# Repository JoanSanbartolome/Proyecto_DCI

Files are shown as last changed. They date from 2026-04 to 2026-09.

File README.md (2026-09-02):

# Proyecto de Diseño de PCB - STM32F746ZG






Este repositorio contiene el proyecto completo de diseño de circuito impreso (PCB) para una placa basada en el microcontrolador **STM32F746ZG**, abarcando esquemáticos, trazado de PCB (layout), archivos de fabricación, informe de diseño y una wiki técnica detallada.

---

## 📂 Estructura del Repositorio

```text
├── scr/            # Fuentes del proyecto en Altium Designer (.SchDoc, .PcbDoc, .PrjPCB, Librerías)
├── fabricacion/    # Archivos de producción (Gerber, BOM, Pick & Place, Stackup, PDF de esquemáticos)
├── informe/        # Código fuente LaTeX e imágenes del informe de diseño
├── Informe_Placa.pdf # Informe técnico final compilado en PDF
├── wiki/           # Base de conocimiento y documentación técnica estructurada
└── outputs/        # Documentos de análisis e investigación técnica intermedia
```

---

## ⚡ Especificaciones del Sistema

* **Microcontrolador:** STM32F746ZG (ARM Cortex-M7 con FPU)
* **Interfaces Periféricas:**
  * **Ethernet:** Interfaz RMII con PHY Ethernet y conector MagJack.
  * **USB:** USB OTG High-Speed / Full-Speed con pares diferenciales adaptados a 90 Ω.
  * **CAN Bus:** Transceptor CAN con protección ESD, filtro de modo común y terminación dividida (120 Ω).
  * **Memoria Flash SPI:** Memoria externa Quad-SPI con control de integridad de señal.
  * **Acondicionamiento Analógico:** Entradas ADC filtradas con amplificadores operacionales en buffer.

---

## 🛠️ Herramientas Utilizadas

* **CAD / EDA:** Altium Designer
* **Documentación Técnica:** LaTeX / Markdown
* **Control de Versiones:** Git & GitHub

---

## 📚 Wiki Técnica (`wiki/`)

La carpeta `wiki/` sirve como memoria de diseño e investigación técnica organizada en:

* **`core/`**: Arquitectura hardware, requerimientos del proyecto, reglas de layout/vias y restricciones de fabricación.
* **`peripherals/`**: Guías de diseño para Ethernet, CAN, USB, SPI y acondicionado analógico.
* **`protection/`**: Estrategias de protección ESD y sobretensión por periférico.
* **`theory/`**: Teoría de integridad de señal, desacoplo de la red PDN y guías de diseño PCB.

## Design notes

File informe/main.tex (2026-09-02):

% =============================================================
%  PREÁMBULO
% =============================================================

\documentclass[12pt,a4paper]{article}

% --- Codificación y fuente ---
\usepackage{lmodern}           % Estabiliza métricas base (fix glue units)
\usepackage[utf8]{inputenc}
\usepackage[T1]{fontenc}
\usepackage[spanish,es-tabla]{babel}
\usepackage{csquotes}  % Requerido por biblatex + babel

% --- Tipografía ---
\usepackage[sfdefault]{FiraSans}  % Fuente moderna sin conflictos con pgfplots
\usepackage{setspace}
\onehalfspacing

% --- Márgenes ---
\usepackage{geometry}
\geometry{
    a4paper,
    left=3cm,
    right=2.5cm,
    top=2.5cm,
    bottom=2.5cm,
    headheight=14.5pt  % Requerido por fancyhdr
}

% --- Matemáticas ---
\usepackage{amsmath}
\usepackage{amssymb}
\usepackage{amsthm}
\newtheorem{teorema}{Teorema}[section]
\newtheorem{definicion}{Definición}[section]

% --- Gráficos y figuras ---
\usepackage{graphicx}
\usepackage{float}
\usepackage{subcaption}
\usepackage{rotating}

% --- Tablas ---
\usepackage{tabularx}
\usepackage{booktabs}
\usepackage{array}
\usepackage{multirow}

% --- Código (Matlab) ---
\usepackage{listings}
\usepackage{xcolor}
\lstset{
    language=Matlab,
    basicstyle=\ttfamily\small,
    keywordstyle=\color{blue}\bfseries,
    commentstyle=\color{gray}\itshape,
    stringstyle=\color{orange},
    backgroundcolor=\color{lightgray!20},
    frame=single,
    breaklines=true,
    captionpos=b,
    showstringspaces=false
}

% --- Plots ---
\usepackage{pgfplots}
\pgfplotsset{compat=1.18}

% --- Miscelánea ---
\usepackage{enumerate}
\usepackage{eurosym}
\usepackage{ragged2e}

% --- Encabezados y pie de página ---
\usepackage{fancyhdr}
\pagestyle{fancy}
\fancyhf{}  % Limpia todos los campos
\fancyhead[L]{\small\itshape Diseño de Circuitos Impresos}
\fancyhead[R]{\small\itshape UPV · ETSIT}
\fancyfoot[C]{\thepage}
\renewcommand{\headrulewidth}{0.4pt}
\renewcommand{\footrulewidth}{0pt}

% --- Bibliografía ---
\usepackage[backend=biber]{biblatex}
\addbibresource{mybibliography.bib}

% --- Hipervínculos (siempre al final del preámbulo) ---
\usepackage[
    colorlinks = true,
    linkcolor  = {blue!60!black},
    citecolor  = {blue!60!black},
    urlcolor   = {blue!60!black}
]{hyperref}

% =============================================================

\begin{document}

% --- PORTADA ---
\begin{titlepage}
    \centering

    % Logo UPV
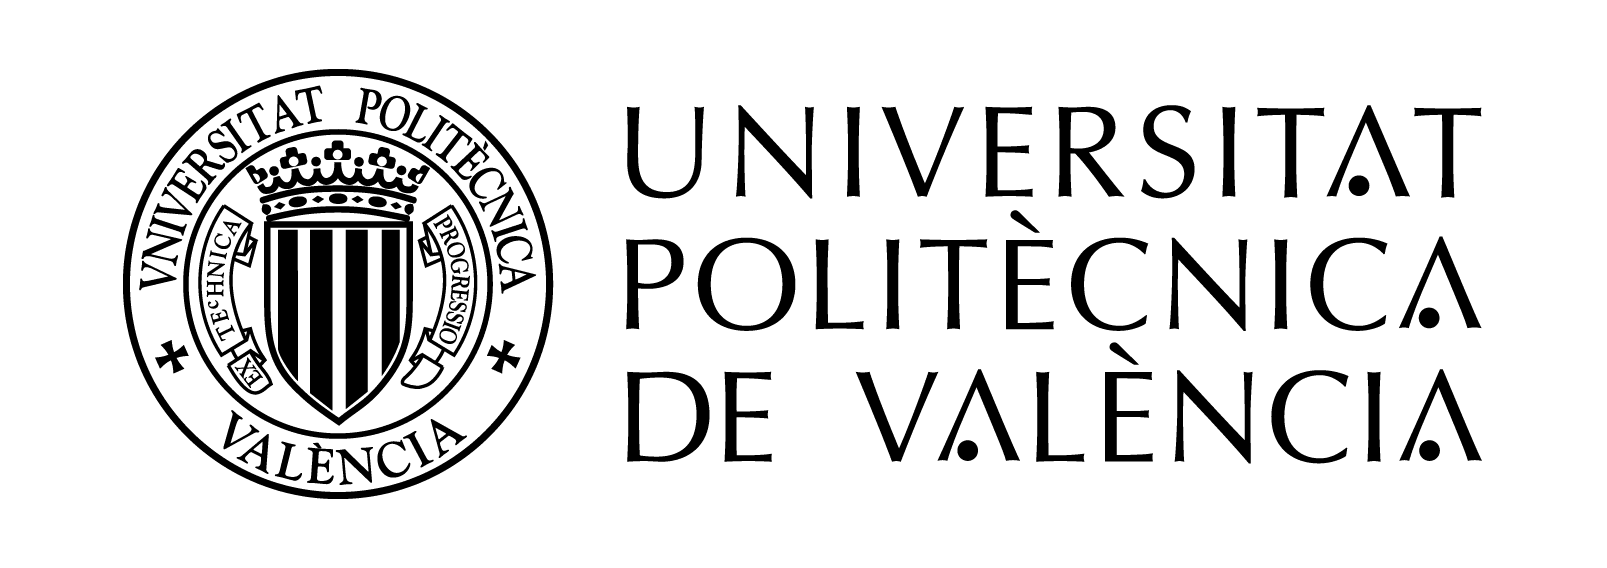
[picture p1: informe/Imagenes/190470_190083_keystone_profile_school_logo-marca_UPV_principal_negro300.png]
    

    \vspace{1.2cm}

    {\large Escuela Técnica Superior de Ingeniería de Telecomunicación}\\[0.2cm]
    {\large Universitat Politècnica de València}

    \vspace{1.8cm}
    \rule{\linewidth}{0.8pt}\\[0.5cm]

    {\Huge\bfseries Trabajo Final\\[0.4cm]
    Diseño de Circuitos Impresos}\\[0.5cm]

    \rule{\linewidth}{0.8pt}

    \vspace{1.2cm}

    {\large\itshape Informe de diseño}\\[0.3cm]
    {\normalsize Descripción del diseño, justificación de decisiones\\
    y resultados de simulación y análisis}

    \vfill

    \begin{tabular}{rl}
        \textbf{Autores:}         & Joan San Bartolomé \\
                                  & Raúl Tarazona      \\[0.6cm]
        \textbf{Asignatura:}      & Diseño de Circuitos Impresos \\[0.6cm]
        \textbf{Curso académico:} & 2025--2026
    \end{tabular}

    \vspace{1.5cm}

\end{titlepage}

% Activa encabezados a partir de aquí (la portada usa su propio estilo vacío)
\pagestyle{fancy}

\newpage
\thispagestyle{plain}  % ToC sin encabezado, solo número de página
\tableofcontents

\newpage

\section{Introducción}

El presente trabajo aborda el diseño, desarrollo y validación de una tarjeta de circuito impreso (PCB) funcional y fabricable basada en el microcontrolador de alto rendimiento STM32F746ZG. Tomando como referencia la plataforma de desarrollo comercial ST NUCLEO-F746ZG, el objetivo principal es adaptar y optimizar su arquitectura original en Altium Designer. Para ello, se simplifica el sistema mediante la eliminación de componentes redundantes y de evaluación (como el depurador integrado ST-LINK/V2-1) y se integran de forma nativa periféricos y acondicionadores de señal adaptados a aplicaciones específicas de control y conectividad.

Una de las decisiones clave de simplificación consiste en sustituir el programador/depurador ST-LINK embebido por un conector de depuración y programación SWD (Serial Wire Debug) estándar de 10 pines y paso de 100 mils. Esta decisión reduce sustancialmente el área de la placa y el consumo de potencia, permitiendo realizar la depuración mediante un programador externo o puenteando las señales desde el propio bloque ST-LINK de una placa NUCLEO comercial.

Entre los requisitos y capacidades integradas en este diseño se encuentran:
\begin{itemize}
    \item \textbf{Conectividad de red:} Interfaz Ethernet a través de un conector RJ45 de montaje inserción con LEDs de estado y magnéticos externos.
    \item \textbf{Comunicación serie y buses diferenciales:} Un puerto Micro-USB y dos transceptores CAN con red de terminación de línea dividida (Split Termination) integrada de forma permanente en el ruteado.
    \item \textbf{Adquisición de datos analógicos:} Dos canales de acondicionamiento de señal para entradas analógicas en rango de $0-10\text{ V}$, reduciéndolas y adaptándolas al rango de $0-3.3\text{ V}$ compatible con el ADC del microcontrolador.
    \item \textbf{Almacenamiento no volátil:} Una memoria SPI Flash de 2 MB para el almacenamiento de datos o firmware.
    \item \textbf{Expansión:} Un conector que expone un total de 20 líneas de E/S configurables por software: 16 de ellas son GPIO de propósito general dedicados y 2 corresponden a interfaces de comunicación serie multiplexadas (USART6 y USART7, que suman 4 líneas físicas de señal) que pueden operar alternativamente como GPIO o como puertos USART.
\end{itemize}

El diseño físico de la tarjeta se ha planteado en una tecnología de 4 capas para garantizar la integridad de las señales de alta velocidad (RMII de Ethernet, USB y CAN) y optimizar la Red de Distribución de Alimentación (PDN). Se configuran planos internos dedicados para masa (GND) y alimentación (PWR, este último partido para abastecer los diferentes niveles de tensión). El diseño cumple estrictamente las directivas de fabricación especificadas por el fabricante \textit{Lab Circuits}, restringiendo el grosor total de la placa a un máximo de $1.6\text{ mm}$ y aplicando reglas de ruteado originales para distanciar este prototipo del formato de evaluación de ST.

\section{Especificaciones de la placa}
La placa cuenta con distintos elementos que hacen que sea funcional para muchas situaciones y entornos, a continuación, se verán los diferentes elementos y funcionalidades de la placa a la vez que su construcción.

\subsection{Microcontrolador}

El cerebro de la tarjeta es el microcontrolador de muy alto rendimiento \textbf{STM32F746ZGT6}, basado en el núcleo ARM Cortex-M7 con FPU de 32 bits. Este dispositivo opera con un rango de tensión de alimentación de $1.7\text{ V}$ a $3.6\text{ V}$ y alcanza una frecuencia de reloj máxima de $216\text{ MHz}$. Dispone de $1\text{ MB}$ de memoria Flash, $320\text{ KB}$ de memoria SRAM (incluyendo memorias TCM de baja latencia) y se presenta en un encapsulado \textbf{LQFP144 de 144 pines}.

Para garantizar la estabilidad temporal del sistema, el diseño incorpora dos osciladores externos:
\begin{itemize}
    \item \textbf{Oscilador de Alta Velocidad (HSE):} Un cristal de cuarzo de $8\text{ MHz}$ conectado a los pines \texttt{PH0} y \texttt{PH1}, esencial para alimentar el PLL principal y derivar los relojes de alta precisión necesarios para Ethernet (RMII) y USB.
    \item \textbf{Oscilador de Baja Velocidad (LSE):} Un cristal de $32.768\text{ kHz}$ en los pines \texttt{PC14} y \texttt{PC15} dedicado al reloj de tiempo real (RTC) y estados de bajo consumo.
\end{itemize}

El arranque de la placa (\textit{boot}) se gestiona de forma manual mediante el pin \texttt{BOOT0}: por defecto se mantiene a nivel bajo ($0$) con una resistencia de pulso hacia abajo (\textit{pull-down}) de $10\text{ k}\Omega$ para iniciar desde la memoria Flash interna, pero cuenta con un pulsador físico que lo conecta a $3.3\text{ V}$ (a través de una resistencia en serie de $100\,\Omega$) para forzar el arranque en modo \textit{System Memory} (cargador de arranque por defecto de ST). La programación y depuración de la placa se realizan a través de un puerto SWD simplificado empleando los pines dedicados \texttt{PA13} (SWDIO) y \texttt{PA14} (SWCLK), además de la línea de reinicio activa a nivel bajo \texttt{NRST}.

\subsection{ADC y Acondicionamiento de Señal Analógica}

La placa incorpora dos canales independientes para la adquisición de señales analógicas industriales en un rango de $0-10\text{ V}$. Dado que el rango de entrada del ADC del microcontrolador está limitado a $0-3.3\text{ V}$ (tensión de referencia analógica), hemos diseñado una etapa de acondicionamiento para atenuar, filtrar y adaptar la impedancia de la señal.

\begin{figure}[H]
    \centering
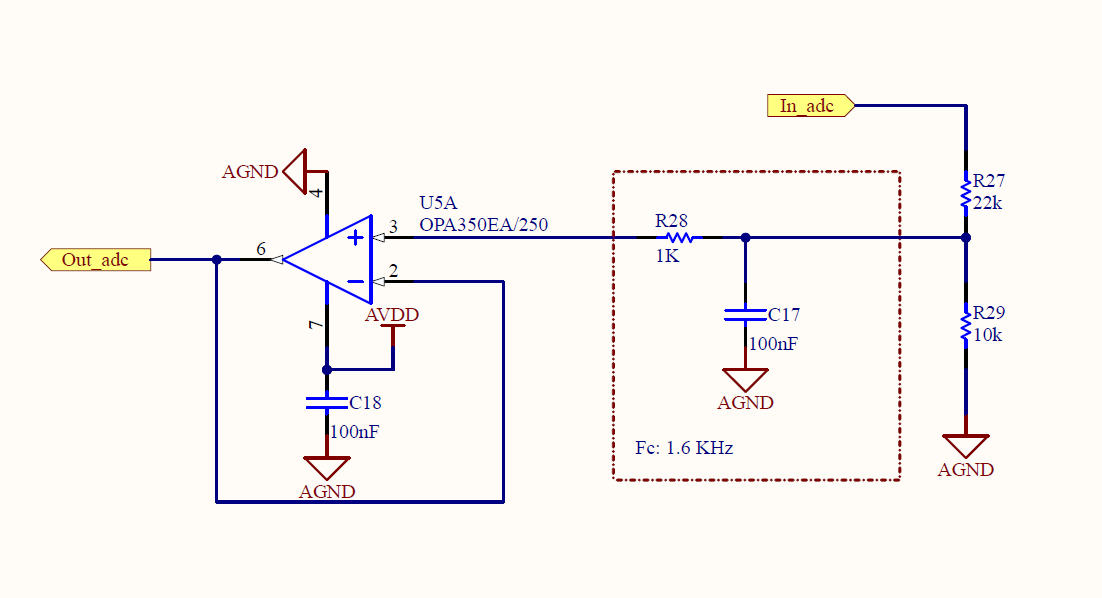
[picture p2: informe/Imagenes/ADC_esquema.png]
    
    \caption{Esquemático de la etapa de acondicionamiento analógico de entrada.}
    \label{fig:adc_esquema}
\end{figure}

El circuito de acondicionamiento de cada canal consta de las siguientes etapas:
\begin{enumerate}
    \item \textbf{Divisor de tensión atenuador:} Para adaptar la señal al rango del microcontrolador, hemos diseñado un divisor resistivo con $R_{18} = 22\text{ k}\Omega$ y $R_{19} = 10\text{ k}\Omega$. Este divisor atenúa la tensión máxima de entrada de $10\text{ V}$ a un valor seguro de $3.125\text{ V}$, protegiendo el pin de entrada y aprovechando el $95\%$ del rango dinámico del ADC.
    \item \textbf{Filtro paso bajo (Anti-aliasing):} Conectado a la entrada no inversora del amplificador operacional, este filtro RC pasivo está formado por $R_{20} = 1\text{ k}\Omega$ y $C_{12} = 100\text{ nF}$. Fija la frecuencia de corte en $f_c \approx 1.59\text{ kHz}$, adecuada para eliminar interferencias electromagnéticas y ruido de alta frecuencia de sensores industriales.
    \item \textbf{Buffer de adaptación de impedancia:} Se implementa mediante el amplificador operacional de alta precisión \textbf{OPA350EA/250} en configuración de seguidor de tensión (ganancia unidad). Al estar colocado tras el filtro, este buffer aprovecha la impedancia de entrada casi infinita de sus terminales para no cargar el filtro RC, ofreciendo a su vez una salida de muy baja impedancia idónea para alimentar el circuito de muestreo del ADC del microcontrolador ($R_{ADC} \approx 6\text{ k}\Omega$) sin errores de carga.
\end{enumerate}

Para evitar oscilaciones térmicas y consumos indeseados, el segundo canal del amplificador operacional (\texttt{U5B}), al no ser utilizado en este bloque jerárquico, se ha estabilizado conectándolo en modo seguidor con su pin no inversor unido a la masa analógica (\texttt{AGND}).

\subsubsection{Pines asignados para el ADC}

Las señales acondicionadas se conectan a los siguientes pines del microcontrolador:

\begin{table}[H]
\centering
\begin{tabular}{|c|c|l|}
\hline
\textbf{Señal} & \textbf{Pin MCU} & \textbf{Función del Periférico} \\ \hline
ADC\_CH1 & PB0 & Canal de conversión analógico-digital (ADC12\_IN8) \\ \hline
ADC\_CH2 & PB1 & Canal de conversión analógico-digital (ADC12\_IN9) \\ \hline
\end{tabular}
\caption{Asignación de pines para los canales analógicos.}
\label{tab:adc_pines}
\end{table}

\subsection{Interfaz de Comunicación CAN (Controller Area Network)}

El estándar CAN es un protocolo robusto de comunicación diferencial, idóneo para entornos industriales debido a su elevada inmunidad al ruido electromagnético. Hemos implementado en la placa dos nodos CAN independientes (\texttt{CAN1} y \texttt{CAN2}) utilizando una arquitectura jerárquica idéntica.

\begin{figure}[H]
    \centering
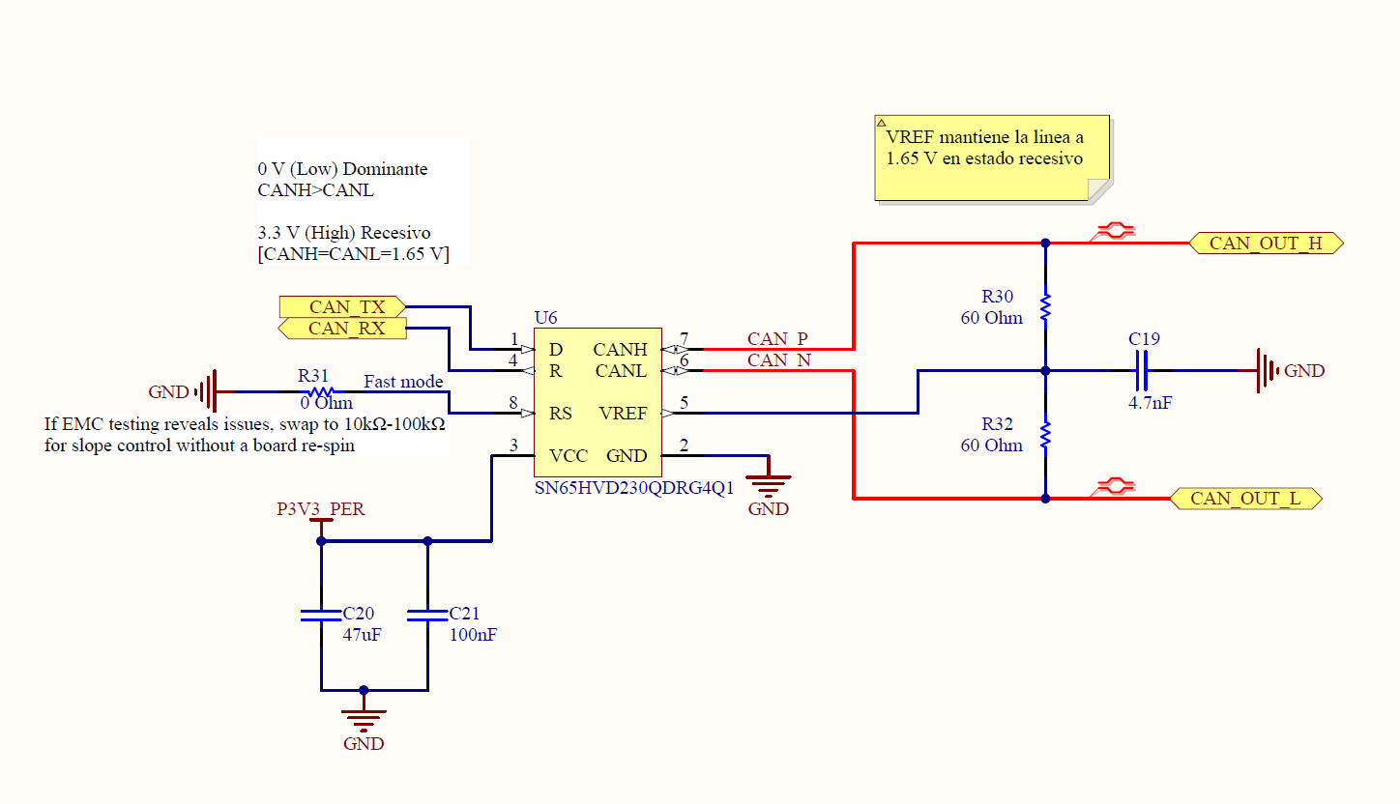
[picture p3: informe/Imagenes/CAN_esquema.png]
    
    \caption{Esquemático de la etapa del transceptor CAN e inmunidad contra ESD.}
    \label{fig:can_esquema}
\end{figure}

Para cada canal hemos tomado las siguientes decisiones de diseño de hardware:
\begin{enumerate}
    \item \textbf{Transceptor de baja potencia a $3.3\text{ V}$:} Hemos integrado el chip \textbf{SN65HVD230Q}, el cual opera directamente con la tensión lógica del microcontrolador ($3.3\text{ V}$), eliminando la necesidad de emplear desplazadores de nivel de tensión que habrían encarecido y complicado el ruteado.
    \item \textbf{Terminación de línea dividida permanente (Split Termination):} En lugar de una única resistencia de $120\,\Omega$, hemos implementado una terminación dividida integrada de forma fija y permanente por hardware, compuesta por dos resistencias de $60\,\Omega$ en serie y un condensador de $4.7\text{ nF}$ al nodo central de masa. Esta red actúa como un filtro paso bajo de modo común para disipar el ruido de alta frecuencia a tierra sin alterar la impedancia diferencial del bus. Cabe destacar que la terminación no es seleccionable ni desconectable mediante puentes (jumpers) o interruptores; es fija en el layout, lo que impone que esta tarjeta deba operar obligatoriamente en uno de los dos extremos físicos del bus CAN para evitar desadaptaciones de impedancia en la red.
    \item \textbf{Control de pendiente (RS Pin):} El pin de control de modo/pendiente (\texttt{RS}) del transceptor se conecta a masa a través de una resistencia de $0\,\Omega$ por defecto. Esto configura el transceptor en modo de alta velocidad (\textit{High-Speed Mode}). Sin embargo, la huella permite sustituir esta resistencia por un valor mayor ($10\text{ k}\Omega$ a $100\text{ k}\Omega$) para pasar a modo de control de pendiente y limitar la velocidad de transición de los flancos en caso de no cumplir con los ensayos de compatibilidad electromagnética (EMI).
    \item \textbf{Protección contra transitorios (ESD):} Hemos colocado un diodo de protección ESD bidireccional específico para CAN en encapsulado SOT-23 (\textbf{PESD2CAN}) lo más cerca posible del conector físico de salida para derivar descargas electrostáticas y transitorios directamente a la masa del sistema.
\end{enumerate}

\subsubsection{Pines asignados para el bus CAN}

La interfaz lógica entre el microcontrolador y los transceptores se realiza a través de las siguientes líneas:

\begin{table}[H]
\centering
\small
\begin{tabularx}{\textwidth}{|c|c|l|X|}
\hline
\textbf{Periférico} & \textbf{Pin MCU} & \textbf{Señal Lógica} & \textbf{Función} \\ \hline
\multirow{2}{*}{CAN1} & PD0 & CAN1\_RX & Recepción de datos lógicos del transceptor \\ \cline{2-4} 
                      & PD1 & CAN1\_TX & Transmisión de datos lógicos al transceptor \\ \hline
\multirow{2}{*}{CAN2} & PB5 & CAN2\_RX & Recepción de datos lógicos del transceptor \\ \cline{2-4} 
                      & PB6 & CAN2\_TX & Transmisión de datos lógicos al transceptor \\ \hline
\end{tabularx}
\caption{Asignación de pines de comunicación lógica para los controladores CAN.}
\label{tab:can_pines}
\end{table}

\subsection{Interfaz Micro-USB}

Hemos integrado un puerto Micro-USB de tipo AB (receptáculo \textbf{Molex 475900001}) para dotar a la tarjeta de conectividad de datos (USB 2.0 Full-Speed a $12\text{ Mbps}$) y permitir la alimentación del sistema a través del bus VBUS del host.

\begin{figure}[H]
    \centering
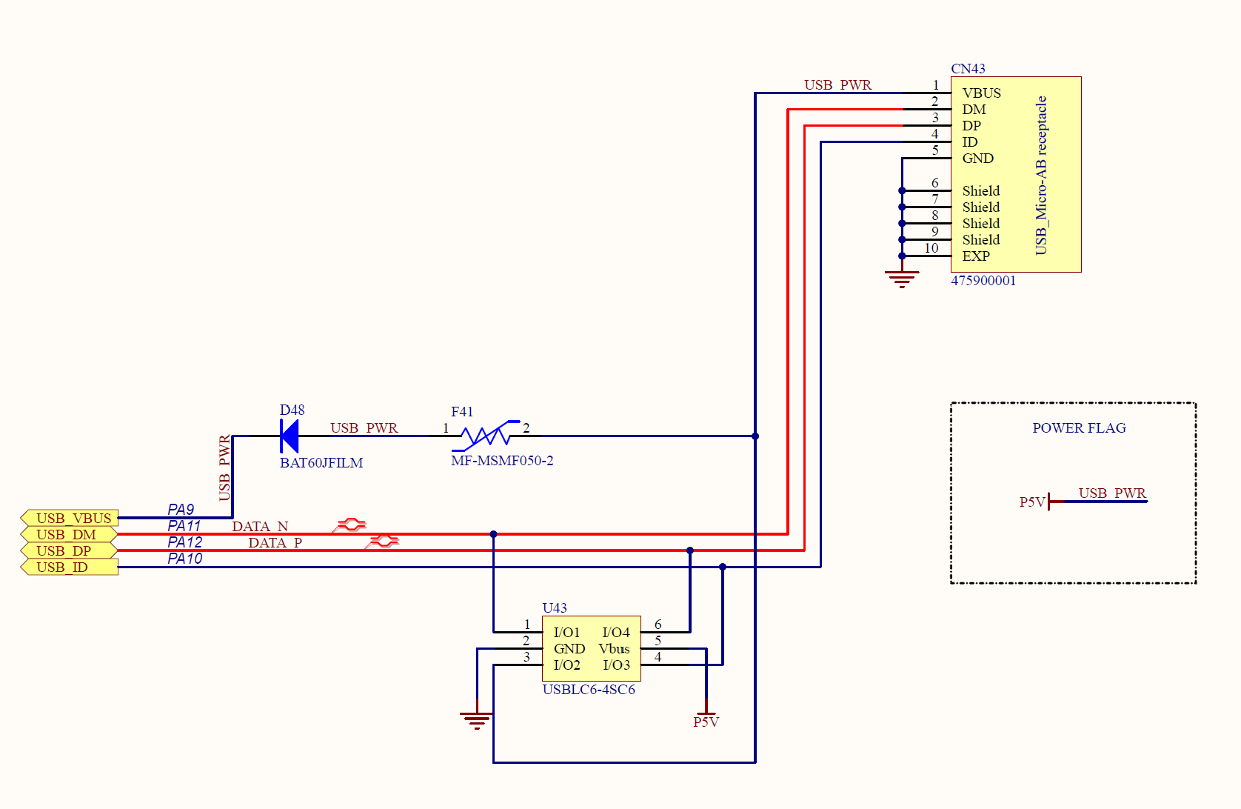
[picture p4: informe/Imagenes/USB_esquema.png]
    
    \caption{Esquemático de la etapa del conector USB con sus elementos de protección y filtrado.}
    \label{fig:usb_esquema}
\end{figure}

El diseño físico y eléctrico de esta interfaz se fundamenta en las siguientes decisiones de hardware:
\begin{enumerate}
    \item \textbf{Adaptación de impedancia diferencial:} Las líneas de datos $D+$ y $D-$ se rutan como par diferencial directamente desde el conector hacia los pines del microcontrolador, sin resistencias serie de terminación externas. Hemos aprovechado que el transceptor Full-Speed integrado en el microcontrolador STM32F746ZGT6 cuenta con una impedancia de salida adaptada por hardware. El par se ha diseñado para presentar una impedancia diferencial de \textbf{$90\,\Omega \pm 10$\%}.
    \item \textbf{Protección contra descargas electrostáticas (ESD):} Para proteger las líneas de datos de transitorios de alta velocidad sin degradar la señal por efecto capacitivo, hemos colocado el circuito integrado de capacitancia ultra-baja ($C_{in} \approx 1\text{ pF}$) \textbf{USBLC6-4SC6} lo más cerca posible del conector físico. Las pistas del par de datos se rutan pasando directamente a través de las patillas del integrado para evitar stubs en el diseño de la pista.
    \item \textbf{Seguridad de alimentación (VBUS):} La entrada de alimentación desde el puerto USB (\texttt{USB\_PWR}) cuenta con dos niveles de protección activa:
        \begin{itemize}
            \item Un fusible rearmable PTC de $0.5\text{ A}$ (\textbf{MF-MSMF050-2}) para proteger al puerto del host frente a cortocircuitos o sobrecorrientes en nuestra placa.
            \item Un diodo Schottky \textbf{BAT60JFILM} que previene corrientes de retorno inversas hacia el host cuando la placa se alimenta mediante otra fuente de alimentación externa.
        \end{itemize}
    \item \textbf{Sensado de VBUS:} La línea VBUS se conecta al pin de entrada analógica/digital \texttt{PA9} del microcontrolador a través de una resistencia en serie de $10\text{ k}\Omega$. Aprovechando que el pin \texttt{PA9} es tolerante a $5\text{ V}$, esta resistencia actúa como un limitador de corriente para salvaguardar la entrada ante picos de tensión o transitorios en la línea de alimentación USB, permitiendo al firmware detectar la presencia del host y gestionar el stack de comunicaciones de forma dinámica.
\end{enumerate}

\subsubsection{Cálculo de Impedancia del Par Diferencial USB}

Para asegurar la integridad de la señal en el bus de datos USB, hemos realizado el cálculo geométrico del par diferencial utilizando el motor de cálculo \textit{SIMBEOR} integrado en el gestor de pila de capas (\textit{Layer Stack Manager}) de Altium Designer. 

Tomando como base la pila de capas de $1.6\text{ mm}$ de \textit{Lab Circuits}, los parámetros geométricos y eléctricos que definen el par diferencial de datos USB ($90\,\Omega$) se muestran en la Tabla~\ref{tab:usb_diffpair_params}:

\begin{table}[H]
\centering
\small
\begin{tabular}{|l|c|}
\hline
\textbf{Parámetro del Par Diferencial} & \textbf{Valor de Diseño} \\ \hline
Impedancia Objetivo ($Z_{diff}$) & $90\,\Omega$ \\ \hline
Tolerancia de Diseño & $15$\% \\ \hline
Ancho de Pista ($W1$ / $W2$) & $0.19\text{ mm}$ ($\approx 7.5\text{ mils}$) \\ \hline
Separación de Pistas (Gap, $G$) & $0.15\text{ mm}$ ($\approx 6\text{ mils}$) \\ \hline
Grosor de la Máscara de Soldadura ($C1$ / $C2$) & $0.0254\text{ mm}$ ($1\text{ mil}$) \\ \hline
\textbf{Impedancia Diferencial Calculada ($Z_{diff}$)} & $\mathbf{94.91\,\Omega}$ \\ \hline
Desviación de Impedancia Obtenida & $5.46$\% (dentro de límites) \\ \hline
Retardo de Propagación (Delay) & $5.90\text{ ns/m}$ \\ \hline
\end{tabular}
\caption{Parámetros de diseño calculados para el par diferencial USB de 90 Ohm.}
\label{tab:usb_diffpair_params}
\end{table}

\subsubsection{Pines asignados para el puerto USB}

El mapeo de pines entre el microcontrolador y el conector USB se detalla a continuación:

\begin{table}[H]
\centering
\small
\begin{tabularx}{\textwidth}{|c|c|l|X|}
\hline
\textbf{Señal} & \textbf{Pin MCU} & \textbf{Señal Lógica} & \textbf{Función del Periférico} \\ \hline
USB\_VBUS & PA9 & OTG\_FS\_VBUS & Entrada de detección de presencia de tensión de VBUS \\ \hline
USB\_ID & PA10 & OTG\_FS\_ID & Línea de detección de modo Host/Device (OTG) \\ \hline
USB\_DM & PA11 & OTG\_FS\_DM & Línea de datos diferencial negativa (D-) \\ \hline
USB\_DP & PA12 & OTG\_FS\_DP & Línea de datos diferencial positiva (D+) \\ \hline
\end{tabularx}
\caption{Asignación de pines para la interfaz Micro-USB.}
\label{tab:usb_pines}
\end{table}

\subsection{Sistema de Alimentación y Red de Distribución de Potencia (PDN)}

La tarjeta se alimenta primariamente a través del puerto Micro-USB ($5\text{ V}$). Dado que la electrónica principal (núcleo del microcontrolador, transceptores y periféricos) funciona a un nivel nominal de $3.3\text{ V}$, hemos implementado una etapa de regulación lineal y una red de desacoplo distribuida (PDN) para asegurar el suministro limpio y estable de energía.

\begin{figure}[H]
    \centering
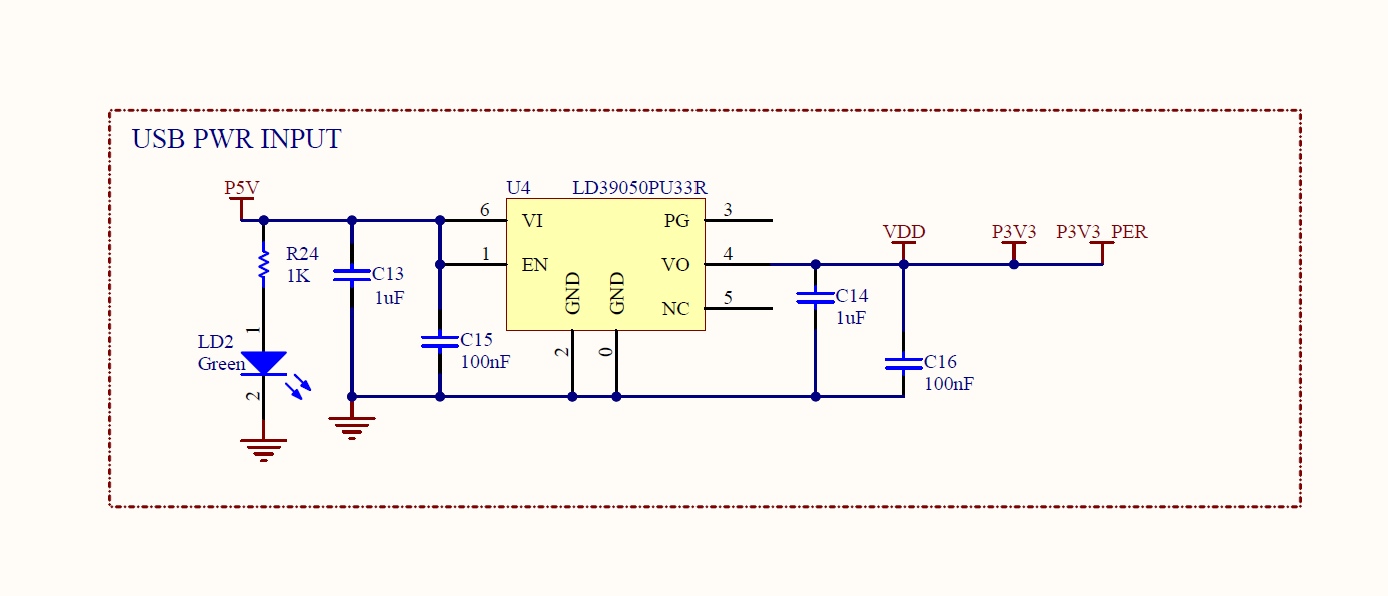
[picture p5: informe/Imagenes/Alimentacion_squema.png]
    
    \caption{Esquema de la etapa del regulador LDO de 3.3V y filtrado de alimentación.}
    \label{fig:alimentacion_esquema}
\end{figure}

Las decisiones de diseño tomadas para la red de alimentación son las siguientes:
\begin{enumerate}
    \item \textbf{Regulador LDO de alta eficiencia:} Hemos seleccionado el regulador de bajo descarte (LDO) \textbf{LD39050PU33R} de STMicroelectronics en encapsulado DFN-6, capaz de suministrar hasta $500\text{ mA}$ con una excelente relación de rechazo al rizado (PSRR). Este regulador incorpora una patilla de \textit{Power Good} (PG) para verificar la correcta estabilidad de la tensión y un pin de habilitación (\texttt{EN}) para control lógico. Su salida está estabilizada mediante una red de condensadores de $1\,\mu\text{F}$ y $100\text{ nF}$.
    \item \textbf{Desacoplo local del microcontrolador:} Para minimizar la inductancia del bucle de retorno y atenuar el ruido de conmutación de alta frecuencia, hemos colocado un condensador de desacoplo cerámico de $100\text{ nF}$ (encapsulado 0402) inmediatamente adyacente a cada uno de los 12 pines de alimentación digital \texttt{VDD} del microcontrolador.
    \item \textbf{Condensadores de almacenamiento masivo (Bulk):} Para responder ante transitorios de corriente rápidos del núcleo a $216\text{ MHz}$, hemos distribuido estratégicamente condensadores bulk en los extremos de la placa: un condensador de $4.7\,\mu\text{F}$ en las proximidades del pin 95 y otro de $10\,\mu\text{F}$ (X5R, 0805) junto al pin 72.
    \item \textbf{Regulación interna del núcleo (VCAP):} El regulador interno de $1.2\text{ V}$ para el núcleo digital del microcontrolador requiere estabilidad externa obligatoria. Para ello, hemos conectado dos condensadores cerámicos de bajo ESR de $2.2\,\mu\text{F}$ desde los pines dedicados \texttt{VCAP\_1} y \texttt{VCAP\_2} directamente a masa.
    \item \textbf{Aislamiento del dominio analógico ($V_{DDA}$ / $V_{REF+}$):} Para evitar el acoplamiento de ruido digital de alta frecuencia en las medidas del ADC, hemos aislado la alimentación analógica mediante una perla de ferrita de muy baja resistencia en continua (\textbf{Murata BLM18PG121SN1D}), acompañada de un desacoplo local de $1\,\mu\text{F}$ y $100\text{ nF}$. La baja DCR ($< 50\text{ m}\Omega$) garantiza una caída de tensión insignificante ($< 0.15\text{ mV}$), preservando la precisión de las lecturas analógicas.
\end{enumerate}

\subsubsection{Pines de alimentación del microcontrolador}

La distribución física de las patillas de alimentación y masa del microcontrolador STM32F746ZGT6 se describe en la siguiente tabla:

\begin{table}[H]
\centering
\small
\begin{tabularx}{\textwidth}{|l|c|X|}
\hline
\textbf{Dominio de Potencia} & \textbf{Símbolo Pin} & \textbf{Pines Físicos (LQFP144)} \\ \hline
Alimentación Digital & VDD & 16, 30, 39, 52, 62, 72, 84, 95, 108, 121, 131, 144 \\ \hline
Masa Común & VSS & 15, 31, 38, 51, 61, 71, 83, 94, 107, 120, 130, 143 \\ \hline
Alimentación Analógica & VDDA & 33 \\ \hline
Masa Analógica & VSSA & 32 \\ \hline
Tensión de Referencia Analógica & VREF+ / VREF- & 35 / 34 \\ \hline
Alimentación de Batería & VBAT & 6 \\ \hline
Condensadores del Regulador Núcleo & VCAP\_1 / VCAP\_2 & 71 / 106 \\ \hline
\end{tabularx}
\caption{Pines físicos de alimentación y referencia en encapsulado LQFP144.}
\label{tab:alimentacion_pines}
\end{table}

\subsection{Interfaz de Red Ethernet}

Hemos incorporado conectividad Ethernet 10/100Base-TX mediante el uso del microcontrolador en modo MAC y un transceptor de capa física (PHY) externo de bajo consumo \textbf{LAN8742A-CZ-TR} en encapsulado QFN-24. La conexión física se realiza a través de un conector RJ45 con transformador magnético integrado (\textbf{KRJ-CB4.2GYZNL}).

El diseño de esta etapa se basa en las siguientes decisiones técnicas de hardware:
\begin{enumerate}
    \item \textbf{Uso de interfaz RMII (Reduced Media Independent Interface):} Para reducir el número de patillas necesarias en el microcontrolador de 17 (modo MII) a 9, hemos configurado la comunicación en modo RMII. La señal de reloj de referencia de $50\text{ MHz}$ (\texttt{RMII\_REF\_CLK}) es generada por el propio PHY a partir de un cristal local de $25\text{ MHz}$ y se introduce en el pin \texttt{PA1} del microcontrolador.
    \item \textbf{Aislamiento galvánico bajo los magnéticos:} Para evitar el acoplamiento de ruido electromagnético de modo común procedente de la línea de red cableada hacia los planos internos de alimentación y masa de la placa, hemos definido un área de exclusión de cobre (\textit{keep-out}) en todas las capas de la PCB por debajo de la zona ocupada por los transformadores magnéticos del conector RJ45.
    \item \textbf{Protección contra transitorios:} Hemos colocado un array de diodos de capacitancia ultra-baja \textbf{USBLC6-4SC6} adyacente a las líneas diferenciales del conector para filtrar picos de ESD antes de que alcancen el lado del transceptor.
\end{enumerate}

\subsubsection{Cálculo de Impedancia del Par Diferencial Ethernet}

Las líneas del bus MDI que enlazan el transceptor PHY con el conector RJ45 (\texttt{TX+/TX-} y \texttt{RX+/RX-}) requieren un control de impedancia diferencial de **$100\,\Omega$**. Hemos calculado la geometría del par en base a la pila de capas de $1.6\text{ mm}$ de \textit{Lab Circuits} utilizando el motor de cálculo \textit{SIMBEOR} de Altium Designer. Los valores resultantes se detallan en la Tabla~\ref{tab:ethernet_diffpair_params}:

\begin{table}[H]
\centering
\small
\begin{tabular}{|l|c|}
\hline
\textbf{Parámetro del Par Diferencial} & \textbf{Valor de Diseño} \\ \hline
Impedancia Objetivo ($Z_{diff}$) & $100\,\Omega$ \\ \hline
Tolerancia de Diseño & $10$\% \\ \hline
Ancho de Pista ($W1$ / $W2$) & $0.182\text{ mm}$ ($\approx 7.2\text{ mils}$) \\ \hline
Separación de Pistas (Gap, $G$) & $0.180\text{ mm}$ ($\approx 7.1\text{ mils}$) \\ \hline
Grosor de la Máscara de Soldadura ($C1$ / $C2$) & $0.0254\text{ mm}$ ($1\text{ mil}$) \\ \hline
\textbf{Impedancia Diferencial Calculada ($Z_{diff}$)} & $\mathbf{99.99\,\Omega}$ \\ \hline
Desviación de Impedancia Obtenida & $0.01$\% \\ \hline
Retardo de Propagación (Delay) & $5.91\text{ ns/m}$ \\ \hline
\end{tabular}
\caption{Parámetros de diseño calculados para el par diferencial Ethernet de 100 Ohm.}
\label{tab:ethernet_diffpair_params}
\end{table}

\subsubsection{Pines asignados para el bus Ethernet}

Las señales lógicas del bus de control y datos RMII están distribuidas de acuerdo con la siguiente tabla:

\begin{table}[H]
\centering
\small
\begin{tabularx}{\textwidth}{|l|c|X|}
\hline
\textbf{Señal RMII} & \textbf{Pin MCU} & \textbf{Función de la Señal} \\ \hline
RMII\_REF\_CLK & PA1 & Reloj de referencia de 50 MHz para sincronización \\ \hline
RMII\_MDIO & PA2 & Gestión de datos bidireccional (SMI) \\ \hline
RMII\_MDC & PC1 & Reloj de la interfaz de gestión (SMI) \\ \hline
RMII\_CRS\_DV & PA7 & Detección de portadora y validación de datos recibidos \\ \hline
RMII\_RXD0 & PC4 & Línea 0 de recepción de datos \\ \hline
RMII\_RXD1 & PC5 & Línea 1 de recepción de datos \\ \hline
RMII\_TX\_EN & PG11 & Habilitación de transmisión de datos \\ \hline
RMII\_TXD0 & PG13 & Línea 0 de transmisión de datos \\ \hline
RMII\_TXD1 & PB13 & Línea 1 de transmisión de datos \\ \hline
nRST (PHY) & Pin 25 & Línea de reinicio por hardware del microcontrolador (NRST) \\ \hline
\end{tabularx}
\caption{Asignación de pines para la interfaz Ethernet en modo RMII.}
\label{tab:ethernet_pines}
\end{table}

\subsection{Conectores}
Además de las interfaces de comunicación específicas, hemos integrado conectores de expansión y terminales de conexión externa para interactuar con señales analógicas y digitales del sistema:

\begin{enumerate}
    \item \textbf{Conector de Expansión General (CN41):} Se trata de un conector macho de cabezal de $18\times2$ vías (paso de $2.54\,\text{mm}$) que expone un total de 20 líneas de E/S configurables por software. Analizando detalladamente el esquemático, se observa que este puerto proporciona 16 líneas de propósito general (GPIO) dedicadas (puertos C, D y G) y 2 interfaces de comunicación serie multiplexadas (USART6 y USART7, que ocupan un total de 4 líneas físicas de señal: TX/RX de cada una). Estas 4 líneas se pueden utilizar alternativamente como puertos serie o como líneas GPIO de entrada/salida convencionales según la configuración del firmware.
    \item \textbf{Conector de Depuración SWD (CN42):} Un cabezal de $6\times1$ vías utilizado para la programación y depuración del STM32F746ZG, exponiendo las líneas de depuración esenciales (SWCLK, SWDIO, SWO y el pin de reinicio NRST).
    \item \textbf{Terminales de Entrada Analógica (J41):} Un bloque de bornes de tornillo Weidmüller, modelo \textbf{1845040000} (paso de $3.50\,\text{mm}$ y entrada a $90^\circ$), que proporciona una conexión segura para las dos entradas analógicas acondicionadas de $0-10\,\text{V}$.
    \item \textbf{Conectores de Bus CAN (J42 y J43):} Conectores macho de 2 pines JST tipo \textbf{B2B-EH-A(LF)(SN)} para las conexiones físicas de los buses de comunicación CAN1 y CAN2.
\end{enumerate}

\subsubsection{Estrategia de Protección de Entradas/Salidas}
Para garantizar la inmunidad del microcontrolador frente a eventos externos de sobretensión y descargas electrostáticas (ESD), hemos diseñado e implementado un esquema de protección multietapa para todas las líneas de entrada y salida expuestas:
\begin{itemize}
    \item \textbf{Protección ESD Primaria (TVS Diodes):} Inmediatamente después del conector físico, hemos colocado matrices de diodos de supresión de tensiones transitorias (TVS) de 4 canales bidireccionales, modelo \textbf{ESDA6V1BC6} (D46, D47, D48 y D49). Estos dispositivos poseen una tensión de ruptura de $6.1\,\text{V}$, ideal para proteger pines tolerantes a $5\,\text{V}$ sin distorsionar señales de datos. Su ubicación física adyacente al conector y su baja inductancia de conexión a masa aseguran que los transitorios se deriven a tierra de forma instantánea.
    \item \textbf{Protección de Línea CAN:} Los puertos J42 y J43 disponen de diodos de protección TVS específicos de bus CAN de alta inmunidad y baja capacitancia modelo \textbf{PESD2CANFD24V-TR} (D44 y D45), situados en paralelo con las líneas diferenciales CAN\_H y CAN\_L.
    \item \textbf{Limitación de Corriente Secundaria (Resistencias Serie):} Entre las matrices TVS y los pines de entrada del microcontrolador, hemos introducido resistencias de protección en serie. Para las líneas de propósito general expuestas en CN41, hemos seleccionado resistencias de $100\,\Omega$ (R58 a R65 para el puerto D, y R69 a R73 para los puertos G/C). Estas resistencias limitan la corriente transitoria residual que pudiera llegar al microcontrolador a un nivel seguro inferior al límite de conducción de los diodos de fijación (clamping diodes) internos del STM32F746ZG ($I_{IN} < 10\,\text{mA}$).
    \item \textbf{Líneas de Depuración SWD:} Las señales del conector CN42 (SWCLK, SWDIO, SWO y NRST) se conectan al MCU mediante resistencias en serie de $22\,\Omega$ (R43, R44, R45 y R46), las cuales reducen sobreoscilaciones (overshoot/undershoot) y previenen reflexiones de alta frecuencia causadas por la impedancia de los cables de programación.
\end{itemize}

La topología de ruteado implementada respeta estrictamente la secuencia física: \textbf{[Conector Exterior]} $\rightarrow$ \textbf{[Diodo TVS ESDA6V1BC6 / PESD2CANFD]} $\rightarrow$ \textbf{[Resistencia Serie]} $\rightarrow$ \textbf{[Pin del MCU]}.

\subsubsection{Asignación de Pines del Conector General (CN41)}

La Tabla~\ref{tab:conectores_pines} muestra el mapeo detallado de cada pin del conector CN41, incluyendo las señales de alimentación y tierra correspondientes:

\begin{table}[H]
\centering
\small
\begin{tabularx}{\textwidth}{|X|c|c|X|}
\hline
\multicolumn{2}{|c|}{\textbf{LADO IMPAR (Izquierda)}} & \multicolumn{2}{c|}{\textbf{LADO PAR (Derecha)}} \\ \hline
\textbf{Señal del Esquema (Pin MCU)} & \textbf{Pin} & \textbf{Pin} & \textbf{Señal del Esquema (Pin MCU)} \\ \hline
GND & 1 & 2 & GND \\ \hline
P5V & 3 & 4 & P5V \\ \hline
P3V3 & 5 & 6 & P3V3 \\ \hline
GND & 7 & 8 & GND \\ \hline
PinG4 (PG4) & 9 & 10 & PinC6 (PC6) \\ \hline
PinG5 (PG5) & 11 & 12 & PinG8 (PG8) \\ \hline
GND & 13 & 14 & GND \\ \hline
PinG2 (PG2) & 15 & 16 & PinG7 (PG7) \\ \hline
PinG3 (PG3) & 17 & 18 & PinG6 (PG6) \\ \hline
PinD14 (PD14) & 19 & 20 & PinD11 (PD11) \\ \hline
GND & 21 & 22 & GND \\ \hline
PinD15 (PD15) & 23 & 24 & PinD10 (PD10) \\ \hline
PinD12 (PD12) & 25 & 26 & PinD9 (PD9) \\ \hline
PinD13 (PD13) & 27 & 28 & PinD8 (PD8) \\ \hline
GND & 29 & 30 & GND \\ \hline
USART7\_TX (PE8) & 31 & 32 & USART6\_TX (PG14) \\ \hline
USART7\_RX (PE7) & 33 & 34 & USART6\_RX (PG9) \\ \hline
GND & 35 & 36 & GND \\ \hline
\end{tabularx}
\caption{Distribución de pines del conector de expansión general (CN41) y su disposición de doble fila simétrica.}
\label{tab:conectores_pines}
\end{table}

\subsection{Memoria Flash}
Para el almacenamiento de firmware auxiliar, archivos de configuración o parámetros no volátiles del sistema, hemos incorporado una memoria Flash externa de tipo SPI NOR de $4\,\text{Mbit}$ ($512\,\text{KB}$), modelo \textbf{SST25VF040B-50-4I-S2AF} (encapsulado SOIC-8). Este chip se comunica con el microcontrolador a través del bus serie síncrono SPI2.

\subsubsection{Criterios de Diseño para la Integridad de la Señal SPI}
Debido a la alta frecuencia de conmutación del bus SPI (que puede operar hasta $50\,\text{MHz}$), hemos tomado las siguientes precauciones en el diseño del circuito:
\begin{itemize}
    \item \textbf{Amortiguación del Reloj (SCK):} Hemos colocado una resistencia amortiguadora en serie de $33\,\Omega$ (R32) en la línea de reloj (SPI\_CLK / SCK), ubicada en la cercanía física del microcontrolador (emisor). Esto permite controlar la impedancia de salida del driver, reducir la velocidad de subida del flanco (slew rate) y prevenir rebotes o sobreoscilaciones destructivas que podrían causar falsas transiciones de reloj en la memoria.
    \item \textbf{Resistencias de Pull-Up en Control:} Hemos colocado resistencias de pull-up de $10\,\text{k}\Omega$ a la línea de $3.3\,\text{V}$ (R31) en las líneas de control activas a nivel bajo: \textbf{CE\#} (Chip Enable), \textbf{WP\#} (Write Protect) y \textbf{HOLD\#} (Hold). Estas resistencias de pull-up aseguran que durante el arranque del microcontrolador (cuando sus pines se encuentran en alta impedancia), la memoria permanezca deshabilitada y protegida contra cualquier escritura o borrado accidental.
    \item \textbf{Desacoplo local:} Hemos colocado un condensador de desacoplo de $100\,\text{nF}$ (C61) en paralelo al terminal de alimentación VDD (Pin 8) a masa, ubicado lo más próximo posible al integrado.
\end{itemize}

La asignación de pines y conexiones físicas para la memoria Flash SPI se detallan en la Tabla~\ref{tab:flash_pines}:

\begin{table}[H]
\centering
\small
\begin{tabularx}{\textwidth}{|l|c|c|X|}
\hline
\textbf{Señal del Esquema} & \textbf{Pin Memoria (SOIC-8)} & \textbf{Pin MCU} & \textbf{Descripción y Detalles de Diseño} \\ \hline
SPI\_CS / CE\# & Pin 1 & PB12 & Habilitación de chip (Chip Enable). Dispone de un pull-up de $10\,\text{k}\Omega$ a 3.3V. \\ \hline
SPI\_MISO / SO & Pin 2 & PB14 & Salida de datos serie (Serial Data Output). Conexión directa a MISO del bus SPI2. \\ \hline
WP\# & Pin 3 & -- & Entrada de protección contra escritura. Conectada a +3.3 V mediante pull-up de $10\,\text{k}\Omega$. \\ \hline
GND / VSS & Pin 4 & -- & Terminal de referencia de masa. \\ \hline
SPI\_MOSI / SI & Pin 5 & PB15 & Entrada de datos serie (Serial Data Input). Conexión directa a MOSI del bus SPI2. \\ \hline
SPI\_CLK / SCK & Pin 6 & PB10 & Reloj serie (Serial Clock). Conectado mediante resistencia amortiguadora serie de $33\,\Omega$. \\ \hline
HOLD\# & Pin 7 & -- & Entrada de pausa temporal de bus. Conectada a +3.3 V mediante pull-up de $10\,\text{k}\Omega$. \\ \hline
VDD & Pin 8 & -- & Alimentación a +3.3 V, desacoplada localmente con condensador cerámico de $100\,\text{nF}$. \\ \hline
\end{tabularx}
\caption{Mapeo de pines y criterios de conexión para la memoria Flash SPI externa SST25VF040B.}
\label{tab:flash_pines}
\end{table}

\subsection{Distribución y Emplazado de Componentes (Placement)}

Para optimizar el comportamiento térmico, electromagnético y la integridad de las señales en la placa, hemos diseñado una distribución espacial (placement) basada en la segregación estricta de componentes por bloques funcionales. El emplazado de componentes respeta el flujo natural de las señales lógicas y de potencia, minimizando la longitud de las trazas críticas y evitando el acoplamiento cruzado de ruido (crosstalk) entre bloques de alta frecuencia, circuitos analógicos de precisión y convertidores de potencia.

En la Figura~\ref{fig:layout_placement} se muestra el plano de distribución y emplazado físico de componentes en el plano de la serigrafía de ensamblaje (Assembly Drawing) de la PCB:

\begin{figure}[H]
    \centering
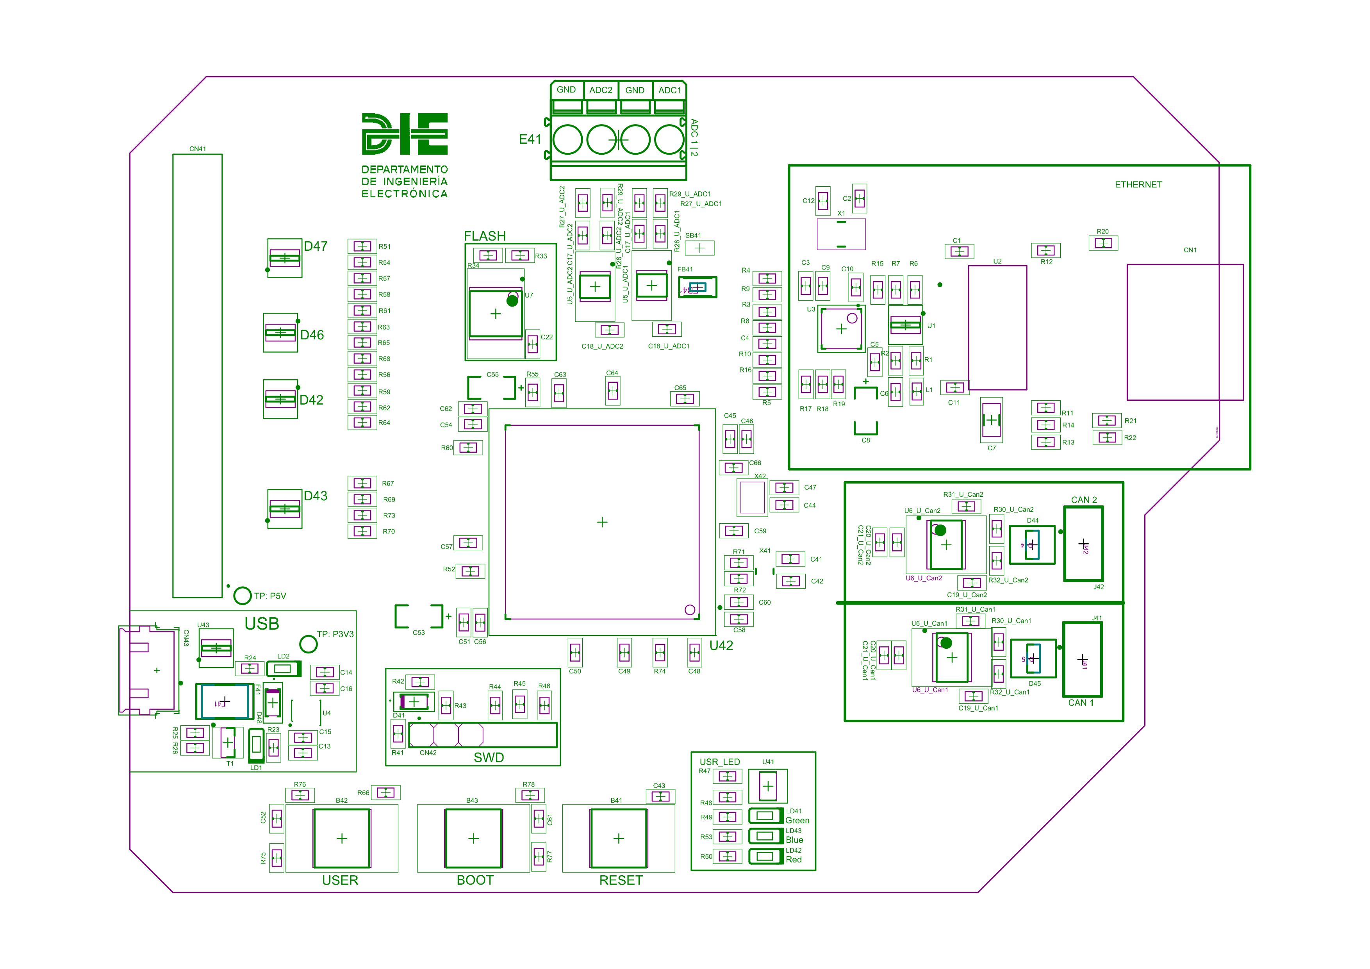
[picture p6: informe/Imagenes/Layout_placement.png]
    
    \caption{Plano de distribución espacial y emplazado de componentes (Placement) en la PCB.}
    \label{fig:layout_placement}
\end{figure}

El diseño físico de la distribución de componentes en la PCB se ha estructurado en torno a las siguientes decisiones de ingeniería de layout:

\begin{enumerate}
    \item \textbf{Microcontrolador Central (U42):} Hemos ubicado el STM32F746ZGT6 en el centro geométrico de la placa. Esta posición central equidistante facilita un ruteado simétrico y balanceado en estrella de los buses de datos de alta velocidad y las líneas analógicas hacia los extremos. El anillo de condensadores de desacoplo de alimentación digital se coloca en la capa superior (Top) inmediatamente adyacente a cada pin de alimentación para minimizar la inductancia intrínseca de conexión.
    \item \textbf{Zona Analógica de Precisión (E41 y Acondicionamiento):} Situada en el borde superior central de la placa. Alberga el bloque de bornes Weidmüller E41 y las etapas de amplificación y filtrado analógico (U5\_U\_ADC1 y U5\_U\_ADC2). Esta zona analógica está aislada físicamente de los transceptores lógicos de alta conmutación (USB y Ethernet) y de las fuentes conmutadas para evitar la inducción de ruido térmico o electromagnético en los canales del ADC.
    \item \textbf{Bloque de Red Ethernet (PHY y RJ45):} Emplazado de forma exclusiva en la esquina superior derecha de la placa. La PHY LAN8742A (U2) y su oscilador local de $25\,\text{MHz}$ (X1) se disponen adyacentes al jack RJ45 (CN1) con magnetizados integrados. Esta cercanía minimiza la longitud de los pares diferenciales críticos MDI y las trazas de reloj de alta frecuencia, reduciendo la emisión por radiación de la interfaz física de red.
    \item \textbf{Módulos de Transmisión CAN (CAN 1 y CAN 2):} Ubicados en el borde derecho inferior de la placa de forma simétrica. Los transceptores SN65HVD230Q (U6\_U\_Can1/2) y los conectores JST J41/J42 de bus de campo se sitúan en paralelo en el extremo exterior. Las protecciones TVS PESD2CANFD24V-TR (D44/D45) se emplazan directamente en la entrada del conector, desviando las descargas electrostáticas a tierra de forma inmediata y evitando su propagación por la placa.
    \item \textbf{Etapa de Alimentación y Puerto USB:} Colocada en la esquina inferior izquierda de la placa. Agrupa el conector Micro-USB (CN43), el regulador lineal de baja caída LDO LD39050 (U4) y los dispositivos de protección VBUS (polyfuse F41 y diodo Schottky D48). Al agrupar el bloque de potencia en un extremo, el calor generado por la disipación del LDO no se propaga hacia el microcontrolador o la zona analógica de precisión, mejorando la estabilidad térmica general.
    \item \textbf{Interfaz de Depuración (SWD):} El conector CN42 (SWD) se encuentra situado en la parte inferior central de la placa, cerca de la base del microcontrolador. Esta disposición acorta el camino de las líneas de programación de alta velocidad SWDIO y SWCLK, disminuyendo la radiación EMI emitida por el programador.
    \item \textbf{Periféricos de Usuario y Memoria Flash:} Los tres pulsadores físicos (USER B42, BOOT B43, RESET B41) y los diodos LED indicadores se sitúan a lo largo del borde inferior para facilitar el acceso manual. Por su parte, la memoria Flash externa SPI (U7) y sus líneas de control se emplazan inmediatamente por encima del microcontrolador para reducir la longitud del bus SPI2 a menos de $15\,\text{mm}$.
\end{enumerate}

\subsection{Stack-up}

Para garantizar la integridad de señal en los buses de datos de alta velocidad y cumplir con las directrices de compatibilidad electromagnética (EMC), hemos diseñado un stack-up controlado de 4 capas. El uso de una estructura multicapa permite definir planos de referencia de masa y alimentación continuos y adyacentes a las capas externas de señal, lo cual minimiza el área del lazo de retorno de corriente, reduce la inductancia parásita del plano y bloquea la radiación electromagnética (EMI) de modo común.

Hemos estructurado las capas de la placa de la siguiente manera:
\begin{itemize}
    \item \textbf{Capa 1 (Top Layer):} Capa externa de ruteado de señales de alta velocidad y periféricos principales.
    \item \textbf{Capa 2 (Int1 - GND):} Plano de referencia de masa continuo para el camino de retorno de señales de la capa Top.
    \item \textbf{Capa 3 (Int2 - PWR):} Plano de alimentación segmentado en las diferentes tensiones necesarias ($3.3\,\text{V}$, $3.3\,\text{V}$ analógico y masa auxiliar en ciertas regiones).
    \item \textbf{Capa 4 (Bottom Layer):} Capa externa de señal secundaria para el conexionado final y ruteado de líneas menos críticas.
\end{itemize}

El espesor dieléctrico entre las capas externas y los planos internos adyacentes se ha seleccionado de dimensiones reducidas (aproximadamente $0.137\,\text{mm}$ mediante la combinación simétrica de dos hojas de prepreg PP-004 y PP-006). Esta reducida separación física permite alcanzar las impedancias características deseadas utilizando anchos de traza realizables y manejables bajo las restricciones de fabricación de Clase 6 del fabricante Lab Circuits.

El detalle físico del stack-up diseñado en el Gestor de Capas (Layer Stack Manager) de Altium Designer se presenta en la Tabla~\ref{tab:stackup_capas}:

\begin{table}[htbp]
\centering
\small
\begin{tabularx}{\textwidth}{|c|l|X|c|c|c|}
\hline
\textbf{\#} & \textbf{Capa} & \textbf{Material / Función} & \textbf{Espesor} & \textbf{$D_k$} & \textbf{Grosor Cobre} \\ \hline
-- & Top Overlay & Leyenda (Silkscreen) & -- & -- & -- \\ \hline
-- & Top Solder & Máscara de soldadura (SM-001) & $25.4\,\mu\text{m}$ & $4.0$ & -- \\ \hline
-- & Acabado Sup. & Oro químico (ENIG) & $4.0\,\mu\text{m}$ & -- & -- \\ \hline
1 & Top Layer & Señal externa (Cobre) & $17.5\,\mu\text{m}$ & -- & $17.5\,\mu\text{m}$ ($1/2\,\text{oz}$) \\ \hline
-- & Dielectric 1 & Prepreg FR4 (PP-004) & $66.0\,\mu\text{m}$ & $3.8$ & -- \\ \hline
-- & Dielectric 2 & Prepreg FR4 (PP-006) & $71.1\,\mu\text{m}$ & $4.1$ & -- \\ \hline
2 & Int1 (GND) & Plano de masa (Cobre) & $35.0\,\mu\text{m}$ & -- & $35.0\,\mu\text{m}$ ($1\,\text{oz}$) \\ \hline
-- & Dielectric 3 & Núcleo (Core-039) & $1.10\,\text{mm}$ & $4.8$ & -- \\ \hline
3 & Int2 (PWR) & Plano de alimentación (Cobre) & $35.0\,\mu\text{m}$ & -- & $35.0\,\mu\text{m}$ ($1\,\text{oz}$) \\ \hline
-- & Dielectric 4 & Prepreg FR4 (PP-006) & $71.1\,\mu\text{m}$ & $4.1$ & -- \\ \hline
-- & Dielectric 5 & Prepreg FR4 (PP-004) & $66.0\,\mu\text{m}$ & $3.8$ & -- \\ \hline
4 & Bottom Layer & Señal externa (Cobre) & $17.5\,\mu\text{m}$ & -- & $17.5\,\mu\text{m}$ ($1/2\,\text{oz}$) \\ \hline
-- & Acabado Sup. & Oro químico (ENIG) & $4.0\,\mu\text{m}$ & -- & -- \\ \hline
-- & Bottom Solder & Máscara de soldadura (SM-001) & $25.4\,\mu\text{m}$ & $4.0$ & -- \\ \hline
-- & Bottom Overlay & Leyenda (Silkscreen) & -- & -- & -- \\ \hline
\end{tabularx}
\caption{Detalle de las capas físicas, espesores dieléctricos y grosor de cobre del stack-up diseñado.}
\label{tab:stackup_capas}
\end{table}

El espesor dieléctrico total acumulado es de aproximadamente $1.49\,\text{mm}$. Al añadir las capas protectoras de soldadura y acabados de oro químico, el espesor final de la placa es de aproximadamente $1.54\,\text{mm}$, el cual cumple con la tolerancia comercial de fabricación estándar de $1.6\,\text{mm}$ establecida por Lab Circuits.

\subsubsection{Cálculo Geométrico e Impedancias de los Buses}

Utilizando el simulador de líneas de transmisión integrado SIMBEOR en Altium Designer, hemos calculado las dimensiones geométricas óptimas (ancho de traza $W$ y espaciado de par diferencial $G$) necesarias para cumplir los requerimientos de impedancia diferencial e individual en las capas de señal externas (L1 y L4):

\begin{itemize}
    \item \textbf{Bus CAN ($120\,\Omega$):} La impedancia objetivo de la norma ISO 11898 es de $120\,\Omega$. Hemos configurado trazas de ancho $W = 0.150\,\text{mm}$ con una separación de par de $G = 0.3628\,\text{mm}$.
    \item \textbf{Bus Ethernet ($100\,\Omega$):} Para el par diferencial MDI de la PHY, se requiere una impedancia controlada de $100\,\Omega$. Hemos calculado un ancho de traza de $W = 0.182\,\text{mm}$ y una separación de par de $G = 0.180\,\text{mm}$.
    \item \textbf{Bus USB ($90\,\Omega$):} La especificación USB 2.0 Full-Speed requiere un par de señal balanceado de $90\,\Omega$ de impedancia diferencial. Hemos implementado un ancho de traza de $W = 0.190\,\text{mm}$ con un espacio entre ellas de $G = 0.150\,\text{mm}$.
    \item \textbf{Líneas Single-Ended ($50\,\Omega$):} Para trazas de señales generales críticas y líneas de alimentación del sistema, se fija un target estándar de $50\,\Omega$. El ancho de pista resultante es de $W \approx 0.230\,\text{mm}$.
\end{itemize}

La Tabla~\ref{tab:impedancias} resume la comparación entre las impedancias ideales especificadas, las obtenidas mediante simulación electromagnética en Altium Designer y el porcentaje de variación final de diseño:

\begin{table}[H]
\centering
\small
\begin{tabularx}{\textwidth}{|l|l|X|c|c|c|}
\hline
\textbf{Interfaz / Bus} & \textbf{Tipo de Línea} & \textbf{Geometría ($W$ y $G$)} & \textbf{$Z$ Ideal} & \textbf{$Z$ Simulada} & \textbf{Variación} \\ \hline
\textbf{CAN} & Diferencial (L1 / L4) & $W=0.150\,\text{mm}$, $G=0.363\,\text{mm}$ & $120\,\Omega$ & $119.97\,\Omega$ & $-0.025$\,\% \\ \hline
\textbf{Ethernet} & Diferencial (L1 / L4) & $W=0.182\,\text{mm}$, $G=0.180\,\text{mm}$ & $100\,\Omega$ & $99.99\,\Omega$ & $-0.010$\,\% \\ \hline
\textbf{USB} & Diferencial (L1 / L4) & $W=0.190\,\text{mm}$, $G=0.150\,\text{mm}$ & $90\,\Omega$ & $94.91\,\Omega$ & $+5.460$\,\% \\ \hline
\textbf{GPIO / Señal} & Single-Ended (L1 / L4) & $W=0.230\,\text{mm}$ & $50\,\Omega$ & $53.65\,\Omega$ & $+7.300$\,\% \\ \hline
\end{tabularx}
\caption{Comparación entre impedancias ideales especificadas por los estándares y los valores calculados en el stack-up final.}
\label{tab:impedancias}
\end{table}

\subsection{Modelado y Vista Tridimensional (3D) de la PCB}

Para complementar la validación espacial y el análisis de distribución física de los componentes, hemos generado el modelo tridimensional (3D) de la PCB en Altium Designer. Esta representación permite realizar una inspección visual interactiva y verificar la compatibilidad de los encapsulados físicos, la orientación de los conectores y la altura relativa de los componentes para asegurar que no existan interferencias mecánicas en el montaje final.

En la Figura~\ref{fig:render_3d} se muestran los renders tridimensionales obtenidos para ambas caras de la tarjeta:
\begin{itemize}
    \item \textbf{Vista de la cara superior (Top Side):} Permite apreciar la distribución del microcontrolador en formato LQFP144 en la parte central, flanqueado por los bloques Ethernet en la esquina superior derecha, el conector Weidmüller en la parte superior central y la etapa de alimentación y puerto USB en la esquina inferior izquierda.
    \item \textbf{Vista de la cara inferior (Bottom Side):} Muestra el ruteado secundario y el plano de masa de la placa, con componentes pasivos adicionales dispuestos para minimizar las distancias de desacoplo.
\end{itemize}

\begin{figure}[htbp]
    \centering
    \begin{subfigure}{0.85\linewidth}
        \centering
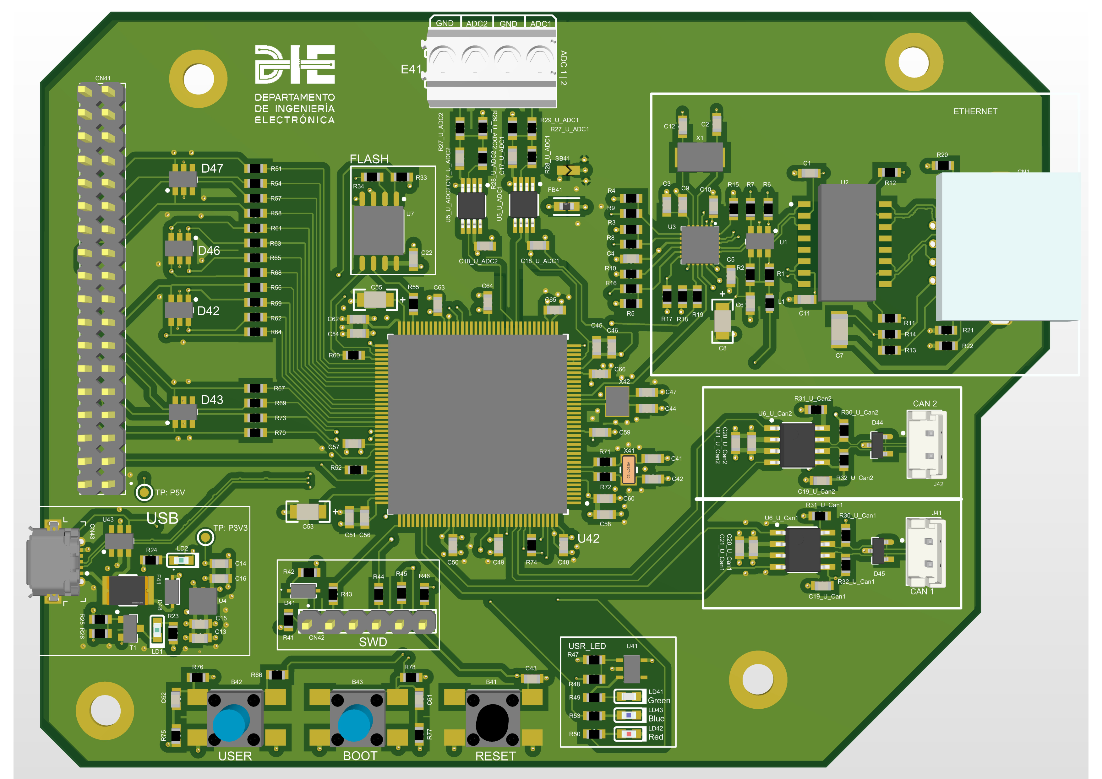
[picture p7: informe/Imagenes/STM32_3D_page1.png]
        
        \caption{Vista tridimensional de la cara superior (Top Layer).}
        \label{fig:3d_top}
    \end{subfigure}
    \vspace{0.3cm}
    \begin{subfigure}{0.85\linewidth}
        \centering
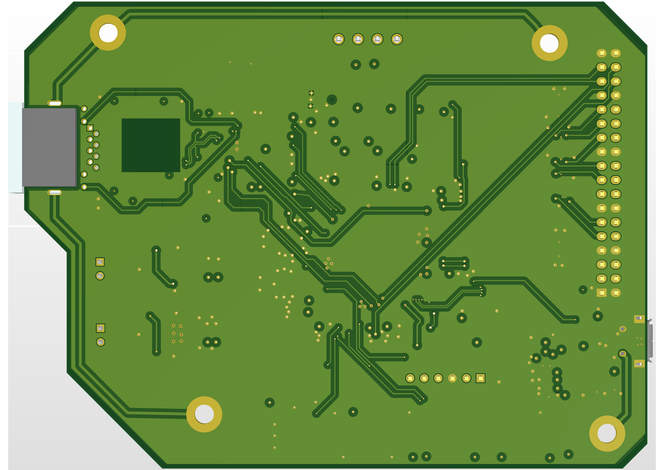
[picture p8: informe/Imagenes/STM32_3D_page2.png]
        
        \caption{Vista tridimensional de la cara inferior (Bottom Layer).}
        \label{fig:3d_bottom}
    \end{subfigure}
    \caption{Modelado en tres dimensiones (3D) de la placa final diseñada en Altium Designer.}
    \label{fig:render_3d}
\end{figure}

\section{Análisis de Integridad de Señal (Reflexiones)}

Para validar la calidad del ruteado y asegurar el correcto funcionamiento electromagnético de la PCB, hemos realizado simulaciones post-layout de integridad de señal (Signal Integrity - SI) en las líneas de comunicación de alta velocidad más críticas (CAN, USB y Ethernet). El objetivo principal de este análisis es evaluar la presencia de reflexiones, sobreoscilaciones (overshoot/undershoot) o acoplamientos no deseados (crosstalk) que pudieran distorsionar las señales lógicas y provocar fallos en las transmisiones de datos.

\subsection{Bus CAN}

Hemos analizado las reflexiones en las líneas diferenciales CAN1\_H/CAN1\_L y CAN2\_H/CAN2\_L tras su ruteado en las capas externas de la placa:

\begin{figure}[H]
    \centering
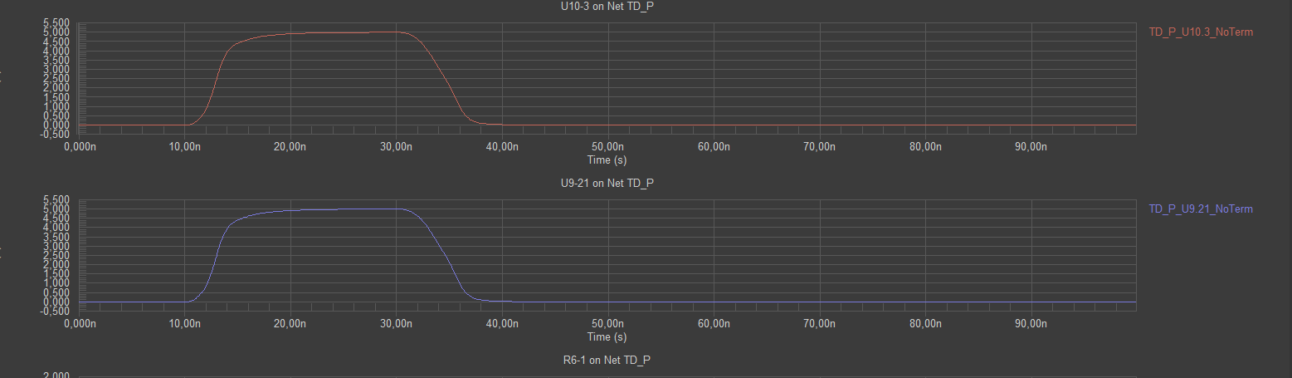
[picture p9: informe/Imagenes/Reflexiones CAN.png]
    
    \caption{Resultados de la simulación de integridad de señal en el bus de comunicación CAN.}
    \label{fig:reflexiones_can}
\end{figure}

Como se observa en la Figura~\ref{fig:reflexiones_can}, las formas de onda lógicas no presentan oscilaciones secundarias significativas ni deformación en las transiciones de flanco. La adaptación de impedancia diferencial calculada a $119.97\,\Omega$ (prácticamente idéntica al target nominal de $120\,\Omega$ del estándar ISO 11898) y la implementación de la red de terminación de línea dividida (Split Termination) con su filtro de modo común absorben la energía de la onda de forma óptima, suprimiendo cualquier rebote de señal en los extremos del bus.

\subsection{Bus USB}

Hemos simulado el comportamiento dinámico de las líneas diferenciales de datos USB\_DM y USB\_DP operando en modo Full-Speed ($12\,\text{Mbps}$):

\begin{figure}[H]
    \centering
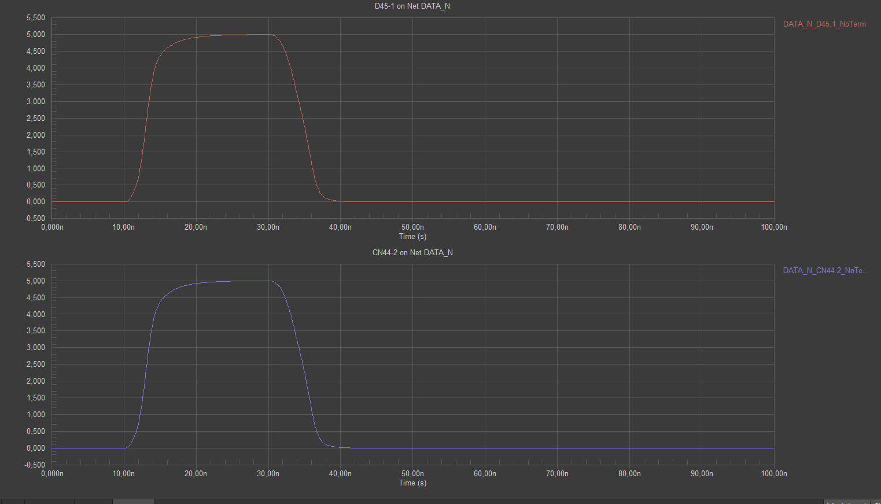
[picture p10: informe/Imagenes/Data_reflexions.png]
    
    \caption{Simulación de reflexiones y transiciones de flanco en el par diferencial de datos USB.}
    \label{fig:reflexiones_usb}
\end{figure}

En la Figura~\ref{fig:reflexiones_usb} se muestra que las transiciones entre estados lógicos son limpias, simétricas y sin sobreoscilaciones destructivas que superen las tolerancias lógicas de las entradas del microcontrolador. Esto es el resultado directo de:
\begin{itemize}
    \item La adaptación de impedancia diferencial a $94.91\,\Omega$ (con una variación admisible de $+5.46$\,\% frente al target de $90\,\Omega$).
    \item La colocación del diodo TVS de baja capacitancia \textbf{USBLC6-4SC6} inmediatamente adyacente al conector.
    \item La minimización del lazo de corriente mediante un plano de masa continuo en la capa interna L2 justo debajo de las trazas lógicas.
\end{itemize}

\subsection{Interfaz Ethernet}

Hemos verificado el comportamiento del par diferencial de transmisión (TX+/TX-) y recepción (RX+/RX-) de la interfaz física MDI de la PHY LAN8742A para transmisión a $100\,\text{Mbps}$ (100BASE-TX):

\begin{figure}[H]
    \centering
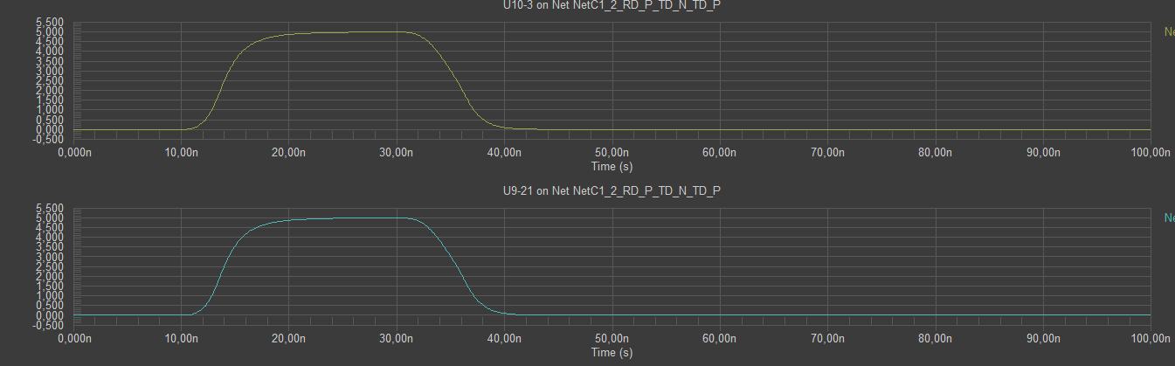
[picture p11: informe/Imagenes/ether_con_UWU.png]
    
    \caption{Formas de onda y análisis de reflexiones en los pares diferenciales de la interfaz Ethernet.}
    \label{fig:reflexiones_ethernet}
\end{figure}

El análisis dinámico de la Figura~\ref{fig:reflexiones_ethernet} confirma la viabilidad del ruteado simétrico del par diferencial de Ethernet. El desajuste de impedancia respecto a los $100\,\Omega$ teóricos es prácticamente nulo (variación del $-0.01$\,\%, con una impedancia simulada de $99.99\,\Omega$), eliminando pérdidas de retorno. Además, la supresión de planos de alimentación y masa bajo el conector RJ45 (copper keep-out bajo los magnetizados del conector) previene acoplamientos capacitivos parásitos que distorsionan el modo común del par diferencial.

\section{Directivas y Reglas de Diseño (DRC)}

Con el fin de asegurar que el diseño físico (layout) cumple rigurosamente con los límites geométricos de fabricación y con los requisitos de compatibilidad electromagnética y eléctricos del sistema, hemos configurado e implementado las siguientes reglas de diseño (Design Rule Check - DRC) en Altium Designer:

\begin{enumerate}
    \item \textbf{Aislamiento Eléctrico (Clearance):} Hemos configurado un clearance general mínimo de $0.20\,\text{mm}$ para todas las señales. Para las líneas de alimentación (+5V, +3.3V y +3.3V analógico), la regla de aislamiento se ha incrementado a $0.40\,\text{mm}$ para mitigar el acoplamiento inductivo y reducir la inducción de ruido en trazas lógicas adyacentes. El aislamiento entre taladros metalizados y cobre conductor se ha fijado en $0.25\,\text{mm}$ para cumplir con el límite de Clase 6 del fabricante.
    \item \textbf{Ancho de Trazas (Width Constraint):}
    \begin{itemize}
        \item \textbf{Señales generales:} Ancho nominal de $0.20\,\text{mm}$ (cumpliendo con Clase 6, cuyo mínimo es $0.15\,\text{mm}$ para cobre de $35\,\mu\text{m}$).
        \item \textbf{Alimentación y Planos:} Para líneas de potencia de media corriente, hemos definido anchos de traza entre $0.50\,\text{mm}$ y $1.00\,\text{mm}$ según la corriente de carga esperada (con un límite mínimo absoluto de $0.35\,\text{mm}$).
    \end{itemize}
    \item \textbf{Pares Diferenciales (Differential Pairs Routing):} Hemos definido reglas específicas de enrutado acoplado para controlar las impedancias diferenciales:
    \begin{itemize}
        \item \textbf{Bus CAN:} Ancho de pista de $0.15\,\text{mm}$ y un espaciado constante de $0.363\,\text{mm}$.
        \item \textbf{Bus Ethernet:} Ancho de pista de $0.182\,\text{mm}$ y un espaciado constante de $0.180\,\text{mm}$.
        \item \textbf{Bus USB:} Ancho de pista de $0.190\,\text{mm}$ y un espaciado constante de $0.150\,\text{mm}$.
    \end{itemize}
    \item \textbf{Geometría de Vías de Conexión y Stitching:} Las vías de masa generales y de stitching se han limitado a un diámetro de taladro (drill) de $0.30\,\text{mm}$ y un diámetro de pad de $0.68\,\text{mm}$. Esta configuración asegura una corona interna de $0.19\,\text{mm}$, proporcionando un margen de seguridad del $27$\,\% sobre el límite de Clase 6 de Lab Circuits ($0.15\,\text{mm}$) y absorbiendo las tolerancias de excentricidad del taladro.
\end{enumerate}

\section{Conclusiones}

Tras completar las etapas de diseño esquemático, cálculo geométrico del apilado, enrutamiento y simulación electromagnética de la placa controladora basada en el microcontrolador STM32F746ZG, hemos extraído las siguientes conclusiones:

\begin{itemize}
    \item \textbf{Viabilidad Tecnológica y DFM:} El diseño se adapta estrictamente a los parámetros tecnológicos de fabricación de \textbf{Lab Circuits S.A. Clase 6}. El uso de taladros pasantes de $0.30\,\text{mm}$ y anchos de traza controlada de hasta $0.15\,\text{mm}$ son totalmente compatibles con el proceso estándar, evitando la necesidad de tecnologías especiales como microvías HDI y garantizando una corona (annular ring) segura frente a tolerancias mecánicas.
    \item \textbf{Integridad de Señal Robusta:} Las simulaciones dinámicas post-layout de los buses serie de alta velocidad (CAN, USB, Ethernet) validan el excelente comportamiento del stack-up simétrico de 4 capas diseñado. Las desviaciones de impedancia diferencial obtenidas se encuentran dentro de márgenes muy estrechos (desde el $-0.01$\,\% en Ethernet hasta un $+5.46$\,\% en USB, muy por debajo de las tolerancias recomendadas del $\pm10$\,\%), eliminando problemas de reflexiones lógicas y asegurando la compatibilidad electromagnética.
    \item \textbf{Protección y Fiabilidad:} La inclusión de diodos TVS multicanal específicos de baja capacitancia (como el USBLC6-4SC6 en USB/MDI y el ESDA6V1BC6 en los puertos de expansión GPIO) garantiza un alto grado de protección contra descargas electrostáticas (ESD), asegurando la supervivencia del microcontrolador ante eventos transitorios en entornos industriales.
\end{itemize}

El diseño propuesto es técnicamente maduro, funcionalmente robusto y cumple con todas las restricciones DFM para su inmediata fabricación y ensamblaje.

\end{document}

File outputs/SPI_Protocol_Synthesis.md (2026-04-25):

# SPI Protocol Synthesis: STM32F746ZG & SST25VF040B

This document synthesizes recommendations and technical specifications for implementing the SPI protocol in the custom PCB project.

## 1. Technical Specifications

### STM32F746ZG (Master)
- **Clock Frequencies:**
  - **SPI1, 4, 5, 6:** Up to **54 MHz** (Master mode, 2.7V $\le$ VDD $\le$ 3.6V).
  - **SPI2, 3:** Up to **27 MHz**.
  - **Constraint:** SPI1 max frequency is reduced to **40 MHz** if SCK is mapped to **PA5**.
- **I/O Configuration:**
  - **Speed:** Set GPIO `OSPEEDR` to `11` (Very High Speed).
  - **Levels:** 3.3V CMOS.

### SST25VF040B (Slave Flash)
- **Supported Modes:** Mode 0 (CPOL=0, CPHA=0) and Mode 3 (CPOL=1, CPHA=1).
- **Maximum Frequency:** 50 MHz.
- **Pin Logic:** Data sampled on rising edge of SCK, driven on falling edge.

## 2. Signal Integrity (SI) & Layout Recommendations

### Impedance Control
- **General Rule:** No strict impedance requirement for "electrically short" traces (length < 10% of signal rise time distance).
- **Target:** Aim for **50 $\Omega$** if using controlled impedance (simplifies fabrication if other high-speed buses are present).
- **Termination:** Place **22 $\Omega$ to 33 $\Omega$** series resistors close to the driver (MCU for SCK/MOSI, Flash for MISO) to damp ringing and slow down edges.

### Physical Layout
- **Ground Plane:** Route traces over a continuous solid ground plane to provide a clear return path and reduce EMI.
- **Trace Matching:** Keep SCK, MISO, and MOSI traces matched in length (within $\pm$ 10mm) for high-speed operation (>20 MHz).
- **Separation:** Maintain distance from high-speed switching lines (e.g., Ethernet) to avoid crosstalk.

## 3. Hardware Implementation

### Multi-Slave Strategy
- **Topology:** Star topology is preferred for connecting expansion headers and on-board Flash.
- **NSS Management:** Use **Software NSS** (Standard GPIOs) for Chip Select to support multiple slaves easily.
- **Pull-ups:** Add a **10k $\Omega$ pull-up** on the CS (CE#) line to ensure the Flash remains disabled during reset.

### Pin Selection Conflicts (Nucleo-144)
- **Ethernet:** Avoid PB13 (RMII_TXD1) and PA7 (RMII_DV) if Ethernet is required.
- **LEDs:** Avoid PA5 if the onboard User LED is needed (also limited to 40MHz for SPI1).
- **Recommended SPI2 Pins:** SCK: PB10, MISO: PC2, MOSI: PC3, CS: PB12.

[Sources: stm32f746zg.pdf, dm00244518.pdf, SST25VF040B-Data-Sheet, Altium SPI SI Article]

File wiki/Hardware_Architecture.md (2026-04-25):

# Hardware Architecture: STM32F746ZG PCB

Design strategies for power, clocking, and signal integrity.

## ⚡ Power Delivery Network (PDN)
The STM32F746ZG requires multiple stable voltage rails.

### Decoupling Requirements
- **VDD Pins:** Each VDD pin requires a 100 nF ceramic capacitor.
- **Bulk Capacitance:** 1x 4.7 µF ceramic capacitor on the VDD rail.
- **VDDA:** 100 nF + 1 µF close to pin. Use a ferrite bead for isolation from VDD.
- **VCAP:** 2x 2.2 µF low-ESR ceramic capacitors (VCAP_1, VCAP_2) to VSS. **CRITICAL.**
- **Peripheral Power:** CAN transceivers require **5V VCC**. VIO must be tied to **3.3V**.

## 🕒 Clock Distribution
- **HSE:** 8 MHz crystal on PH0/PH1.
- **LSE:** 32.768 kHz crystal on PC14/PC15.
- **Ethernet:** 50 MHz RMII_REF_CLK sourced from PHY to PA1.

## 🛡 Signal Integrity & Layout
- **Ethernet:** Differential pairs (100 $\Omega$). Remove copper under magnetic.
- **USB:** Differential pairs (90 $\Omega$). Use USBLC6-4SC6 for ESD.
- **CAN:** Differential pairs (120 $\Omega$ termination). Use jumpers for selectable termination.
- **SPI Protocol:**
    - Use **33-100 Ω series resistors** on SCK, MOSI, and CS for signal integrity.
    - Set GPIO drive strength to **High/Very High** for speeds >25 MHz.
    - Prefer **Software NSS management** for multi-slave flexibility.
    - Implement a **10k Ω pull-up** on CS to prevent floating during reset.
    - Match trace lengths and route over a solid ground plane.

- **Analog (0-10V):** 
    - Use a **22k / 10k** resistor divider to scale 10V to 3.125V.
    - Implement an **Op-Amp Buffer** (e.g., TLV9002) for each channel to ensure high input impedance and protect MCU pins.
- **Manual Boot Selection:**
    - Use a **10k $\Omega$ pull-down** on BOOT0 for default Flash boot.
    - Add a **push-button** to 3.3V (with a 100 $\Omega$ series resistor) to manually enter the Bootloader.

## 📐 PCB Stack-up
- **Layers:** 4 layers (Signal / GND / PWR / Signal).
- **Thickness:** Max **1.6 mm** (Lab Circuits).
- **Mounting:** 4x 3.5mm holes connected to **EARTH**.

[Source: stm32f746zg.pdf, dm00244518.pdf, Project Proposal]

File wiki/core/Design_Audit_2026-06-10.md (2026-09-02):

# Pre-Production Design Audit — STM32F746ZG Custom PCB

> Sources: Joan San Bartolome, 2026-06-10; STMicroelectronics, 2016-02-15; Microchip, 2015-08-01; Texas Instruments, 2003-09-12
> Raw: [STM32_Esqumaticos.pdf](../../raw/prints/STM32_Esqumaticos.pdf); [STM32_Layout.pdf](../../raw/prints/STM32_Layout.pdf); [stm32f746zg.pdf](../../raw/datasheets/stm32f746zg.pdf); [dm00244518.pdf](../../raw/datasheets/dm00244518.pdf); [sn65hvd230q-q1.pdf](../../raw/datasheets/sn65hvd230q-q1.pdf)

## Overview

This document constitutes a **formal pre-production design audit** of the STM32F746ZG custom PCB (Project DCI 2025/2026, Rev B-01). The review has been conducted by examining the complete schematic set (9 sheets) against the project requirements, relevant datasheets, and industry best practices for mixed-signal embedded systems.

The audit is structured by subsystem. Each section opens with a status verdict, lists what is correct, and then details every deficiency found — ranked by severity — together with a concrete remediation proposal.

**Severity Scale:**
- 🔴 **CRITICAL** — Board will not function or will be damaged. Blocks production.
- 🟠 **MAJOR** — Degraded performance, intermittent failures, or EMC non-compliance. Must fix before production.
- 🟡 **MINOR** — Sub-optimal but functional. Fix recommended.
- ✅ **PASS** — Compliant with requirements and best practices.

---

## 1. Power Delivery Network (PDN)

**Status: ✅ PASS (Corrected)**

### ✅ What Is Correct
- The LD39050PU33R LDO (U4) is a solid choice for a 500 mA linear regulator. The DFN-6 package provides excellent thermal performance.
- Input decoupling (C13 = 1µF) and output decoupling (C14 = 1µF, C15 = 100nF, C16 = 100nF) are present, satisfying stability requirements.
- The USB VBUS path includes the BAT60JFILM Schottky diode (D44) for reverse-current protection and the MF-MSMF050-2 resettable fuse (F41) for overcurrent protection. This is textbook correct.
- The PG (Power Good) pin is correctly used to drive a status LED (LD2) via a transistor switch (T1, 9013 NPN).

### 🟢 MAJ-PDN-01: LDO Output Stability [VERIFICADO / FALSO POSITIVO]

**Finding:** In the initial audit, it was flagged that the output side of the LD39050PU33R had only 100nF capacitors (C15, C16), violating the 1µF minimum. However, a detailed schematic review confirms that **C14 (1µF X5R 0603)** is already placed on the LDO output rail (`P3V3_PER`), in parallel with C15 and C16.

**Risk:** None. The combination of C14 (1µF) + C15 (100nF) + C16 (100nF) provides a total of 1.2µF, which fully satisfies the datasheet stability requirements.

**Correction/Status:** ✅ No action required. The schematic already implements the correct output capacitance. C16 remains at 100nF.

### 🟢 MIN-PDN-02: No Dedicated Bulk Capacitor near MCU VDD Cluster [CORREGIDO]

**Finding:** The MCU has 13× 100nF decoupling capacitors (C51-C64) and a single 4.7µF bulk capacitor (C64). The 4.7µF capacitor is placed at pin VDD_9 (Pin 95).

**Risk:** During simultaneous high-speed switching on Ethernet RMII + CAN + SPI, the instantaneous current demand can exceed what a single 4.7µF capacitor can supply without significant voltage droop.

**Recommendation:**
- Add a second **10µF X5R 0805** bulk capacitor near VDD_1 (Pin 72), at the opposite end of the VDD pin cluster. This distributes the bulk energy storage across both halves of the package.
- **Status:** ✅ Corregido. Se ha añadido un capacitor de bulk de 10µF X5R 0805 en Pin 72. Ver justificación en [PDN Decoupling Theory](PDN_Decoupling_Theory.md).

### ✅ VCAP Configuration: PASS

The VCAP pins (VCAP1 at Pin 71, VCAP2 at Pin 106) are correctly terminated with 2.2µF X7R capacitors (C48, C49) directly to VSS. This is critical for the internal core voltage regulator and is implemented correctly.

---

## 2. Analog Power Domain (VDDA / VREF+)

**Status: ✅ PASS (Corrected)**

### ✅ What Is Correct
- VDDA (Pin 33) and VREF+ (Pin 32) are supplied through a ferrite bead (L41) from VDD, with local decoupling (C59 = 100nF).
- VSSA (Pin 31) is connected to the analog ground (AGND) reference.
- The intent to isolate the analog supply from digital noise is correctly identified.

### 🟢 CRI-ANA-01: Ferrite Bead Value Excessively High (100µH) [CORREGIDO]

**Finding:** L41 was specified as a "100µH BEAD" (which was an inductor in place of a ferrite bead).

**Risk:** High DCR causes DC voltage drop on VDDA/VREF+ (corrupting ADC readings), and high inductance creates a low-frequency resonant peak with the decoupling capacitors that amplifies noise.

**Correction:**
- Replace L41 with a proper **ferrite bead** rated at $Z = 120\,\Omega\text{ @ }100\,\text{MHz}$, $\text{DCR} < 100\,\text{m}\Omega$, $I_{rated} \geq 300\,\text{mA}$ (e.g., **Murata BLM18PG121SN1D**, 0603 package).
- Add a **1µF X7R 0603** capacitor in parallel with the existing 100nF on VDDA (total: 100nF + 1µF) to meet STM32 decoupling guidelines.
- **Status:** ✅ Corregido. Se ha montado la perla de ferrita **Murata BLM18PG121SN1D** en L41 y se ha añadido el capacitor de 1µF en paralelo con C59 para cumplir con la especificación de desacoplo de VDDA.

### 🟢 MIN-ANA-02: VBAT Decoupling [VERIFICADO / FALSO POSITIVO]

**Finding:** In the initial audit, it was flagged that Pin 6 (VBAT) was connected to VDD with a 100nF capacitor (C55) through an RC network formed by R59 and R61. However, a detailed schematic review shows that Pin 6 (VBAT) is actually connected directly to a **1µF decoupling capacitor (C50)** to VDD. The resistors R59 and R61 are adjacent on the sheet but not electrically connected to VBAT.

**Risk:** None. Since there is no coin cell battery or supercapacitor, the RTC calendar is lost on power down, which is acceptable if backup timekeeping is not required. The decoupling is fully adequate.

**Correction/Status:** ✅ No action required. The pin is decoupled with a 1µF capacitor and has no series/pull-up resistors connected.

---

## 3. Clock System

**Status: 🟡 MINOR ISSUES**

### ✅ What Is Correct
- **HSE (8 MHz):** NX3225GD-8.000M crystal (X42) on PH0/PH1 with matched 4.3 pF load capacitors (C45, C47). This is consistent with the crystal's specified load capacitance.
- **LSE (32.768 kHz):** NX3215SA crystal (X41) on PC14/PC15 with C41 and C42 marked `4.3pF [N/A]`, indicating they are footprints placed for optional tuning but not populated. This is acceptable if the crystal's specifications allow operation with only parasitic PCB capacitance (~2 pF).
- **Ethernet PHY (25 MHz):** X53T-C20SSA-25.000MHz crystal (X4) on XTAL1/XTAL2 of the LAN8742A, with 30 pF load capacitors (C6, C11). Values match the crystal spec.

### 🟡 MIN-CLK-01: Missing Feedback Resistor on HSE

**Finding:** There is no feedback resistor across the HSE crystal (X42, pins PH0/PH1). The schematic shows the crystal with load capacitors but without the 1 MΩ feedback resistor specified in AN2867 (ST Oscillator Design Guide).

**Risk:** The STM32F746ZG has an internal feedback resistor in most configurations, so the oscillator will likely start. However, for production reliability across temperature extremes (-40°C to +85°C) and crystal aging, an external **1 MΩ resistor across PH0-PH1** is recommended by ST's application note AN2867 to guarantee reliable startup.

**Recommendation:**
- Add a **1 MΩ 0402** resistor footprint (DNP by default) across PH0 and PH1 for production margin. Populate only if startup issues arise during environmental testing.

### ✅ Ethernet REF_CLK: PASS

The 50 MHz RMII reference clock is sourced from the LAN8742A (Pin 14, nINT/REFCLK0) and routed to PA1. This is the standard clocking topology for RMII mode. The PHY generates the clock from its 25 MHz crystal and provides it to the MCU, avoiding the need for an external 50 MHz oscillator.

---

## 4. Ethernet Subsystem (LAN8742A + RMII + RJ45)

**Status: 🟠 MAJOR ISSUES**

### ✅ What Is Correct
- The LAN8742A PHY (U9) is correctly wired to the MCU via RMII with the standard 9-signal pinout.
- The RBIAS resistor (R14 = 12.1kΩ 1%) is correctly placed on Pin 24.
- The RJ45 with integrated magnetics (KRJ-CB4.2GYZNL, CN14) eliminates the need for external magnetics and simplifies the layout.
- ESD protection (USBLC6-4SC6, U10) is correctly placed on the MDI differential pairs.
- Status LEDs are connected via series resistors (R67 = 270Ω, R65 = 270Ω) to the PHY LED pins.
- The MODE pins (RXD0/MODE0 on Pin 8, RXD1/MODE1 on Pin 7) are pulled to the correct states via the RMII signal termination resistors during power-on reset to configure the PHY in RMII mode.

### 🟠 MAJ-ETH-01: Incorrect RMII Signal Termination Resistor Values

**Finding:** The RMII data lines from the MCU to the PHY include series resistors R7 = 33Ω and R8 = 33Ω on RXER (Pin 10) and on the RXD lines. Additionally, R40 = 33Ω is placed on CRS_DV and R17 = 33Ω on REF_CLK.

**Risk:** A 33Ω series termination on a 50Ω trace creates an impedance mismatch. The driver output impedance of the STM32F746ZG GPIO at "Very High Speed" is approximately 25-40Ω. Adding 33Ω in series yields a total source impedance of 58-73Ω driving a 50Ω line, which introduces:
- **Overshoot and undershoot** at the receiver end (up to 15% of $V_{OH}$).
- **Marginal setup/hold timing** at 50 MHz, where the timing budget is only 10 ns per clock period.

**Correction:**
- For RMII at 50 MHz, the **recommended series termination is 22Ω** (matching $Z_0 - R_{driver} \approx 50 - 30 = 20\Omega$, rounded to the nearest standard value).
- Change R7, R8, R40, and R17 from **33Ω to 22Ω**.
- **Exception:** R14 (RBIAS) must remain at 12.1kΩ. Do not confuse with signal resistors.

### 🟠 MAJ-ETH-02: RXER Pin (Pin 10) Not Properly Handled

**Finding:** In the schematic, Pin 10 (RXER/PHYAD0) of the LAN8742A is connected through a $10\,\text{k}\Omega$ pull-down (R9). During normal RMII operation, this pin is the **Receive Error** output from the PHY.

**Risk:** The RXER signal is **not connected to the MCU**. In RMII mode, the STM32F746ZG MAC does not require RXER (it uses CRS_DV and RXD[1:0] only). However, the pull-down on RXER also sets the **PHYAD0** strap during power-on reset. With R9 = 10kΩ to GND, PHYAD0 = 0, setting the PHY address to **0x00**.

**Issue:** PHY address 0x00 is the MDIO broadcast address. While many RMII implementations function correctly at address 0, some network stacks may encounter issues when scanning for PHYs. The LAN8742A default address with all MODE/PHYAD pins at default is **0x00**, which is technically valid but not ideal.

**Recommendation:**
- This is acceptable for a single-PHY design. However, if future revisions may add a second PHY, change R9 to a **pull-up to 3.3V** to set PHYAD0 = 1 (PHY address = 0x01), reserving address 0 for broadcast.

### 🟡 MIN-ETH-03: Missing Series Resistors on MDI Differential Pairs

**Finding:** The MDI pairs (TX+/TX-, RX+/RX-) from the PHY to the magnetics section have series resistors R1, R2 = 50Ω and R5, R6 = 50Ω, but also R10-R13 = 75Ω in what appears to be a Bob-Smith termination network.

**Risk:** The 75Ω resistors (R10-R13) are connected to a center-tap arrangement for common-mode noise rejection. This is a well-known Ethernet best practice. However, the center tap must be terminated to **chassis ground (EARTH)** through a high-voltage capacitor (typically 1kV, 2.2nF), not to digital GND. Verify on the layout that these connect to the mounting holes / chassis, not the PCB signal ground.

**Recommendation:**
- Confirm on the PCB layout that the Bob-Smith termination center tap connects to EARTH (mounting holes) through a 2.2nF / 2kV Y-class capacitor. If it connects to digital GND, the common-mode rejection is defeated and EMC testing will fail.

---

## 5. USB Interface

**Status: ✅ PASS (Corrected)**

### ✅ What Is Correct
- Micro-USB connector (Molex 475900001, CN44) correctly wired with VBUS, D+, D-, ID, GND, and Shield.
- VBUS sensing on PA9 for USB OTG detection.
- BAT60JFILM Schottky diode (D44) for reverse-current protection.
- MF-MSMF050-2 resettable fuse (F41) on VBUS.
- USB_ID on PA10 for OTG role detection.

### 🟢 CRI-USB-01: Wrong ESD Protection Component (ESDA6V1BC6 instead of USBLC6-4SC6) [CORREGIDO]

**Finding:** The schematic originally showed D45 as **ESDA6V1BC6** on the USB D+/D- lines.

**Risk:** The ESDA6V1BC6 has a line capacitance of approximately **15-20 pF per channel**, which violates the USB 2.0 Full Speed bus capacitance limits ($< 10\,\text{pF}$), causing signal distortion and CRC/enumeration errors.

**Correction:**
- Replace D45 (ESDA6V1BC6) with **USBLC6-4SC6** (3.5 pF per channel).
- **Status:** ✅ Corregido. D45 ha sido reemplazado por la matriz protectora de ultra-baja capacitancia **USBLC6-4SC6** (3.5 pF), solucionando el riesgo de distorsión en las líneas de datos USB.

### 🟡 MIN-USB-02: Missing D+ Pull-Up Resistor for Full Speed Detection

**Finding:** The USB D+ line has no pull-up resistor to 3.3V. The STM32F746ZG has an **internal pull-up** that can be enabled via software (`USB_OTG_FS->GCCFG |= USB_OTG_GCCFG_PWRDWN`).

**Risk:** If the firmware fails to enable the internal pull-up, the USB host will not detect the device. The internal pull-up is also subject to process variation (1.5kΩ ± 20%).

**Recommendation:**
- Add a **1.5kΩ ±5%** resistor footprint (DNP) from D+ to 3.3V as a fallback. This is not strictly required if the firmware is reliable, but provides a hardware guarantee for production testing before firmware is loaded.

---

## 6. CAN Bus Interface (×2)

**Status: 🟡 MINOR ISSUE**

### ✅ What Is Correct
- Dual SN65HVD230QDRG4Q1 transceivers (U6 ×2) correctly wired with 3.3V logic, eliminating the need for level shifting.
- CAN1: PD0 (RX) / PD1 (TX). CAN2: PB5 (RX) / PB6 (TX). Pin assignments are free of alternate function conflicts.
- PESD2CANFD24V-TR (D42, D43) ESD protection placed at the connector side.
- JST B2B-EH-A connectors (J41, J42) for the bus connection.
- Split termination network: 2× 60Ω (R29, R30) with a capacitor (C18) to GND.
- RS pin (Pin 8) connected to GND for high-speed mode.

### 🟢 CRI-CAN-01: Common-Mode Filter Capacitor Value Error [CORREGIDO]

**Finding:** The schematic originally showed C18 as **4.7 pF** on the split termination network.

**Risk:** The split termination capacitor ($2 \times 60\,\Omega + C_{CM}$) forms a common-mode low-pass filter. With a value of $4.7\,\text{pF}$, the cutoff frequency is $564\,\text{MHz}$, which provides no common-mode noise filtering in the critical $1-30\,\text{MHz}$ range, risking EMC test failure.

**Correction:**
- Change C18 from **4.7 pF** to **4.7 nF** (X7R, 50V, 0402 or 0603) to shift the filter cutoff to $564\,\text{kHz}$.
- **Status:** ✅ Corregido. El capacitor C18 se ha actualizado a **4.7 nF X7R**, proporcionando el filtrado de modo común necesario para cumplir con los estándares de compatibilidad electromagnética (EMC).

### 🟢 MAJ-CAN-02: RS Pin Grounded Without Slope Control Option [CORREGIDO]

**Finding:** Both transceivers originally had Pin 8 (RS) connected directly to GND.

**Risk:** With RS = GND, the transceiver operates in high-speed mode with maximum slew rate (~50 V/µs), maximizing EMI emissions and susceptibility to ringing on long bus cables.

**Correction:**
- Replace the direct GND connection with a **0Ω resistor footprint** (0402). Populate with 0Ω for high-speed mode, and allow swapping to 10kΩ-100kΩ for slope control if needed.
- **Status:** ✅ Corregido. Se ha reemplazado la conexión directa a GND por un footprint de resistencia de desacoplo/pendiente (**R_RS**). Por defecto se monta a **0Ω** para modo de alta velocidad, ofreciendo la flexibilidad de cambiar a **33kΩ** (control de pendiente) para mitigar emisiones EMI.

### 🟡 MIN-CAN-03: Missing Common-Mode Choke

**Finding:** No common-mode choke (CMC) is present between the TVS protection and the transceiver for either CAN channel.

**Risk:** For cables exceeding 1 meter in a noisy industrial environment, a CMC significantly improves common-mode rejection and reduces radiated emissions. Without it, the bus relies entirely on the split termination and the transceiver's internal common-mode rejection.

**Recommendation:**
- Add a footprint for a **CMC** (e.g., Würth 744232090, $Z_{CM} = 90\,\Omega\text{ @ }100\,\text{MHz}$, $Z_{DM} < 1\,\Omega$) between the TVS and the split termination on each channel. Populate as needed based on EMC testing results.

---

## 7. Analog Input Conditioning (0-10V, ×2)

**Status: 🔴 CRITICAL ISSUE (Previously Identified)**

### ✅ What Is Correct
- The hierarchical sheet approach (`ADC.SchDoc` instanced via `Repeat(CANAL, 1, 2)`) ensures identical conditioning for both channels.
- The OPA350EA/250 is a good choice: Rail-to-Rail I/O, 38 MHz GBW, low offset (150 µV max), single-supply.
- Anti-aliasing RC filter ($R_{20} = 1\,\text{k}\Omega$, $C_{12} = 100\,\text{nF}$, $f_c \approx 1.6\,\text{kHz}$) is well-dimensioned for industrial sensors.
- The Weidmüller 1845040000 terminal block provides robust screw-clamp connections.
- The TSV631AILT (U41) with R47 = 200kΩ, R48 = 10kΩ, R49 = 510Ω appears to form an indicator/status circuit, separate from the signal path.

### 🔴 CRI-ADC-01: Resistor Divider Scaling Error

**Finding:** The schematic shows R18 = **100kΩ** and R19 = **220kΩ**. This was flagged in the [Design Review 2026-05-18](Design_Review_2026-05-18.md) as producing a node voltage of:

$$V_{out} = V_{in} \times \frac{R_{19}}{R_{18} + R_{19}} = 10\,\text{V} \times \frac{220\text{k}}{100\text{k} + 220\text{k}} = 6.875\,\text{V}$$

This exceeds the 3.3V supply rail and the OPA350's absolute maximum input voltage ($V_{DD} + 0.3\,\text{V} = 3.6\,\text{V}$).

**Risk:** At 6.875V, the OPA350 input protection diodes will forward-bias, injecting current into the 3.3V rail. This will:
1. Latch the Op-Amp into an undefined state.
2. Potentially back-power the 3.3V rail through the protection diodes, raising the supply above 3.3V and corrupting every device on the bus.
3. Cause permanent degradation or destruction of the OPA350 under sustained overvoltage.

**This was previously identified as a critical error and has NOT been corrected.**

**Correction:**
- Change R18 and R19 to achieve a safe scaling factor. Target: $V_{out,max} = 3.0\,\text{V}$ at $V_{in} = 10\,\text{V}$ (leaves 300 mV headroom below the 3.3V rail):

$$\frac{R_{19}}{R_{18} + R_{19}} = \frac{3.0}{10.0} = 0.3$$

- **Option A (recommended):** R18 = **22kΩ**, R19 = **10kΩ**. $V_{out} = 10 \times 10/(22+10) = 3.125\,\text{V}$. Input impedance = 32kΩ (adequate for industrial sensors, >10kΩ output impedance is rare).
- **Option B (higher impedance):** R18 = **220kΩ**, R19 = **100kΩ**. $V_{out} = 10 \times 100/(220+100) = 3.125\,\text{V}$. Input impedance = 320kΩ. Higher impedance means more susceptibility to noise pickup; mitigate with shorter traces and shielding.

### 🔴 CRI-ADC-02: Unused Op-Amp Channel Not Configured

**Finding:** The OPA350EA/250 (U5) is a dual-channel device in an MSOP-8/SOT-23-8 package. The second channel (U5B) has its inputs marked as NC (No Connect) in the schematic.

**Risk:** A floating input on any operational amplifier — especially a high-bandwidth device like the OPA350 (38 MHz GBW) — will:
1. Self-oscillate at or near the gain-bandwidth product frequency.
2. Generate high-frequency noise that couples into the adjacent channel (U5A) through the shared supply pins.
3. Draw excessive supply current (potentially 5-10× quiescent), stressing the analog supply rail.

**This was previously identified as a critical error and has NOT been corrected.**

**Correction:**
- Configure U5B as a unity-gain buffer with its input tied to a known DC potential:
  - Connect U5B **non-inverting input (Pin 5)** to **AGND** (via a 1kΩ resistor to prevent noise injection).
  - Connect U5B **output (Pin 7)** directly to **inverting input (Pin 6)**.
  - This forces U5B to output a stable 0V (AGND) with minimal current draw.

### 🟡 MIN-ADC-03: ADC Pin Assignment Discrepancy

**Finding:** The wiki ([Microcontroller.md](Microcontroller.md)) states the analog inputs are on **PA3** (ADC_CH1) and **PC0** (ADC_CH2). However, the schematic's connector sheet shows the ADC module outputs connecting to **PB0** and **PB1** (ADC12_IN8 / ADC12_IN9) through the conditioning circuit, while the [analog-conditioning.md](../peripherals/analog-conditioning.md) article references PB0/PB1 as the MCU inputs.

**Risk:** If the wiki documentation is out of sync with the schematic, firmware development will target the wrong pins, requiring last-minute pin remapping or, worse, a board re-spin.

**Recommendation:**
- **Verify and reconcile:** Open the schematic (Sheet 4, Connectors) and trace the physical net from the Op-Amp output through the RC filter to the MCU pin. Update the wiki to match the actual schematic net assignment. The schematic is the source of truth.

---

## 8. SPI Flash Memory (SST25VF040B)

**Status: 🟡 MINOR ISSUES**

### ✅ What Is Correct
- The SST25VF040B (U7) is correctly wired: CE# (Pin 1), SO (Pin 2), WP# (Pin 3), VSS (Pin 4), SI (Pin 5), SCK (Pin 6), HOLD# (Pin 7), VDD (Pin 8).
- 10kΩ pull-up (R31) on CE# line for default deselection.
- 100nF decoupling capacitor (C21) on VDD.
- Series termination resistor (R32 = 33Ω) on SCK to dampen reflections.
- WP# and HOLD# are tied to VDD (3.3V), disabling write protection and hold functions.

### 🟡 MIN-SPI-01: Missing Series Resistor on MOSI (SI) Line

**Finding:** Only the SCK line has a series termination resistor (R32 = 33Ω). The MOSI (SI) and MISO (SO) lines have no series termination.

**Risk:** At SPI clock speeds above 25 MHz, the MOSI line can exhibit ringing and overshoot at the flash IC input. The MISO line is driven by the flash and terminated by the MCU's internal impedance, so it is less critical.

**Recommendation:**
- Add a **33Ω 0402** resistor in series with the MOSI line (SI, Pin 5), placed close to the MCU output pin (PB15). This matches the SCK termination strategy and ensures clean edges at the flash input.

### 🟡 MIN-SPI-02: SPI Bus Exposed on Port B Alongside RMII

**Finding:** SPI2 uses PB10 (SCK), PB12 (CS), PB14 (MISO), PB15 (MOSI). These pins are on Port B, which also hosts PB13 (RMII_TXD1). On the LQFP-144 package, PB13 (Pin 74) is physically between PB12 (Pin 73) and PB14 (Pin 75).

**Risk:** RMII_TXD1 is a 50 MHz digital signal. Its physical adjacency to the SPI MISO line (PB14) creates a potential crosstalk path. While this is a layout concern more than a schematic issue, the pin assignment makes it impossible to avoid adjacency.

**Recommendation:**
- On the PCB layout, route RMII_TXD1 (PB13) on a different layer than the SPI signals where they emerge from the MCU, and ensure a solid GND reference plane between them.
- Consider adding a GND guard trace between PB13 and PB14 on the signal layer.

---

## 9. MCU Configuration & Boot

**Status: ✅ PASS (with notes)**

### ✅ What Is Correct
- BOOT0 (Pin 138) is tied to GND through a resistor (R58 = 100Ω) with a pull-down (R60 = 100Ω) and a push-button (B43) to 3.3V for manual bootloader entry. This is correct.
- NRST (Pin 25) has a 100nF filter capacitor (C43) and a push-button (B42, Black) for manual reset. This meets the datasheet recommendation.
- The user button (B41, Blue) is on PC13 with a series resistor (R62 = 330Ω) and is connected to USR_BTN. This is standard.
- PDR_ON (Pin 143) is connected directly to VDD, enabling the internal power-down reset. This is correct for normal operation.

### 🟡 MIN-MCU-01: User LEDs Conflict with SPI/RMII

**Finding:** The wiki states PB14 is assigned as "User LED (Red)". However, PB14 is also assigned as SPI2_MISO. Looking at the schematic, PB14 has a 100Ω resistor (R54 = 33Ω actually per the resistor label, but the LED assignment from the wiki is a documentation error).

**Risk:** If PB14 is truly dual-assigned (LED + SPI MISO), the LED load (typically 5-10 mA through a series resistor) will pull the MISO line and corrupt SPI data during flash operations.

**Recommendation:**
- **Verify the schematic net:** If PB14 is used for SPI MISO, do **not** connect an LED to it. Reassign the Red LED to a free GPIO (e.g., PE1, which appears to be used for a Green LED via R49 = 510Ω). Remove the LED documentation from PB14 in the wiki.

---

## 10. GPIO Extension Connector & ESD Protection

**Status: ✅ PASS**

### ✅ What Is Correct
- The 18×2 male header (CN41) exposes P5V, P3V3, and 16 GPIOs for external interfacing.
- 4× ESDA6V1BC6 arrays (D46, D47, D48, D49) provide ESD protection on all GPIO lines, placed between the connector and the MCU.
- The SWD connector (CN42, 6×1 header) includes TCK, TMS, SWO, NRST with 22Ω series resistors (R43, R44, R45, R46) for signal integrity and current limiting.
- The BAT60JFILM diode (D41) on the P5V line provides reverse-polarity protection.

### 🟡 MIN-GPIO-01: Schematic Annotation "MANTENER LO MAS CERCA POSIBLE DEL CONECTOR EN EL RUTADO Y EN PARALELO"

**Finding:** There is a design note on Sheet 4 instructing the layout engineer to place the ESD protection components as close to the connector as possible and route in parallel.

**Risk:** None. This is correct practice. The note is well-placed. However, formal design directives should be captured in the **Altium constraint system** (Design Rules), not as free-text annotations that can be missed.

**Recommendation:**
- Create a **Component Group** in Altium for the ESD protection components and set a **proximity constraint** (max distance from connector = 5 mm) as a formal DRC rule.

---

## 11. Decoupling Strategy & Component Summary

**Status: 🟡 MINOR ISSUES**

### ✅ What Is Correct
- 13× 100nF ceramic capacitors (C51-C63) on each VDD/VSS pin pair of the MCU.
- 1× 4.7µF bulk capacitor (C64) on VDD.
- 2× 2.2µF X7R (C48, C49) on VCAP pins.
- 1× 1µF X5R (C50) on BYPASS_REG (Pin 38).
- Separate AGND/GND domains with star grounding.

### 🟡 MIN-DEC-01: Capacitor Dielectric Not Specified for 100nF

**Finding:** All 100nF capacitors are listed as "100nF" without dielectric specification. In the BOM, these should be **X7R or X5R** dielectric to maintain effective capacitance under DC bias.

**Risk:** If the procurement team sources C0G/NP0 (which is acceptable for 100nF but expensive) or, worse, Y5V/Z5U (which can lose >80% capacitance at 3.3V DC bias), the decoupling effectiveness will be severely compromised.

**Recommendation:**
- Specify **X7R, 16V, 0402 or 0603** for all 100nF decoupling capacitors in the BOM. Add a BOM note: "No Y5V or Z5U substitutions permitted."

---

## 12. Summary of Outstanding Issues from Previous Design Review

The following items were identified in the [Design Review 2026-05-18](Design_Review_2026-05-18.md) and remain **uncorrected** in the schematic prints dated 2026-06-10:

| ID | Issue | Severity | Status |
| :--- | :--- | :--- | :--- |
| CRI-USB-01 | ESDA6V1BC6 on USB D+/D- (should be USBLC6-4SC6) | 🔴 CRITICAL | **FIXED** |
| CRI-CAN-01 | C18 = 4.7 pF (should be 4.7 nF) | 🔴 CRITICAL | **FIXED** |
| CRI-ADC-01 | R18/R19 divider outputs 6.87V (should be ≤3.125V) | 🔴 CRITICAL | **NOT FIXED** |
| CRI-ADC-02 | U5B floating inputs (unused Op-Amp channel) | 🔴 CRITICAL | **NOT FIXED** |

> [!CAUTION]
> **These four issues MUST be resolved before sending the design to the PCB fabrication house.** Any one of them individually is sufficient to render the board non-functional or cause permanent component damage on first power-up.

---

## 13. Complete Issue Tracker

| ID | Subsystem | Severity | Description | Action |
| :--- | :--- | :--- | :--- | :--- |
| CRI-ANA-01  | Analog Power | 🟢 | L41 = 100µH inductor instead of ferrite bead on VDDA | **RESOLVED:** Replaced L41 with Murata BLM18PG121SN1D ferrite bead and added 1µF cap. |
| CRI-USB-01  | USB | 🟢 | ESDA6V1BC6 on USB D+/D- (20 pF) | **RESOLVED:** Replaced D45 with USBLC6-4SC6 (3.5 pF). |
| CRI-CAN-01  | CAN Bus | 🟢 | C18 = 4.7 pF common-mode filter | **RESOLVED:** Changed C18 to 4.7 nF X7R. |
| CRI-ADC-01  | Analog Input | 🔴 | Divider outputs 6.87V to 3.3V Op-Amp | Change to R18=22kΩ, R19=10kΩ. |
| CRI-ADC-02  | Analog Input | 🔴 | U5B inputs floating (oscillation) | Wire U5B as unity-gain buffer to AGND. |
| MAJ-PDN-01  | Power | 🟢 | LDO output capacitance below datasheet minimum | **RESOLVED:** Verified C14 is 1µF, C16 remains 100nF (False Positive). |
| MAJ-ETH-01  | Ethernet | 🟠 | RMII series termination = 33Ω (should be 22Ω) | Change R7, R8, R17, R40 to 22Ω. |
| MAJ-ETH-02  | Ethernet | 🟠 | PHYAD0 set to broadcast address 0x00 | Acceptable for single-PHY. Document. |
| MAJ-CAN-02  | CAN Bus | 🟢 | RS pin hard-grounded, no slope control option | **RESOLVED:** Replaced GND connection with a resistor footprint. |
| MIN-PDN-02  | Power | 🟢 | Single bulk capacitor for MCU VDD cluster | **RESOLVED:** Added second 10µF bulk capacitor near Pin 72. |
| MIN-ANA-02  | Analog Power | 🟢 | VBAT unnecessary resistors | **RESOLVED:** Verified C50 is 1µF, no resistors connected (False Positive). |
| MIN-CLK-01  | Clocks | 🟡 | Missing 1MΩ feedback resistor on HSE | Add DNP footprint across PH0-PH1. |
| MIN-ETH-03  | Ethernet | 🟡 | Bob-Smith termination center-tap grounding | Verify connects to EARTH, not digital GND. |
| MIN-USB-02  | USB | 🟡 | No external D+ pull-up fallback | Add 1.5kΩ DNP footprint D+ to 3.3V. |
| MIN-CAN-03  | CAN Bus | 🟡 | No common-mode choke on CAN bus | Add CMC footprint (DNP by default). |
| MIN-ADC-03  | Analog Input | 🟡 | Wiki/schematic pin assignment discrepancy for ADC | Reconcile documentation. |
| MIN-SPI-01  | SPI Flash | 🟡 | No series resistor on MOSI line | Add 33Ω on PB15-SI. |
| MIN-SPI-02  | SPI Flash | 🟡 | PB13 (RMII) adjacent to PB14 (MISO) crosstalk risk | Layer separation + GND guard in layout. |
| MIN-MCU-01  | MCU Config | 🟡 | PB14 dual-assigned (LED + SPI MISO) in wiki | Verify and reconcile. |
| MIN-DEC-01  | Decoupling | 🟡 | 100nF capacitor dielectric not specified | Specify X7R in BOM. |
| MIN-GPIO-01 | GPIO/ESD | 🟡 | Layout note as free text instead of DRC rule | Create Altium proximity constraint. |

---

## 14. Verdict

**The board is NOT cleared for production in its current state.**

There are **2 critical issues** (🔴) remaining that will cause hardware damage or complete functional failure. Both of these were identified in the previous design review (2026-05-18) and remain unaddressed.

**Mandatory actions before fabrication:**
1. Fix all 2 remaining critical issues (CRI-ADC-01, CRI-ADC-02).
2. Fix the remaining major issue (MAJ-ETH-01).
3. Regenerate schematic prints and submit for a **third review** before proceeding.

The 11 remaining minor issues (🟡) should be addressed during the revision cycle but do not individually block production.

## See Also

- [Design Review 2026-05-18](Design_Review_2026-05-18.md)
- [Hardware Architecture](Hardware_Architecture.md)
- [Component Selection](../peripherals/Components.md)
- [Design Technologies & Methods](Technologies_Methods.md)
- [Ethernet Interface](../peripherals/ethernet-interface.md)
- [CAN Interface](../peripherals/can-interface.md)
- [USB Design](../peripherals/usb-design.md)
- [Analog Conditioning](../peripherals/analog-conditioning.md)
- [SPI Protocol](../peripherals/SPI_Protocol.md)
- [GPIO Protection](../protection/gpio-protection.md)

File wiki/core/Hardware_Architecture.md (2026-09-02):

# Hardware Architecture: STM32F746ZG PCB

Design strategies for power, clocking, and signal integrity.

## ⚡ Power Delivery Network (PDN)
The STM32F746ZG requires multiple stable voltage rails.

### Decoupling Requirements
- **VDD Pins:** Each VDD pin requires a 100 nF ceramic capacitor.
- **Bulk Capacitance:** Distributed bulk capacitors: 1x 4.7 µF near VDD_9 (Pin 95) and 1x 10 µF X5R 0805 near VDD_1 (Pin 72). See [PDN Decoupling Theory](PDN_Decoupling_Theory.md) for loop inductance and DC bias derating analysis. **[Corrected: added 10 µF capacitor to resolve MIN-PDN-02]**.
- **LDO Decoupling:** Output decoupling has C14 (1 µF) + C15 (100 nF) + C16 (100 nF) to satisfy the LD39050 regulator stability requirements. **[Verified: C14 already provides the 1 µF capacitance, meaning C16 remains at 100 nF and no modification was required to resolve MAJ-PDN-01]**.
- **VDDA:** 100 nF + 1 µF close to pin. Use a ferrite bead for isolation from VDD.
- **VCAP:** 2x 2.2 µF low-ESR ceramic capacitors (VCAP_1, VCAP_2) to VSS. **CRITICAL.**
- **Peripheral Power:** Most peripherals (USB, CAN, SPI Flash) operate on the **3.3V rail**. Ensure LDO can handle the combined peak current.

## 🕒 Clock Distribution
- **HSE:** 8 MHz crystal on PH0/PH1.
- **LSE:** 32.768 kHz crystal on PC14/PC15.
- **Ethernet:** 50 MHz RMII_REF_CLK sourced from PHY to PA1.

## 🛡 Signal Integrity & Layout
Detailed guidelines for complex interfaces are maintained in their respective articles:
- **USB:** See [USB Design Guidelines](../peripherals/usb-design.md) ($90 \Omega$, ESD).
- **CAN:** See [CAN Interface](../peripherals/can-interface.md) ($120 \Omega$, dual hierarchy).
- **SPI Protocol:** See [SPI Protocol](../peripherals/SPI_Protocol.md) ($33 \Omega$, drive strength).
- **Ethernet:** See [Ethernet Interface](../peripherals/ethernet-interface.md) ($100 \Omega$ diff, LAN8742A, RMII).

- **Analog (0-10V):** 
    - Use a **22k / 10k** resistor divider to scale 10V to 3.125V.
    - Implement an **Op-Amp Buffer** (e.g., TLV9002) for each channel to ensure high input impedance and protect MCU pins.
- **Manual Boot Selection:**
    - Use a **10k $\Omega$ pull-down** on BOOT0 for default Flash boot.
    - Add a **push-button** to 3.3V (with a 100 $\Omega$ series resistor) to manually enter the Bootloader.

## 📐 PCB Stack-up
- **Layers:** 4 layers (Signal / GND / PWR / Signal).
- **Thickness:** Max **1.6 mm** (Lab Circuits).
- **Fabrication Class:** **Clase 5** (required by via drill 0.3 mm — AR = 5.33 > Clase 4 limit; annular ring 0.19 mm). See [Manufacturing Constraints](Manufacturing_Constraints.md).
- **Via stitching:** Drill 0.3 mm / Pad **0.68 mm** (DFM corrected from 0.6 mm). See [Via Stitching & GND Guard Rings](Via_Stitching_GND_Guard_Rings.md).
- **Mounting:** 4x 3.5mm holes connected to **EARTH**.

[Source: stm32f746zg.pdf, dm00244518.pdf, Project Proposal, Lab Circuits - Tablas de parámetros.pdf]

## See Also

- [Reference Designs](Reference_Designs.md) — Key design patterns and insights from the Nucleo-F746ZG reference board.

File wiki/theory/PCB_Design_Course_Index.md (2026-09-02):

# PCB Design Course Index: Theory & Best Practices

> Sources: Sergio Lopez-Buedo, UAM (MUISE), 2025/2026; STMicroelectronics; Texas Instruments; Intel
> Raw: [raw/teory/](../../raw/teory/)

## Overview

This index structures the theoretical and practical knowledge from the PCB Design course materials added to the `raw/teory/` directory. It organizes the 25 reference documents into 5 thematic blocks to assist in design reviews, signal integrity simulations, stack-up definitions, and electromagnetic compatibility (EMC) compliance.

---

## 🗺️ Thematic Blocks

### Block 1: Design Flow & Altium Designer
Reference materials for schematic capture, advanced footprints, libraries, and layout routing workflow.

*   **1a - Vista general y flujo de diseño:** [PDF](../../raw/teory/1a_-_Vista_general_y_flujo_de_dise_o.pdf)
    *   *Topics:* Conception, schematics, routing, manufacturing output (Gerbers/ODB++), assembly.
*   **1b - Tutorial Altium Designer - Version 20.2:** [PDF](../../raw/teory/1b_-_Tutorial_Altium_Designer_-_Version__20.2.pdf)
    *   *Topics:* Altium interface, project creation, schematic libraries, PCB rules, routing.
*   **2a - Altium - Esquemas avanzados:** [PDF](../../raw/teory/2a_-_Altium_-_Esquemas_avanzados.pdf)
    *   *Topics:* Hierarchical schematics, multi-channel design, net classes, bus routing.
*   **3a - Altium - Librerías:** [PDF](../../raw/teory/3a_-_Altium_-_Librer_as.pdf)
    *   *Topics:* Schematic library symbols, PCB footprint footprints, 3D body integration, IPC-compliant footprints.
*   **4-5-6 Altium - Diseño de Layout:** [PDF](../../raw/teory/4-5-6_Altium_-_Dise_o_de_Layout.pdf)
    *   *Topics:* Placement strategy, routing engines, length matching, design rule checks (DRC).

### Block 2: Signal Integrity & Transmission Lines
Physics of high-speed signals, return currents, impedance matching, reflections, and crosstalk.

*   **4a - Integridad de Señal - Metodología de Diseño:** [PDF](../../raw/teory/4a_-_Integridad_de_Se_al_-_Metodolog_a_de_Dise_o.pdf)
    *   *Topics:* Rise time ($t_r$), bandwidth, lumped vs. distributed circuits, high-speed threshold ($l > \frac{v \cdot t_r}{6}$).
*   **5a - Caminos de retorno - Pistas en un PCB - Crosstalk:** [PDF](../../raw/teory/5a_-_Caminos_de_retorno_-_Pistas_en_un_PCB_-_Crosstalk.pdf)
    *   *Topics:* Return current paths (minimum impedance path), microstrip vs. stripline geometry, capacitive/inductive crosstalk, spacing rules ($3W$ rule).
*   **5b - Reflexiones y Terminaciones:** [PDF](../../raw/teory/5b_-_Reflexiones_y_Terminaciones.pdf)
    *   *Topics:* Transmission lines, characteristic impedance ($Z_0$), reflection coefficient ($\Gamma$), termination topologies (series, parallel, AC, differential).
*   **7 - Líneas diferenciales:** [PDF](../../raw/teory/7_-_L_neas_diferenciales.pdf)
    *   *Topics:* Differential signals, odd/even mode impedance, differential impedance ($Z_{diff}$), routing rules (symmetric, no vias, length matching).
*   **TI - AN-806 Data Transmission Lines:** [PDF](../../raw/teory/TI_-_AN-806_Data_Transmission_Lines_and_Their_Characteristics_-_snla026a.pdf)
    *   *Topics:* Classic transmission line theory, coaxial cables, twisted pairs, microstrip math.
*   **TI - AN-807 Reflections Computations:** [PDF](../../raw/teory/TI_-_AN-807_Reflections_Computations_and_Waveforms_-_snla027b.pdf)
    *   *Topics:* Graphical reflection analysis, lattice diagrams, overshoot/undershoot equations.
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

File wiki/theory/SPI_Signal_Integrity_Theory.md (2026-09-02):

# SPI Signal Integrity — Teoría de Líneas de Transmisión

> Sources: Altium Resources Blog (Zachariah Peterson), 2026-02-17
> Raw: [2026-06-13-altium-spi-trace-impedance-signal-integrity.md](../../raw/articles/2026-06-13-altium-spi-trace-impedance-signal-integrity.md); [Articulo_altium_SPI_SI.md](../../raw/articles/Articulo_altium_SPI_SI.md)

## Overview

El bus SPI no tiene un requisito de impedancia de traza especificado en el estándar. Sin embargo, los fenómenos de integridad de señal — ringing, reflexiones, crosstalk — sí pueden aparecer, y su severidad depende de si el bus es eléctricamente "largo" o "corto" respecto al tiempo de subida de la señal. Este artículo sintetiza la teoría completa: criterio de longitud eléctrica, modelos de circuito equivalente, estrategias de terminación y
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

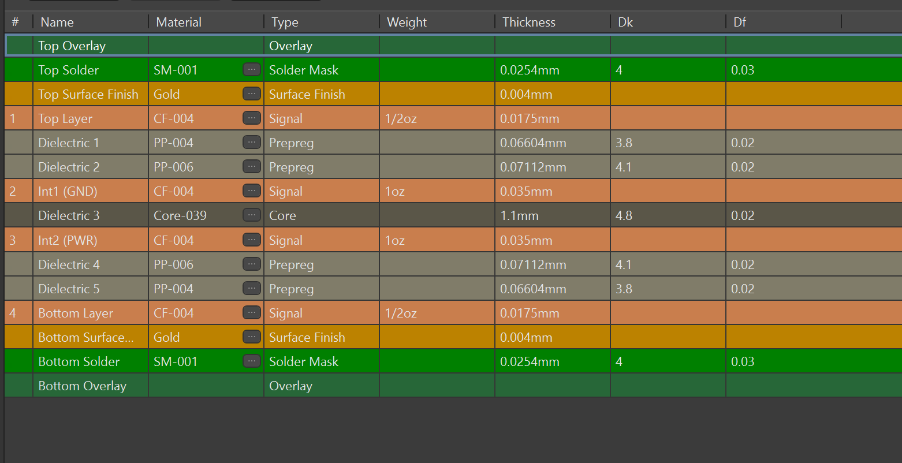
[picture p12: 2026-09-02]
informe/Imagenes/Captura_stackup.png

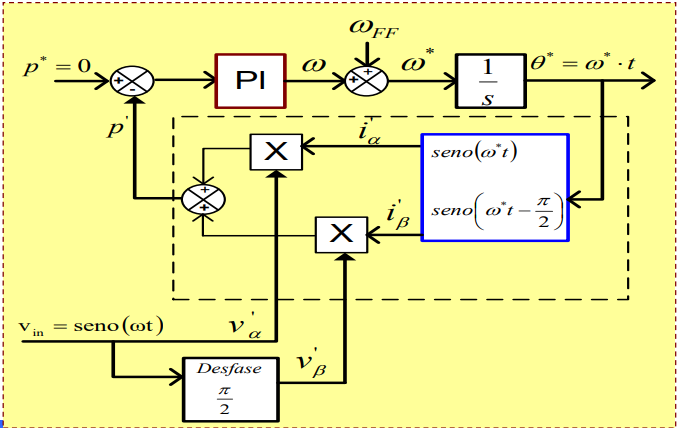
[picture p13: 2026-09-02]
informe/Imagenes/Pelele.png

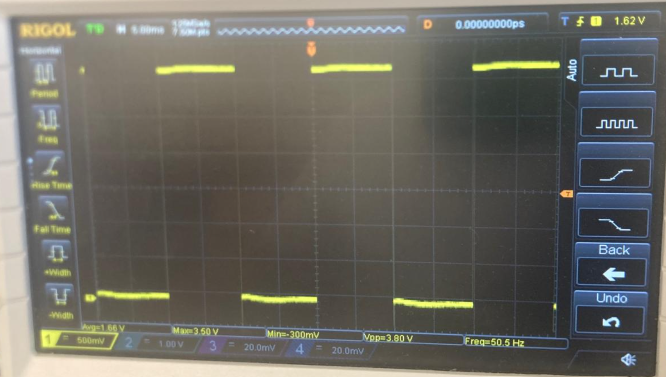
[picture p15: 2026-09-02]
informe/Imagenes/positivo.png

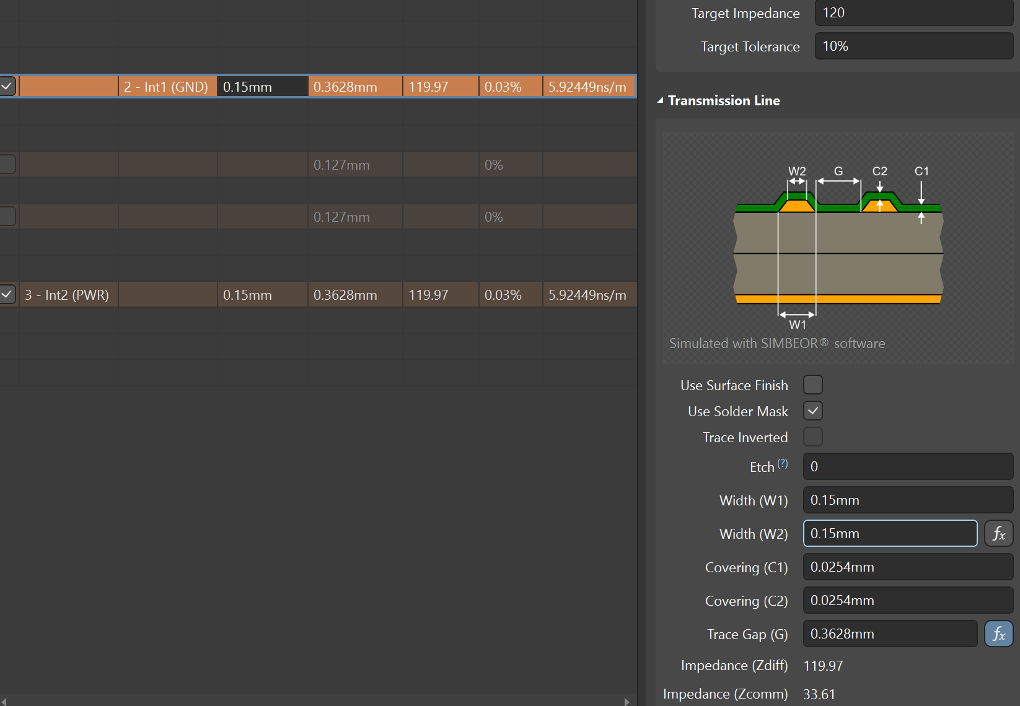
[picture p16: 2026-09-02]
informe/Imagenes/diffPair_CAN.png

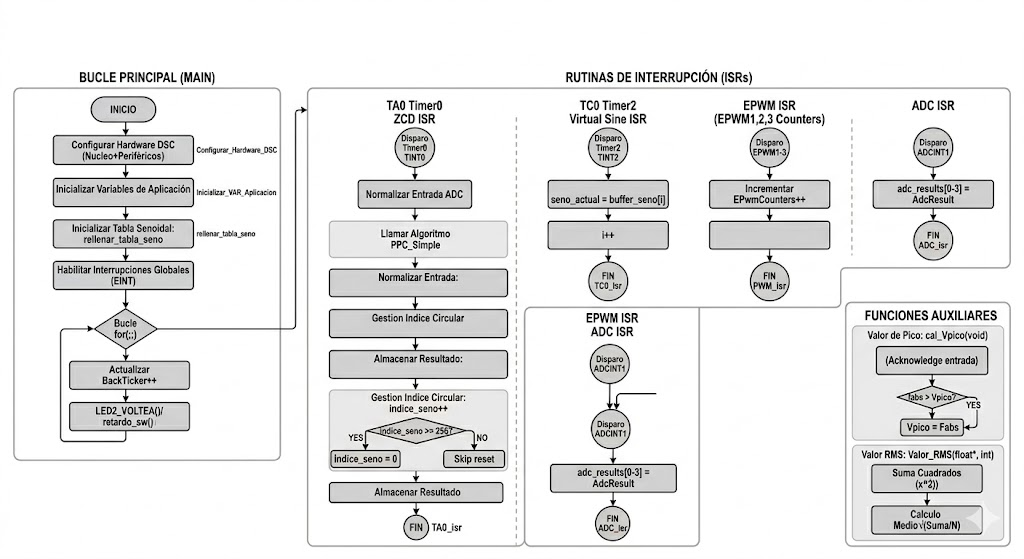
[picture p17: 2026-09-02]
informe/Imagenes/flujogramaA.png

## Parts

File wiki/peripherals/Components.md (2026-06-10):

# Component Selection: Selected Parts Database

> Sources: Joan San Bartolome, 2026-06-10; STMicroelectronics, 2016-02-15; Microchip, 2015-08-01; Texas Instruments, 2003-09-12
> Raw: [STM32_Esqumaticos.pdf](../../raw/prints/STM32_Esqumaticos.pdf); [sn65hvd230q-q1.pdf](../../raw/datasheets/sn65hvd230q-q1.pdf); [SST25VF040B-4-Mbit-SPI-Serial-Flash-Data-Sheet-20005051F.pdf](../../raw/datasheets/SST25VF040B-4-Mbit-SPI-Serial-Flash-Data-Sheet-20005051F.pdf); [1845040000_en.pdf](../../raw/datasheets/1845040000_en.pdf); [esda6v1bc6.pdf](../../raw/datasheets/esda6v1bc6.pdf); [Murata-BLM18PG121SN1D-datasheet.pdf](../../raw/datasheets/Murata-BLM18PG121SN1D-datasheet.pdf)

## Overview
This document lists the selected integrated circuits, passive networks, protection devices, and connectors chosen for the custom STM32F746ZG PCB, extracted from the schematic prints and layout constraints.

## 🎛️ Microcontroller & Clocking

### 1. STM32F746ZGT6 (MCU)
*   **Manufacturer:** STMicroelectronics
*   **Package:** LQFP-144 (20x20 mm, 0.5 mm pitch)
*   **Architecture:** ARM Cortex-M7 with FPU, running up to 216 MHz.
*   **Pin Mapping Role:** Central controller managing RMII MAC, bxCAN1/2, SPI2, ADC, and USB OTG FS.
*   **Design Constraints:** Requires 13x 100nF decoupling capacitors, 1x 4.7µF bulk capacitor, and 2x 2.2µF low-ESR ceramic capacitors on VCAP pins (VCAP_1 Pin 71, VCAP_2 Pin 106) for core voltage regulation.

### 2. Seiko Epson NX3215SA (32.768 kHz Crystal)
*   **Application:** LSE (Low-Speed External) Clock for Real-Time Clock (RTC).
*   **Frequency:** 32.768 kHz
*   **Load Capacitance:** 4.3 pF (requires no external capacitors as indicated by `[N/A]` on C41 and C42 in schematics).

### 3. NDK NX3225GD-8.000M (8.000 MHz Crystal)
*   **Application:** HSE (High-Speed External) Clock for main PLL configuration.
*   **Frequency:** 8.000 MHz
*   **Capacitance:** 4.3 pF load (C45, C47).

### 4. NDK X53T-C20SSA-25.000MHz (25.000 MHz Crystal)
*   **Application:** Reference oscillator for LAN8742A Ethernet PHY.
*   **Frequency:** 25.000 MHz
*   **Load Capacitance:** 30 pF (C6, C11).

---

## 💾 Storage & Peripherals

### 5. SST25VF040B-50-4I-S2AF (SPI NOR Flash)
*   **Manufacturer:** Microchip / Silicon Storage Technology (SST)
*   **Package:** SOIC-8 (150 mil width)
*   **Density:** 4 Mbit (exceeds 2 Mbit requirement).
*   **Bus Speed:** Up to 50 MHz.
*   **Interface:** SPI (connected to SPI2: CE# on PB12, SO on PB14, SI on PB15, SCK on PB10).
*   **Methods Applied:** Series damping resistor ($33\,\Omega$ on SCK line, R32) to prevent reflection; $10\,\text{k}\Omega$ pull-up resistors on WP#, HOLD#, and CE# (R31) lines.

### 6. LAN8742A-CZ-TR (Ethernet PHY)
*   **Manufacturer:** Microchip / SMSC
*   **Package:** QFN-24 (4x4 mm, exposed pad grounded via Pin 25).
*   **Function:** 10/100 Ethernet Transceiver.
*   **Interface:** RMII (Reduced Media Independent Interface) connected to MCU.
*   **Requirements:** Solder the exposed center thermal pad directly to the GND plane. Use an external $12.1\,\text{k}\Omega$ 1% bias resistor (R15) on RBIAS (Pin 24).

### 7. SN65HVD230QDRG4Q1 (CAN Transceiver - x2)
*   **Manufacturer:** Texas Instruments
*   **Package:** SOIC-8
*   **Supply Voltage:** 3.3V (avoids 5V levels on logic lines).
*   **Role:** Dual-node transceiver interfacing CAN1 (TX on PD1, RX on PD0) and CAN2 (TX on PB6, RX on PB5).
*   **Aesthetics/Performance:** Slope control configurable via pin 8 (RS) with grounding resistor to adjust EMI emission profile.

### 8. OPA350EA/250 (Analog Buffer Op-Amp - x2)
*   **Manufacturer:** Texas Instruments
*   **Package:** Micro6 (SOT-23-5)
*   **Function:** High-speed Rail-to-Rail input/output operational amplifier configured as a voltage follower buffer for Analog Inputs.
*   **Supply:** 3.3V analog rail (AVDD).

### 9. TSV631AILT (General Purpose Op-Amp)
*   **Manufacturer:** STMicroelectronics
*   **Package:** SOT-23-5
*   **Function:** 3.3V operational amplifier for auxiliary analog functions (e.g. driving indicators or conditioning auxiliary inputs).

---

## ⚡ Power Management & Protection

### 10. LD39050PU33R (LDO Regulator)
*   **Manufacturer:** STMicroelectronics
*   **Package:** DFN-6 (3x3 mm)
*   **Function:** Low-Dropout regulator scaling 5V USB power to 3.3V system power.
*   **Max Current:** 500 mA.
*   **Integrity:** Features Power Good pin (PG) used to drive indicators or control resets, and Enable pin (EN).

### 11. USBLC6-4SC6 (ESD Protection Array - x2)
*   **Manufacturer:** STMicroelectronics
*   **Package:** SOT-23-6L
*   **Capacitance:** Ultra-low ($3.5\,\text{pF}$) to maintain signal integrity on high-speed lines.
*   **Application:**
    *   **USB Port:** D45 on USB_DM/USB_DP lines.
    *   **Ethernet MDI:** U11 protecting TX+/TX- and RX+/RX- differential pairs.

### 12. PESD2CANFD24V-TR (CAN Bus ESD protection - x2)
*   **Manufacturer:** Nexperia
*   **Package:** SOT-23
*   **Function:** Dual-line ESD protection designed specifically for CAN FD and CAN high-speed buses.
*   **Placement:** D42 (CAN2) and D43 (CAN1) placed adjacent to bus terminal connectors.

### 13. ESDA6V1BC6 (TVS Diode Array - x4)
*   **Manufacturer:** STMicroelectronics
*   **Package:** SOT-23-6
*   **Function:** 4-channel bidirectional ESD protection array for GPIO extension headers.
*   **Application:** D46, D47, D48, and D49 located on Sheet 4 to protect external GPIO interfaces from electrostatic discharge.

### 14. Bourns MF-MSMF050-2 (PPTC Resettable Fuse)
*   **Role:** Overcurrent protection on VBUS USB input line.
*   **Rating:** 500 mA hold current.

### 15. Murata BLM18PG121SN1D (Ferrite Bead)
*   **Manufacturer:** Murata
*   **Package:** 0603 (1608 Metric)
*   **Electrical Specs:** $Z = 120\,\Omega \pm 25\%$ @ $100\,\text{MHz}$, $\text{DCR} \le 50\,\text{m}\Omega$, $I_{rated} = 2.0\,\text{A}$.
*   **Application:** L41 on the $V_{DDA}$ / $V_{REF+}$ analog supply line to isolate high-frequency digital noise from the sensitive analog domain.
*   **Design Rationale:**
    *   **Ultra-low DCR:** At $2-5\,\text{mA}$ ADC consumption, the voltage drop is $< 0.15\,\text{mV}$ ($< 0.18\,\text{LSBs}$ at 12-bit), preserving DC measurement accuracy.
    *   **Current Saturation Margin:** The $2.0\,\text{A}$ current rating prevents magnetic saturation under normal operating current ($< 5\,\text{mA}$), maintaining full $120\,\Omega$ filtering impedance.
    *   **Resonance Damping:** Unlike standard inductors (e.g., $100\,\mu\text{H}$), its high resistive component at high frequencies ($> 30\,\text{MHz}$) absorbs and dissipates noise as heat, preventing anti-resonance peaks on $V_{DDA}$.

---

## 🔌 Connectors & Terminal Blocks

### 16. Weidmüller 1845040000 (Analog Terminal Block)
*   **Series:** OMNIMATE Signal LM 3.50.
*   **Specs:** 4-pole PCB terminal block, 3.50 mm pitch, 90° entry, screw clamping connection.
*   **Application:** J41 for 0-10V Analog inputs.

### 17. JST B2B-EH-A(LF)(SN) (CAN Connectors)
*   **Specs:** 2-pole shroud header, 2.50 mm pitch, top entry.
*   **Application:** J42 for CAN bus physical connections.

### 18. KRJ-CB4.2GYZNL (RJ45 Ethernet Jack)
*   **Role:** Ethernet connection with integrated magnetics and status LEDs.
*   **Details:** LED1 (Green) and LED2 (Yellow) connected via series resistors to the LAN8742A LED pins.

### 19. Molex 475900001 (Micro-USB Receptacle)
*   **Specs:** Micro-USB Type AB receptacle, bottom mount.

## See Also

*   [Design Technologies & Methods](../core/Technologies_Methods.md)
*   [CAN Interface](can-interface.md)
*   [Ethernet Interface](ethernet-interface.md)
*   [Analog Conditioning](analog-conditioning.md)
*   [USB Design](usb-design.md)
*   [SPI Protocol](SPI_Protocol.md)

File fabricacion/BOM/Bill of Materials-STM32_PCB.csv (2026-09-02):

Name | Description | Designator | Footprint | LibRef | Quantity
RESET (Black) | SE PUSHBUTTON | B41 | PB-6X6mm-Black | SW PUSHBUTTON | 1
USER (Blue) | SE PUSHBUTTON | B42 | PB-6X6mm-Blue | SW PUSHBUTTON | 1
BOOT0 | SE PUSHBUTTON | B43 | PB-6X6mm-Blue | SW PUSHBUTTON | 1
100nF | Capacitor 0402 / 0603 / 0805, Capacitor | C1, C4, C5, C6, C10, C11, C15, C16, C17_U_ADC1, C17_U_ADC2, C18_U_ADC1, C18_U_ADC2, C21_U_Can1, C21_U_Can2, C22, C43, C45, C48, C49, C50, C51, C52, C56, C57, C58, C59, C61, C62, C63, C64, C65 | 0603C | Capacitor_ST, CAP | 31
30pF | Capacitor 0402 / 0603 / 0805 | C2, C12 | 0603C | Capacitor_ST | 2
470pF | Capacitor 0402 / 0603 / 0805 | C3 | 0603C | Capacitor_ST | 1
TC1206KKX7RDBB102 | Capacitor 0402 / 0603 / 0805/ 1206 | C7 | 1206C | Capacitor_ST | 1
10uF | Polarized Capacitor,10uF,10V,10%,typeA,VISHAY | C8 | TAN-A | Cap_10uF_POL_10%_TANA | 1
1uF_X5R_0603 | 0603 X5R 1µF | C9, C60 | 0603C | CAP SMD 0603 X5R 1µF 25V 10% | 2
1uF | 0603 X5R 1µF, Capacitor | C13, C14, C46 | 0603C | CAP SMD 0603 X5R 1µF 25V 10%, Cap | 3
4.7nF | Capacitor | C19_U_Can1, C19_U_Can2 | 0603C | CAP | 2
47uF | Capacitor | C20_U_Can1, C20_U_Can2 | 0603C | CAP | 2
4.3pF[N/A] | Capacitor | C41, C42 | 0603C | CAP | 2
4.3pF | Capacitor | C44, C47 | 0603C | CAP | 2
2.2uF_X7R | Capacitor,2.2uF,16V, X7R,10%,0805,YAGEO | C53, C55 | TAN-A | Cap_2.2uF_X7R_10%_0805 | 2
10uF_X5R_0603 | 0603 X5R 4.7uF | C54 | 0603C | CAP SMD 0603 X5R 1µF 25V 10% | 1
4.7uF_X5R_0603 | 0603 X5R 4.7uF | C66 | 0603C | CAP SMD 0603 X5R 1µF 25V 10% | 1
KRJ-CB4.2GYZNL | 100 Base-TX (Fast Ethernet) SMD RJ45 single port (1x1) with LEDS Integrated Magnetics Connector | CN1 | RJ45_KRJ-CB4.2GYZNL | KRJ-CB4.2GYZNL | 1
Header 18X2_Male | Header, 18-Pin, Dual row,male | CN41 | HDR_2x18_2R54_V_M | Header 18X2_Male | 1
Header 6X1 | Header, 6-Pin, Single row | CN42 | HDR_1x6_2R54_V_M | Header 6X1 | 1
475900001 |  | CN43 | MOLEX_47590001 | 475900001 | 1
BAT60JFILM | BAT60JFILM | D41, D48 | SOD-323 | BAT60JFILM | 2
ESDA6V1BC6 | 4-line ESD protection | D42, D43, D46, D47 | SOT23-6L | ESDA6V1BC6 | 4
PESD2CANFD24V-TR | TVS DIODE 24VWM 42VC TO236AB | D44, D45 | FP-SOT23-IPC_A | CMP-14436-000014-1 | 2
1845040000 | OMNIMATE Signal - series LM | E41 | LM_3_5_90_04 | CMP-1559-01732-1 | 1
MF-MSMF050-2 | PTC RESET FUSE 15V 500MA 1812 | F41 | FP-MF-MSMF050-2-MFG | CMP-2100-03653-2 | 1
BLM18PG121SN1D | Chip Ferrite Bead, 0603, 120O @ 100MHz, 0.05O, 25%, 2A | FB41 | FP-BLM18-0_15-t0_8-IPC_A | CMP-0686-00557-7 | 1
B2B-EH-A(LF)(SN) | CONN HEADER VERT 2POS 2.5MM | J41, J42 | FP-B2B-EH-A_LF_SN-MFG | CMP-17439-000026-1 | 2
BEAD | Inductor | L1 | 0603L | Inductor | 1
Green | Typical RED, GREEN, YELLOW, AMBER GaAs LED | LD1, LD2, LD41 | 0603D-G | LED2 | 3
Red | Typical RED, GREEN, YELLOW, AMBER GaAs LED | LD42 | 0603D-R | LED2 | 1
Blue | Typical RED, GREEN, YELLOW, AMBER GaAs LED | LD43 | 0603D-B | LED2 | 1
50 | Resistor,50,0603,1%,YAGEO | R1, R2, R6, R7 | 0603R | Res_50_1%_0603 | 4
10K | Resistor 0402 / 0603 / 0805, Resistor | R3, R4, R5, R10, R18, R21, R33, R41, R48, R52 | 0603R | Resistor_ST, Res1 | 10
33 | Resistor,33,0402,1%,YAGEO, Resistor | R8, R9, R16, R19, R34, R55, R60 | 0603R | Res_33_1%_0402, Res1 | 7
75 | Resistor,75,0603,1%,YAGEO | R11, R12, R13, R14 | 0603R | Res_75_1%_0603 | 4
12K1 | Resistor,12K1,0603,1%,VISHAY | R15 | 0603R | Res_12K1_1%_0603 | 1
1K5 | Resistor,1K5,0402,1%,YAGEO | R17 | 0603R | Res_1K5_1%_0402 | 1
270 | Resistor 0402 / 0603 / 0805 | R20, R22 | 0603R | Resistor_ST | 2
330 | Resistor | R23, R66, R74 | 0603R | res1 | 3
1K | Resistor 0402 / 0603 / 0805, Resistor | R24, R28_U_ADC1, R28_U_ADC2, R50 | 0603R | Resistor_ST, Res1 | 4
47K | Resistor | R25 | 0603R | res1 | 1
22K | Resistor | R26 | 0603R | res1 | 1
100K | Resistor 0402 / 0603 / 0805 | R27_U_ADC1, R27_U_ADC2 | 0603R | Resistor_ST | 2
220K | Resistor 0402 / 0603 / 0805, Resistor | R29_U_ADC1, R29_U_ADC2, R76, R78 | 0603R | Resistor_ST, res1 | 4
60 Ohm | Resistor | R30_U_Can1, R30_U_Can2, R32_U_Can1, R32_U_Can2 | 0603R | Res1 | 4
0 Ohm | Resistor | R31_U_Can1, R31_U_Can2 | 0603R | Res1 | 2
100 | Resistor 0402 / 0603 / 0805, Resistor | R42, R51, R54, R56, R57, R58, R59, R61, R62, R63, R64, R65, R67, R68, R69, R70, R73, R75, R77 | 0603R | Resistor_ST, Res1 | 19
22 | Resistor 0402 / 0603 / 0805 | R43, R44, R45, R46 | 0603R | Resistor_ST | 4
200K | Resistor | R47 | 0603R | res1 | 1
510 | Resistor | R49 | 0603R | Res1 | 1
680 | Resistor | R53 | 0603R | Res1 | 1
0 | Resistor | R71, R72 | 0603R | Res1 | 2
Close | Circuit Breaker | SB41 | SB_0603 | Circuit Breaker | 1
9013 | NPN Bipolar Transistor | T1 | SOT-23 | NPN | 1
USBLC6-4SC6 |  | U1, U43 | SOT23-6L | USBLC6-4SC6 | 2
KMS-1102NL |  | U2 | Transformer | KMS-1102NL | 1
LAN8742A-CZ-TR | LAN8742A-CZ-TR - Small Footprint RMII 10/100 Ethernet, Transceiver with HP Auto-MDIX and flexPWR Technology SQFN-24 | U3 | QFN24_0R5_4X4 | LAN8742A-CZ-TR | 1
LD39050PU33R |  | U4 | DFN6_0R95_3x3_TP | LD39050P | 1
OPA350EA/250 | High-Speed, Single-Supply, Rail-to-Rail Operational Amplifier MicroAmplifier(TM) Series, 2.7 to 5.5 V, -40 to 85 degC, 8-pin SOP (DGK8), Green (RoHS & no Sb/Br) | U5_U_ADC1, U5_U_ADC2 | DGK0008A_M | CMP-0272-01143-3 | 2
SN65HVD230QDRG4Q1 | Automotive Catalog 3.3 V CAN Transceiver, 17 mA, -40 to 125 degC, 8-pin SOIC (D), Green (RoHS & no Sb/Br) | U6_U_Can1, U6_U_Can2 | D0008A_M | CMP-0315-00041-2 | 2
SST25VF040B-50-4I-S2AF | 4 Mbit SPI Serial Flash, 2.7 to 3.6 V, 50 MHz, -40 to 85 degC, 8-pin SOIC (S2A8), Tube | U7 | MCHP-SOIC-S2A8_N | CMP-0378-00057-1 | 1
TSV631AILT |  | U41 | SOT-23-5L | TSV631AILT | 1
MCU_LQFP144 |  | U42 | LQFP144_0R5_SKT - sin_zocalo_UWU | MCU_LQFP144 | 1
X53T-C20SSA-25.000MHz | Crystal Oscillator | X1 | XTAL_2SM_5R0X3R2 | XTAL_5032 | 1
NX3215SA-32.768KHZ-EXS00A-MU00525 | Crystal | X41 | XTAL_2SM_3R2X1R5 | CRYSTAL_32K | 1
NX3225GD-8.000M-EXS00A-CG04874 | Crystal Oscillator | X42 | OSC_2SM_3R2x2R5 | XTAL | 1

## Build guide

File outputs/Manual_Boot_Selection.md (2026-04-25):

# Manual Boot Selection Circuitry: STM32F746ZG

This document describes how to implement a manual boot selection circuit using a push-button, allowing the user to toggle between normal Flash boot and System Bootloader mode.

## 💡 Circuit Design
To provide manual control over the boot mode, the **BOOT0** pin must be biased using a pull-down resistor and connected to a high-voltage source (3.3V) through a switch.

### 🧩 Components
- **Push-button (S1):** Tactile switch connected between **3.3V** and the **BOOT0** network.
- **Pull-down Resistor (R1):** **10k $\Omega$** resistor connected between **BOOT0** and **GND**. This ensures the default state is Logic 0 (Flash Boot).
- **Current Limiting Resistor (R2):** **100 $\Omega$ to 1k $\Omega$** resistor in series between the switch and the BOOT0 pin. This protects the MCU pin against transients and potential accidental short circuits.

### 📐 Schematic Layout
```text
3.3V
 |
[ ] (S1 Push-button)
 |
 +-------[ R2 100R ]------- MCU BOOT0 (Pin 138)
 |
[R1 10k]
 |
GND
```

## 🕹 Operation
1. **Normal Operation (Button Open):** 
   - R1 pulls BOOT0 to GND.
   - MCU boots from **Flash Memory** (default user application).
2. **Manual Bootloader Entry (Button Pressed during Reset):**
   - Button connects BOOT0 to 3.3V (Logic 1).
   - User must press and hold S1 while toggling the **RESET** button.
   - MCU enters **System Bootloader** mode (allows programming via UART, USB, etc.).

## ⚠️ Design Considerations
- **Hysteresis:** The STM32F746ZG BOOT0 pin has built-in hysteresis (~10% VDD), which helps prevent false triggering due to noise.
- **Debouncing:** Hardware debouncing is generally not required for BOOT0 since its state is only sampled during the reset sequence.
- **Stability:** Place the 10k $\Omega$ pull-down physically close to the MCU pin to minimize noise pickup on the high-impedance trace.

[Source: stm32f746zg.pdf Section 6.3.17, dm00244518.pdf Section 7.14]

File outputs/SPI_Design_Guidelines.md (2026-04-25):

# SPI Protocol Design Guidelines: STM32F746ZG

This document outlines high-speed SPI implementation strategies for the STM32F746ZG microcontroller and the SST25VF040B Flash memory.

## ⚡ Electrical Characteristics
- **Maximum Frequency:** 
    - **SPI1, 4, 5, 6:** Up to **54 MHz** (Master mode, 2.7V $\le$ VDD $\le$ 3.6V).
    - **SPI2, 3:** Up to **27 MHz**.
    - **SST25VF040B Flash:** Supports up to **50 MHz**.
- **Logic Levels:** 3.3V CMOS. Use 5V tolerant pins (FT) when possible if interfacing with external shields.

## 🛡 Signal Integrity & Layout
To ensure reliable communication at high speeds (>20 MHz):
1. **Series Termination:** Place **33 $\Omega$ to 100 $\Omega$** resistors in series on the **SCK**, **MOSI**, and **CS** lines close to the MCU to minimize ringing and EMI.
2. **Impedance Control:** Aim for **50 $\Omega$** single-ended characteristic impedance for SPI traces.
3. **Trace Length Matching:** Keep SCK, MISO, and MOSI traces approximately the same length (within $\pm$ 10mm) to maintain timing margins.
4. **Ground Return:** Ensure a continuous ground plane directly beneath the SPI signal traces. Avoid routing SPI lines over splits in the power/ground planes.

## 🔗 Hardware Configuration
- **Chip Select (CS/NSS):** Use a **10k $\Omega$ pull-up resistor** to VDD to keep the Flash memory disabled during MCU reset and startup.
- **WP# and HOLD#:** For the SST25VF040B, tie these pins directly to **3.3V** if hardware write protection and pause functions are not required.
- **MISO Line:** If multiple slaves are used, ensure only one slave drives the MISO line at a time.

## ⚠️ Pin Conflict Awareness (Nucleo-144)
Be cautious when selecting pins to avoid overlapping with other mandatory project features:
- **Avoid PB13 and PA7:** These are used by the **Ethernet RMII** interface.
- **Avoid PA5:** Often shared with the onboard **User LED**.
- **Recommended for SPI Flash (SPI2):** 
    - SCK: PB10
    - MISO: PC2
    - MOSI: PC3
    - CS: PB12

[Source: stm32f746zg.pdf Section 6.3.26, dm00244518.pdf Section 7.11]

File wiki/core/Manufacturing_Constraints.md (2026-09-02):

# Manufacturing Constraints — Lab Circuits DFM

> Sources: Lab Circuits S.A., 2023-04-28
> Raw: [2026-06-13-lab-circuits-parametros-fabricacion.md](../../raw/manufacturing/2026-06-13-lab-circuits-parametros-fabricacion.md)

## Overview

Este artículo compila y analiza los parámetros de fabricación de **Lab Circuits S.A.** aplicados al diseño de la PCB STM32F746ZG Rev B-01. El fabricante ofrece 5 clases de precisión (3 a 7) con restricciones de mínimos crecientes en taladros, trazas, coronas y aislamientos. Se determina la clase aplicable al diseño actual, se listan las restricciones DFM vinculantes, y se identifican los componentes críticos que están en riesgo de violar dichos límites.

---

## 1. Determinación de la Clase de Fabricación

### 1.1 Parámetros del Diseño

| Parámetro de Diseño | Valor |
|---|---|
| Número de capas | 4 (Signal / GND / PWR / Signal) |
| Espesor total PCB | 1.6 mm |
| Via stitching drill | 0.3 mm |
| Via stitching pad | 0.6 mm (annular ring = 0.15 mm/lado) |
| Grosor de cobre en capas externas | 35 µm (1 oz, estándar) |
| Grosor de cobre en capas internas | 17–35 µm (½–1 oz, planos de cobre) |
| Microvías HDI | ❌ No — solo vias pasantes estándar |

### 1.2 Clase de Trabajo: **Clase 6** (confirmado)

La clase de fabricación ha sido confirmada como **Clase 6** para este proyecto. Con Clase 6:
- Drill mínimo metalizado: **0.20 mm** → el drill de 0.3 mm tiene margen del 50%.
- AR máximo: **8** → con PCB de 1.6 mm y drill 0.3 mm, AR = 5.33 cumple con margen.
- Capacidades HDI disponibles (microvías 0.075 mm) — **no usadas** en este diseño.

> [!IMPORTANT]
> **Clase 6 en Lab Circuits es la clase de fabricación de este proyecto.** Con esta clase, todos los parámetros del via stitching (0.3 mm drill) cumplen sin conflictos. Las capacidades mínimas de traza (0.150 mm en externas, 0.125 mm en internas para cobre de 35 µm) son más permisivas que Clase 4/5 y permiten rutar trazas impedance-controlled sin problemas.

### 1.3 Aspect Ratio — Verificación

El Aspect Ratio (AR) de un taladro pasante en PCB de 1.6 mm de grosor:

$$AR = \frac{\text{grosor PCB}}{\text{diámetro drill}} = \frac{1.6 \text{ mm}}{0.3 \text{ mm}} = 5.33$$

- **Clase 6 máximo AR: 8** → ✅ AR = 5.33 cumple con **margen del 33%**
- Clase 5 máximo AR: 6 → ✅ También cumple (dato de referencia)
- Clase 4 máximo AR: 5 → ❌ Excedido (dato histórico, no aplica)

> [!NOTE]
> El AR = 5.33 es cómodo para Clase 6 (límite = 8). No hay conflicto.

---

## 2. Restricciones DFM Vinculantes — Clase 6

### 2.1 Taladros

| Parámetro | Límite Clase 6 | Valor en Diseño | Estado |
|---|---|---|---|
| Drill mínimo metalizado | **0.20 mm** | 0.30 mm (via stitching) | ✅ 50% margen |
| Drill mínimo NO metalizado | **0.30 mm** | 3.5 mm (mounting holes) | ✅ |
| Aspect Ratio máximo | **8** | 5.33 (1.6mm/0.3mm) | ✅ Margen del 33% |

### 2.2 Trazas en Capas Externas (cobre 35 µm / 1 oz)

| Parámetro | Límite Clase 6 | Aplicación en Diseño | Estado |
|---|---|---|---|
| Ancho/espacio mínimo traza | **0.150 mm** | Trazas señal general: ≥ 0.2 mm | ✅ Margen 33% |
| Pares diferenciales (100 Ω Ethernet, 90 Ω USB) | 0.150 mm | Anchos calc. por stackup (orientativo: ~0.19–0.22 mm) | ✅ |

> [!NOTE]
> Con Clase 6, el mínimo de traza en capas externas es **0.150 mm** para cobre de 35 µm. Los anchos de traza impedance-controlled para Ethernet y USB (orientativamente 0.19–0.22 mm) cumplen holgadamente. Usar el Layer Stack Manager de Altium con los parámetros exactos del stackup de Lab Circuits para el cálculo final.

#### Cálculo orientativo de ancho de traza para 50 Ω (microstrip, cobre 35 µm, FR4 estándar 1.6 mm)

Para el stackup 4 capas (L1-Signal / L2-GND / L3-PWR / L4-Signal):
- Dieléctrico típico L1→L2: ≈ 0.36 mm (FR4 prepreg estándar)
- Ancho de traza para 50 Ω ≈ **0.63 mm** (microstrip exterior) → bien por encima del mínimo de 0.150 mm
- Ancho de traza para 100 Ω diferencial ≈ 2 × 0.19 mm con gap 0.2 mm → **dentro de límites Clase 6**
- Ancho de traza para 90 Ω diferencial (USB) ≈ 2 × 0.22 mm con gap 0.18 mm → **dentro de límites Clase 6**

### 2.3 Trazas en Capas Internas (cobre 35 µm / 1 oz, planos)

| Parámetro | Límite Clase 6 | Diseño | Estado |
|---|---|---|---|
| Ancho/espacio mínimo (35 µm) | **0.125 mm** | Rutado interno mínimo ≥ 0.15 mm | ✅ Margen |
| Ancho/espacio mínimo (17 µm) | 0.100 mm | Planos GND/PWR | ✅ |

### 2.4 Corona Mínima (Annular Ring)

La corona es la diferencia entre el radio del pad y el radio del drill:

$$\text{Corona} = \frac{D_{pad} - D_{drill}}{2}$$

Para el via de stitching con pad original (0.3 mm drill / 0.6 mm pad):

$$\text{Corona}_{orig} = \frac{0.6 - 0.3}{2} = 0.15 \text{ mm}$$

Para el via de stitching con pad recomendado (0.3 mm drill / **0.68 mm** pad):

$$\text{Corona}_{rec} = \frac{0.68 - 0.3}{2} = 0.19 \text{ mm}$$

| Capa | Límite Clase 6 | Corona pad 0.6 mm | Corona pad 0.68 mm | Estado |
|---|---|---|---|---|
| Capas externas | **0.10 mm** | 0.15 mm | 0.19 mm | ✅ Ambos cumplen |
| Capas internas señal | **0.15 mm** | **0.15 mm (= límite)** | **0.19 mm** | ⚠️ Pad 0.6 mm está en el límite exacto — recomendado 0.68 mm para margen |

> [!NOTE]
> Con **Clase 6** no hay conflicto de corona. El pad original de 0.6 mm cumple el mínimo (corona = 0.15 mm = límite interno exacto). Sin embargo, se mantiene el **pad de 0.68 mm** (corona = 0.19 mm) como valor recomendado para tener **27% de margen** sobre el límite interno y evitar rechazos por tolerancias de taladrado (±0.05 mm en drill).

### 2.5 Aislamiento entre Taladro Metalizado y Conductor

| Límite Clase 6 | Valor Diseño | Estado |
|---|---|---|
| **0.25 mm** | 0.65 mm clearance via-a-señal | ✅ Margen del 160% |

El clearance de 0.65 mm cumple holgadamente el requisito de Clase 6.

---

## 3. Verificación DFM Completa — Clase 6

✅ **No existen conflictos DFM en Clase 6.** Todos los parámetros del diseño cumplen los requisitos con margen.

| # | Parámetro | Valor Diseño | Límite Clase 6 | Estado | Margen |
|---|---|---|---|---|---|
| 1 | Aspect Ratio | 5.33 | ≤ 8 | ✅ | 33% |
| 2 | Drill via stitching | 0.3 mm | ≥ 0.20 mm | ✅ | 50% |
| 3 | Corona externas (pad 0.68 mm) | 0.19 mm | ≥ 0.10 mm | ✅ | 90% |
| 4 | Corona internas (pad 0.68 mm) | 0.19 mm | ≥ 0.15 mm | ✅ | 27% |
| 5 | Corona internas (pad 0.60 mm) | 0.15 mm | ≥ 0.15 mm | ⚠️ En límite | 0% |
| 6 | Aislamiento taladro-conductor | 0.65 mm | ≥ 0.25 mm | ✅ | 160% |
| 7 | Traza mínima ext. (35 µm) | 0.2 mm general | ≥ 0.150 mm | ✅ | 33% |
| 8 | Traza mínima int. (35 µm) | 0.15 mm mínimo | ≥ 0.125 mm | ✅ | 20% |

> [!IMPORTANT]
> **Conclusión DFM Clase 6:** El diseño cumple **todos** los requisitos de Lab Circuits Clase 6. La única situación a vigilar es la corona interna con el pad original de 0.6 mm (corona = 0.15 mm = límite exacto, margen cero). Se recomienda mantener el **pad en 0.68 mm** para absorber la tolerancia de taladrado (±0.05 mm de Lab Circuits).

---

## 4. Parámetros Verificados — Sin Problemas

| Parámetro | Valor Diseño | Límite Clase 6 | Estado |
|---|---|---|---|
| Drill mounting holes (3.5 mm) | 3.5 mm NO metalizado | ≥ 0.30 mm | ✅ Amplio margen |
| Clearance via-traza | 0.65 mm | ≥ 0.25 mm | ✅ |
| Ancho trazas señal general (≥ 0.2 mm) | ≥ 0.2 mm | 0.150 mm (ext., 35 µm) | ✅ Margen 33% |
| Ancho trazas diff (Ethernet/USB) | 0.19–0.22 mm | 0.150 mm | ✅ |
| Microvías HDI | No usadas | 0.075 mm disponible | ✅ (No aplica) |
| Resin filling vias | No requerido | Disponible | ✅ (No aplica) |

---

## 5. Tabla de Capacidades Completa de Lab Circuits — Referencia

### Taladros

| Parámetro | Clase 3 | Clase 4 | Clase 5 | Clase 6 | Clase 7 |
|---|:---:|:---:|:---:|:---:|:---:|
| Drill metalizado mínimo | 0.50 mm | 0.30 mm | 0.30 mm | 0.20 mm | 0.15 mm |
| Drill NO metalizado mínimo | 0.60 mm | 0.40 mm | 0.40 mm | 0.30 mm | 0.25 mm |
| Aspect Ratio máximo | 5 | 5 | 6 | 8 | 13 (PCB ≤ 2 mm) |

### Trazas — Capas Externas (por grosor cobre base)

| Grosor cobre | Clase 3 | Clase 4 | Clase 5 | Clase 6 | Clase 7 |
|---|:---:|:---:|:---:|:---:|:---:|
| 17 µm (½ oz) | 0.300 | 0.200 | 0.150 | 0.125 | 0.100 mm |
| 35 µm (1 oz) | 0.300 | 0.200 | 0.150 | 0.150 | — |
| 70 µm (2 oz) | 0.350 | 0.250 | 0.200 | 0.175 | — |
| 105 µm (3 oz) | 0.350 | 0.300 | 0.250 | 0.200 | — |

### Trazas — Capas Internas (por grosor cobre base)

| Grosor cobre | Clase 3 | Clase 4 | Clase 5 | Clase 6 | Clase 7 |
|---|:---:|:---:|:---:|:---:|:---:|
| 17 µm (½ oz) | 0.250 | 0.150 | 0.125 | 0.100 | 0.075 mm |
| 35 µm (1 oz) | 0.300 | 0.200 | 0.150 | 0.125 | 0.100 mm |
| 70 µm (2 oz) | 0.300 | 0.200 | 0.175 | 0.150 | — |
| 105 µm (3 oz) | 0.350 | 0.300 | 0.250 | 0.200 | — |

### Corona Mínima (Annular Ring)

| Capa | Clase 3 | Clase 4 | Clase 5 | Clase 6 | Clase 7 |
|---|:---:|:---:|:---:|:---:|:---:|
| Externas | 0.22 mm | 0.17 mm | 0.13 mm | 0.10 mm | 0.075 mm |
| Internas (señal) | 0.25 mm | 0.22 mm | 0.19 mm | 0.15 mm | 0.125 mm |

### Aislamiento entre Taladro Metalizado y Conductor

| Clase 3 | Clase 4 | Clase 5 | Clase 6 | Clase 7 |
|:---:|:---:|:---:|:---:|:---:|
| 0.40 mm | 0.40 mm | 0.30 mm | 0.25 mm | 0.20 mm |

### Microvías HDI

| Parámetro | Clase 5 | Clase 6 | Clase 7 |
|---|:---:|:---:|:---:|
| Diámetro mínimo microvía | 0.10 mm | 0.075 mm | 0.075 mm |
| Grosor aislante máximo | 0.10 mm | 0.065 mm | 0.065 mm |
| Pad superior | 0.35 mm | 0.30 mm | 0.25 mm |
| Pad inferior | 0.30 mm | 0.25 mm | 0.25 mm |
| Pared mínima microvía ↔ taladro pasante | 0.22 mm | 0.15 mm | 0.10 mm |
| Pared mínima entre microvías | 0.23 mm | 0.15 mm | 0.10 mm |
| Pared mínima entre microvías 2 niveles | 0.23 mm | 0.15 mm | 0.10 mm |

---

## 6. Impacto sobre el Via Stitching — Estado con Clase 6

El artículo [Via Stitching & GND Guard Rings](Via_Stitching_GND_Guard_Rings.md) usa vias de **0.3 mm drill / 0.68 mm pad**. Con Clase 6, este pad es correcto y tiene buen margen:

| Parámetro | Valor en Diseño | Límite Clase 6 | Estado | Margen |
|---|---|---|---|---|
| Drill | 0.3 mm | ≥ 0.20 mm | ✅ | 50% |
| Pad | 0.68 mm | N/A (solo drill y corona) | ✅ | — |
| Corona externas | 0.19 mm | ≥ 0.10 mm | ✅ | 90% |
| Corona internas | 0.19 mm | ≥ 0.15 mm | ✅ | 27% |
| Clase de fabricación | — | **Clase 6** | ✅ confirmado | — |

> [!NOTE]
> El pad original de 0.6 mm también cumple Clase 6 (corona int. = 0.15 mm = límite). Se mantiene el pad de **0.68 mm** para absorber la tolerancia de taladrado de Lab Circuits (±0.05 mm).

---

## 7. Reglas DRC para Altium — Clase 6

| Regla | Valor | Motivo |
|---|---|---|
| Via drill (stitching) | **0.3 mm** | Compatible con Clase 6 (mín. 0.20 mm) |
| Via pad (stitching) | **0.68 mm** (recomendado) | Corona internas = 0.19 mm (27% margen sobre mínimo 0.15 mm) |
| Clase de fabricación en Gerber | **Clase 6** | Confirmado por proyecto |
| Minimum Annular Ring (outer) | **0.10 mm** (límite Clase 6) | DRC check rule |
| Minimum Annular Ring (inner) | **0.15 mm** (límite Clase 6) | DRC check rule |
| Hole-to-conductor clearance | **0.65 mm** | ≥ 0.25 mm (Clase 6) — sin cambio |
| Traza mínima ext. (35 µm) | **0.150 mm** | Límite Clase 6 |
| Traza mínima int. (35 µm) | **0.125 mm** | Límite Clase 6 |

---

## See Also

- [Via Stitching & GND Guard Rings](Via_Stitching_GND_Guard_Rings.md) — Via geometry affected by DFM constraints
- [Hardware Architecture](Hardware_Architecture.md) — PCB stackup: 4 layers, 1.6 mm, Lab Circuits
- [Design Audit 2026-06-10](Design_Audit_2026-06-10.md) — Pre-production audit reference
- [PCB Design Course Index](../theory/PCB_Design_Course_Index.md) — Block 5: DFM & Manufacturing

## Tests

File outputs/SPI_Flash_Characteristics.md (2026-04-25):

# SPI Flash Memory IC: SST25VF040B Characteristics

The **SST25VF040B** is a 4 Mbit (512K x 8) Serial Flash memory device, ideal for applications requiring high-performance and low power consumption.

## 🔑 Key Specifications
- **Capacity:** 4 Megabits (512 Kilobytes).
- **Interface:** Standard 4-wire Serial Peripheral Interface (SPI) - Mode 0 and Mode 3 supported.
- **Clock Frequency:** Up to 50 MHz.
- **Operating Voltage:** 2.7 V to 3.6 V (Single Supply).
- **Power Consumption:**
    - Active Read: 10 mA (typical at 33 MHz).
    - Standby: 5 µA (typical).

## 🛠 Memory Organization
- **Uniform Sector Erase:** 4 KByte sectors.
- **Uniform Block Erase:** 32 KByte and 64 KByte blocks.
- **Programming:** Page-by-page (not supported), Auto Address Increment (AAI) Word-Program for fast production.

## 📐 Physical & Environmental
- **Package Options:** 8-lead SOIC (150 mil), 8-contact WSON (6mm x 5mm).
- **Temperature Range:** 
    - Industrial: -40°C to +85°C.
- **Endurance:** 100,000 cycles (typical).
- **Data Retention:** >100 years.

## 📍 Pinout (SOIC-8)
| Pin | Name | Function |
| :--- | :--- | :--- |
| 1 | **CE#** | Chip Enable (Active Low). |
| 2 | **SO** | Serial Data Output. |
| 3 | **WP#** | Write Protect. |
| 4 | **VSS** | Ground. |
| 5 | **SI** | Serial Data Input. |
| 6 | **SCK** | Serial Clock. |
| 7 | **HOLD#** | Hold (pauses serial communication). |
| 8 | **VDD** | Power Supply (3.3V typical). |

## 🔗 Implementation Notes
- **Decoupling:** Place a 0.1 µF ceramic capacitor as close as possible to the VDD pin.
- **Pull-ups:** A pull-up resistor (10k $\Omega$) is recommended on the **CE#** line to ensure the device is disabled during MCU reset/startup.
- **Write Protect:** Tie **WP#** and **HOLD#** to VDD if hardware write protection or communication pausing is not required.

[Source: Industry Standard SST25VF040B Datasheet]

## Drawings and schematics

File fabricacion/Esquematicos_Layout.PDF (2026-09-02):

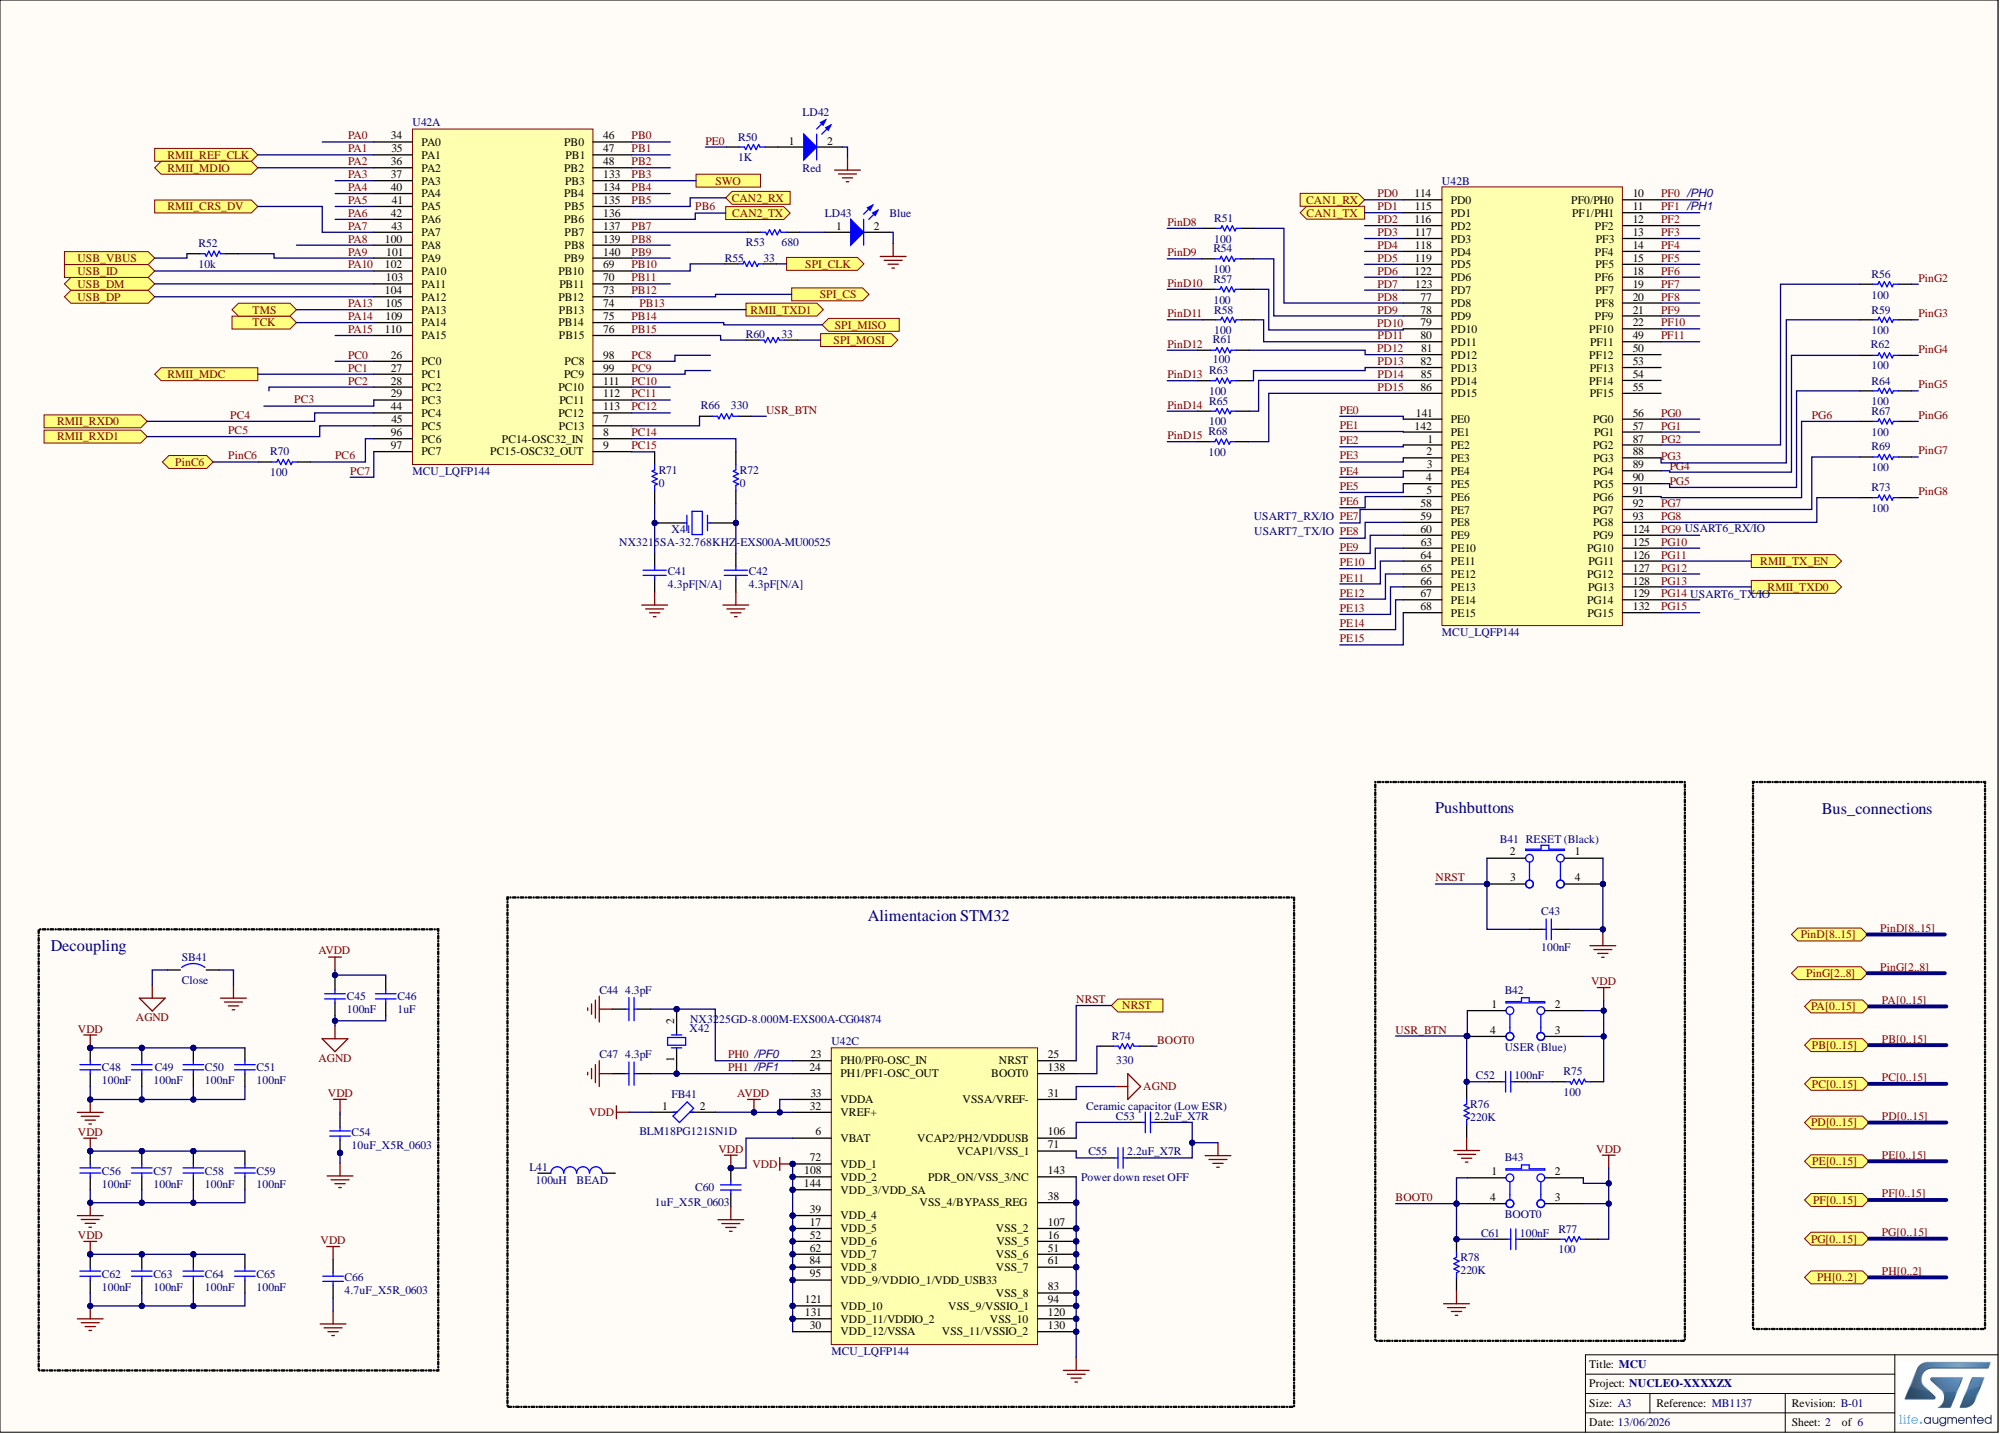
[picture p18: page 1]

PD9 | PD9 78
PD10 | PD10 79
PD11 | PD11 80

PC4 | PC5 45
PC5 | PC6 96 | PC14

PE5 | PE6 5
PE6 | PE7 58
PE7 | PE8 59 | PG8
PE8 | PE9 60
PE9 | PE10 63

PE11 64
PE12 65

PE11 | PE13 66
PE12 | PE14 67
PE13 | PE15 68

Ceramic capacitor (Low ESR)

Power down reset OFF

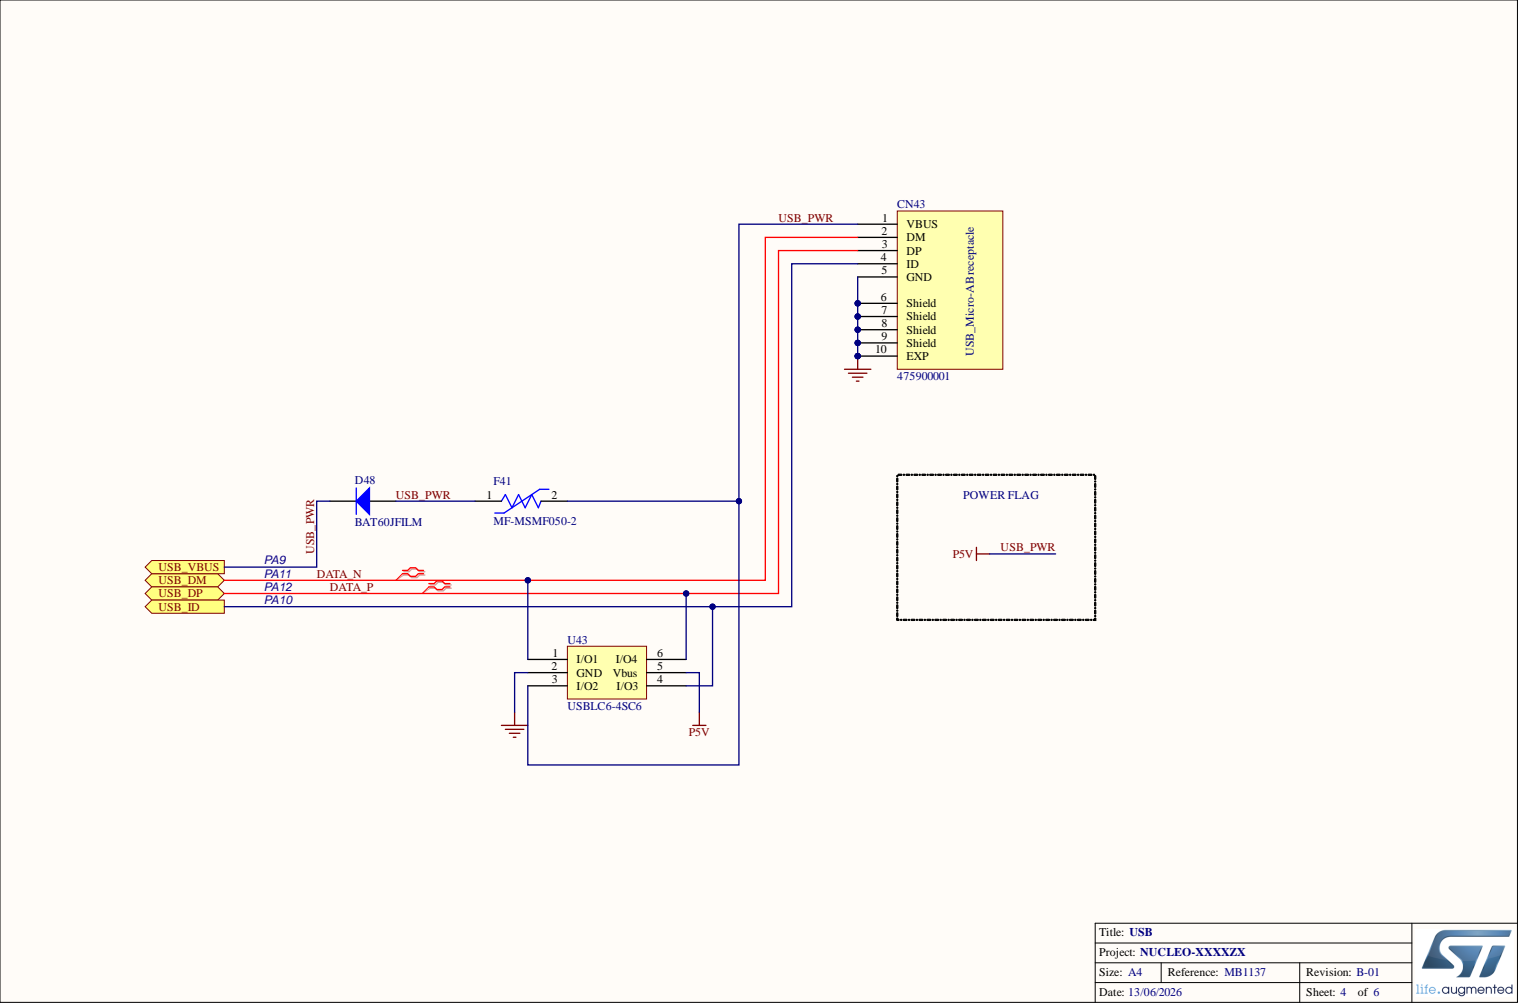
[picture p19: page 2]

DM 2
DP 3
ID 4
GND 5

PA12 DATA_P
PA10

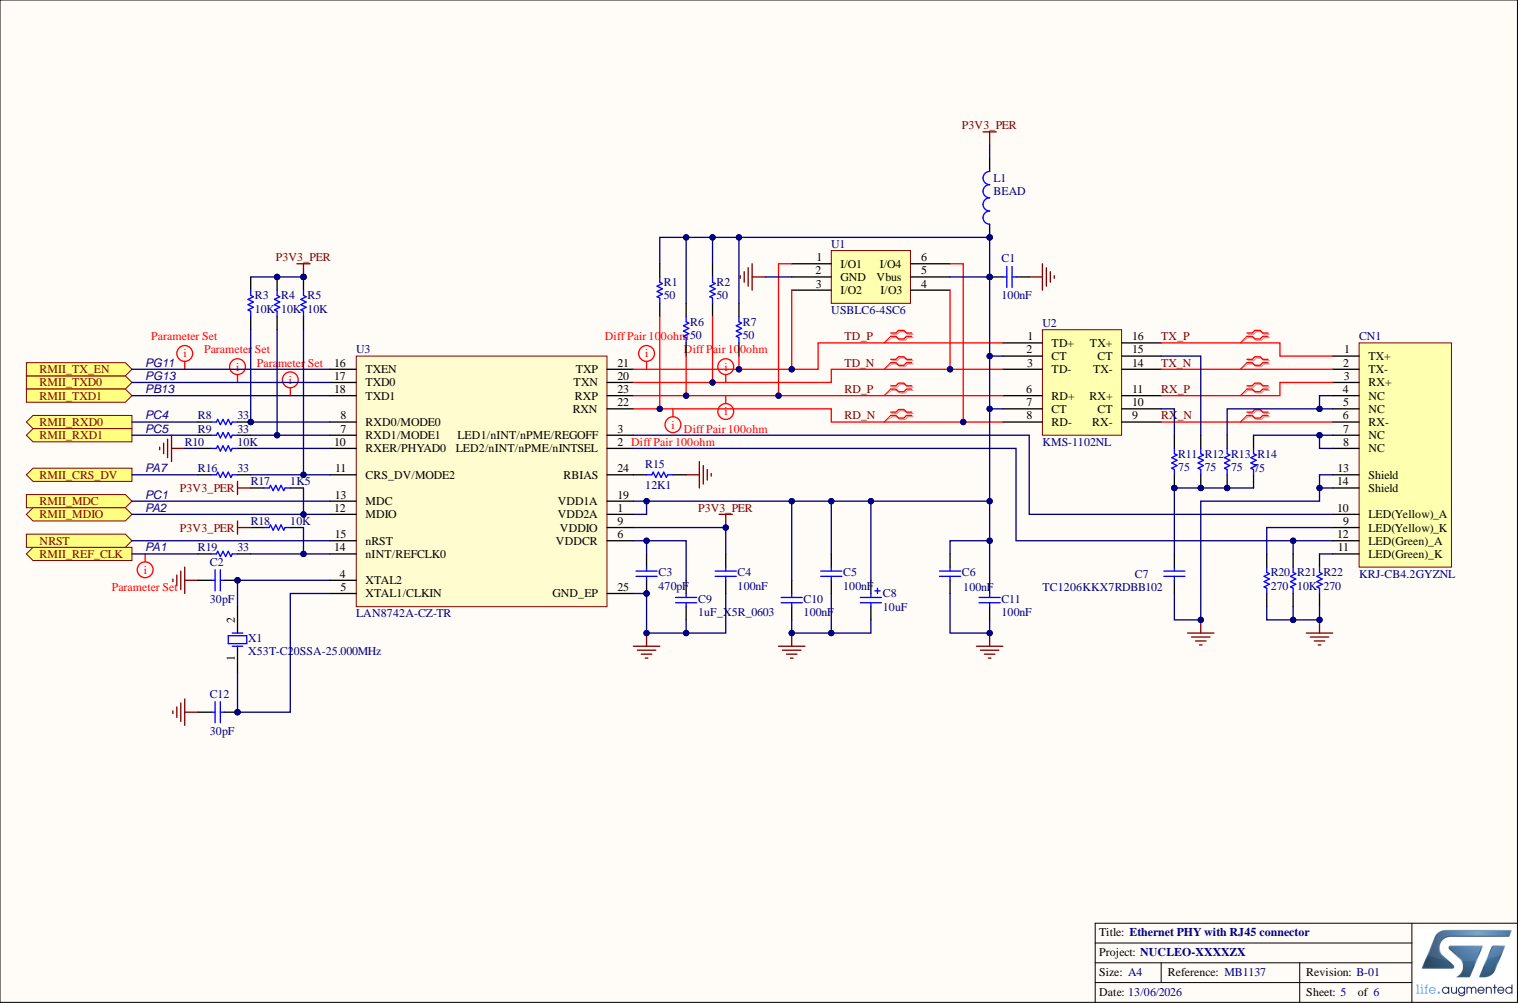
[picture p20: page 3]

1 | P3 V 3 _ PE R

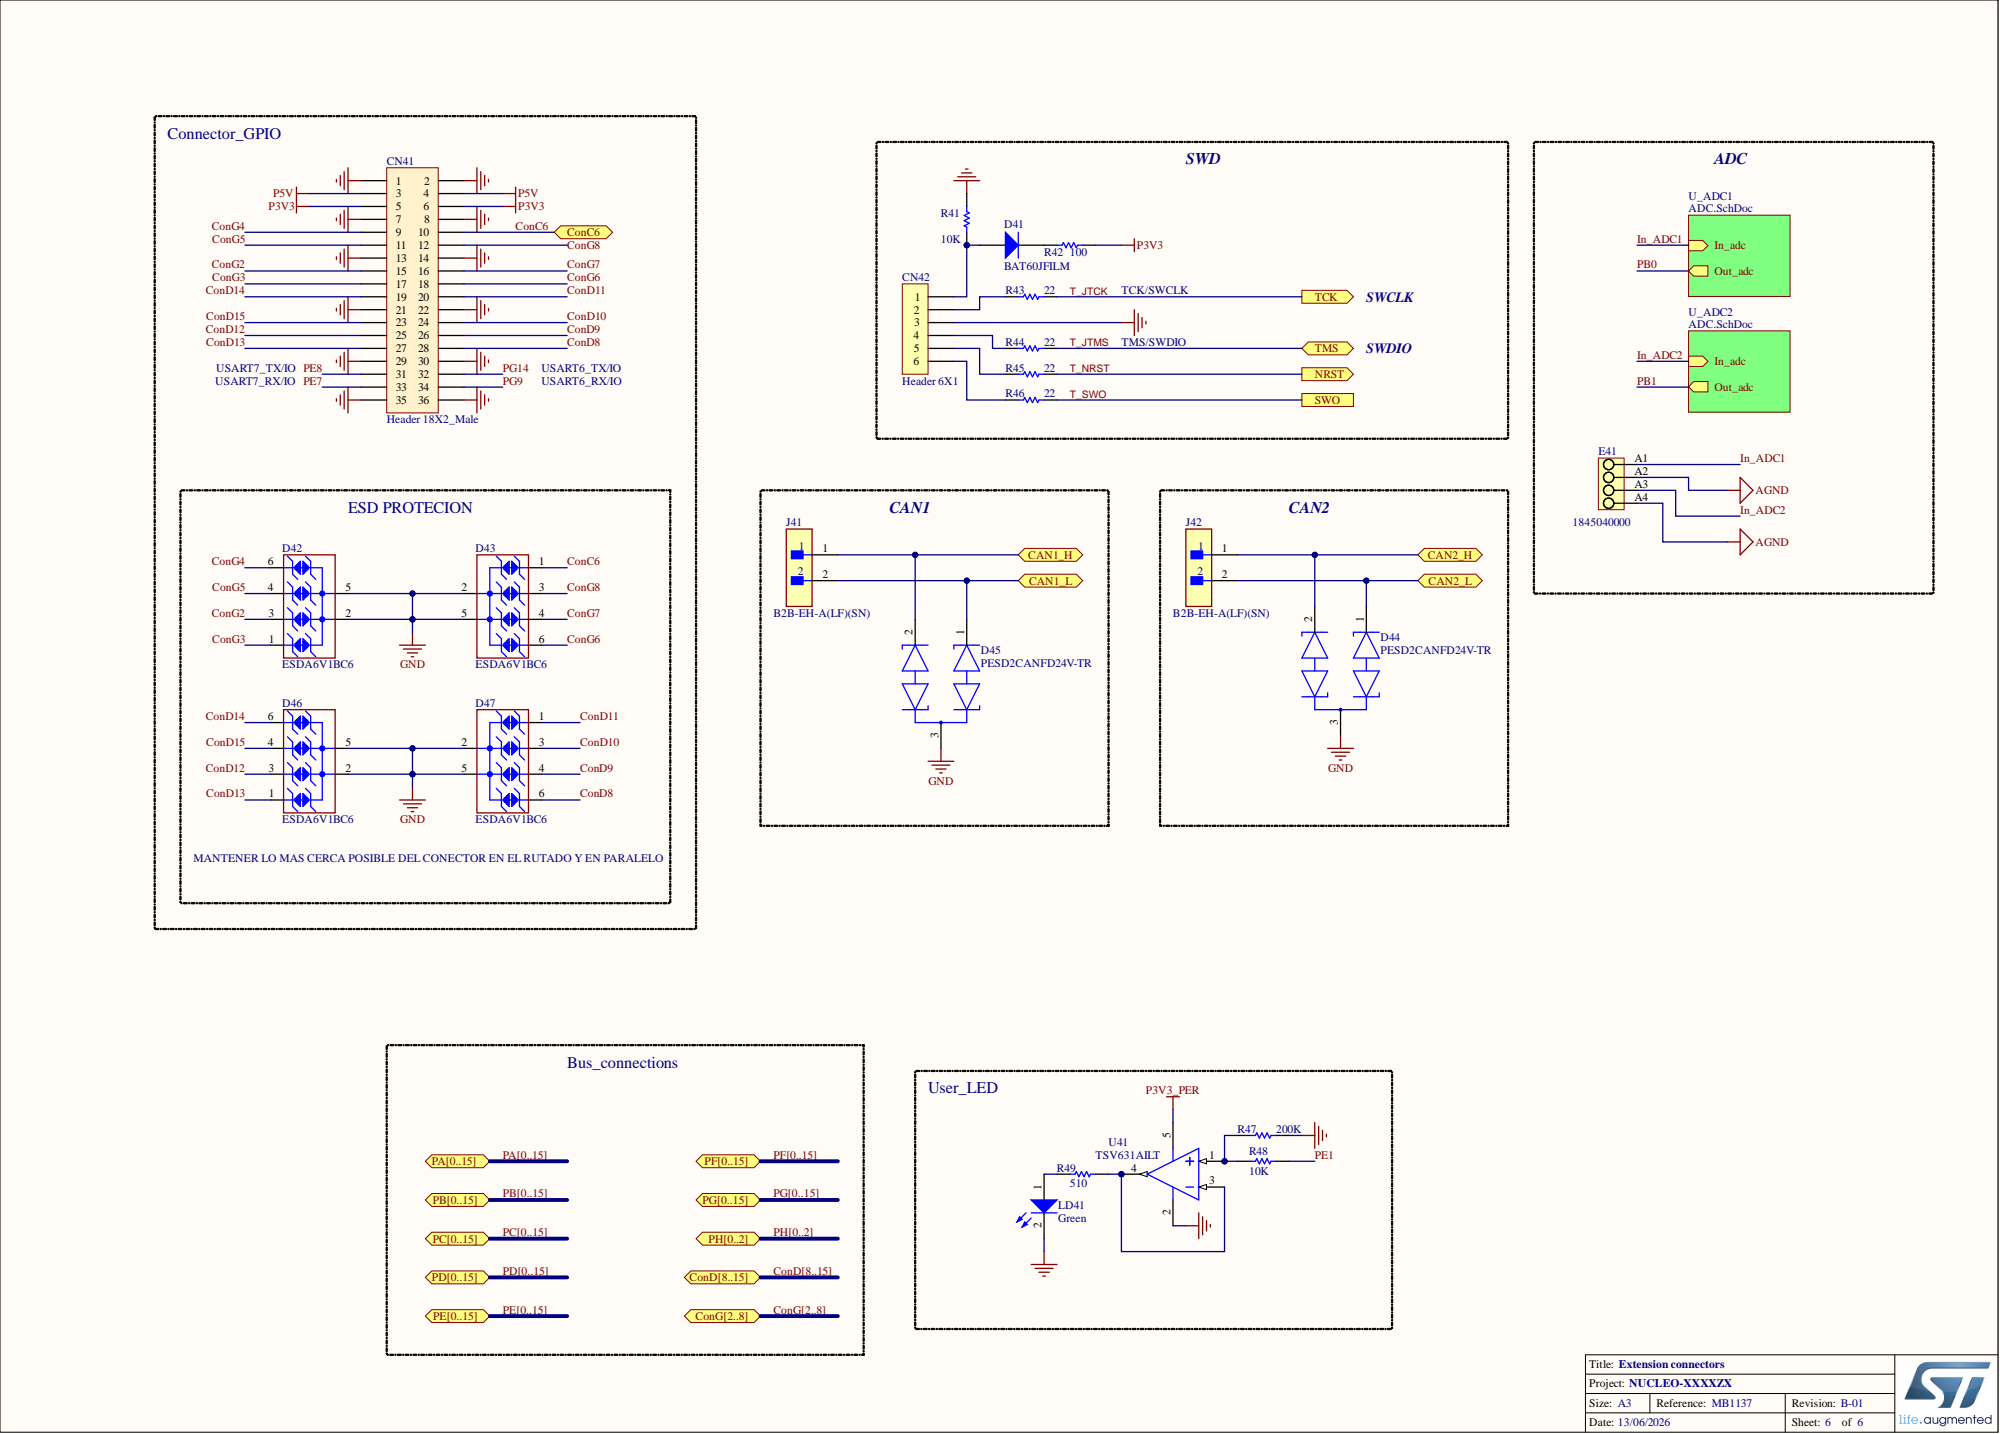
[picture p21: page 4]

MANTENER LO MAS CERCA POSIBLE DEL CONECTOR EN EL RUTADO Y EN PARALELO

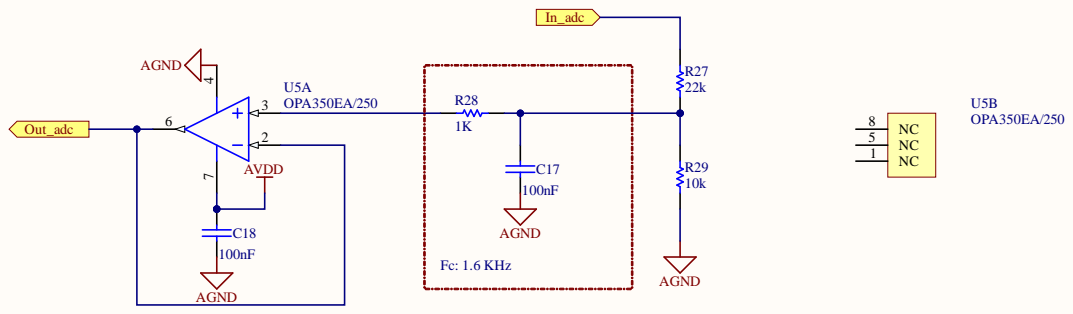
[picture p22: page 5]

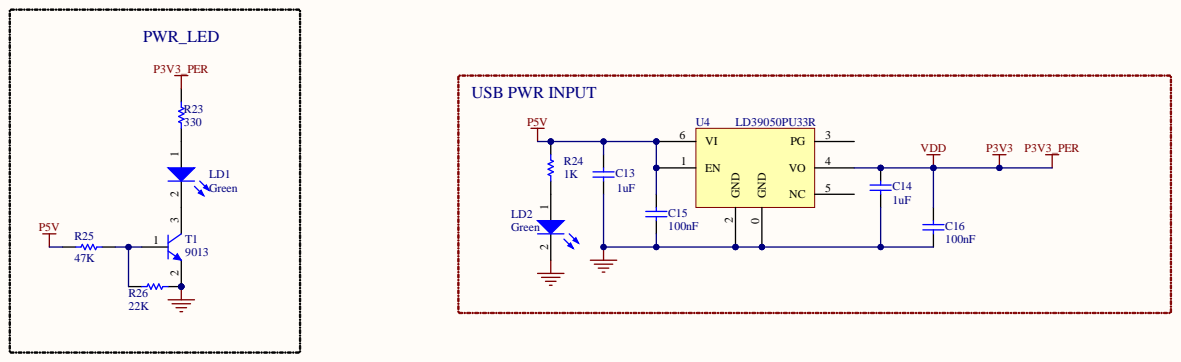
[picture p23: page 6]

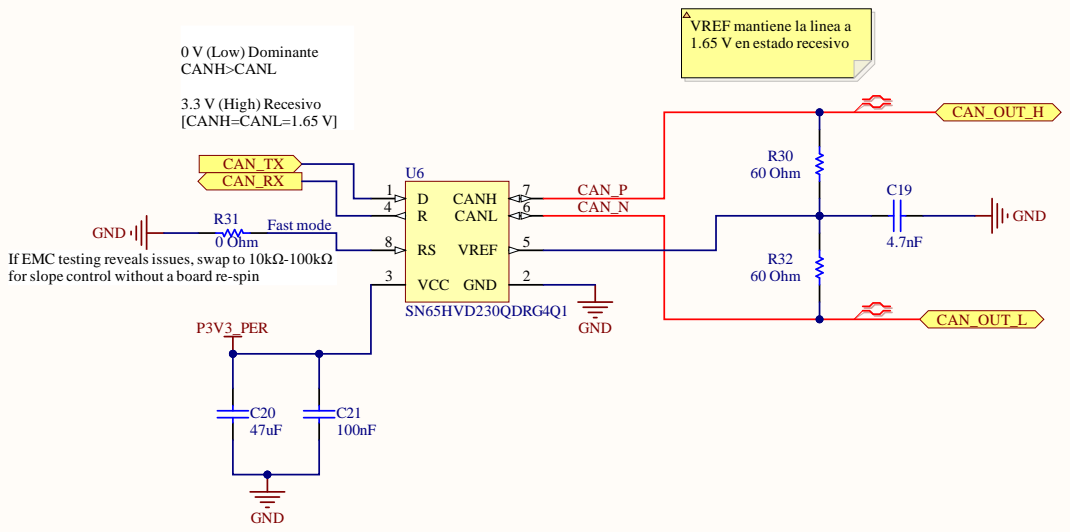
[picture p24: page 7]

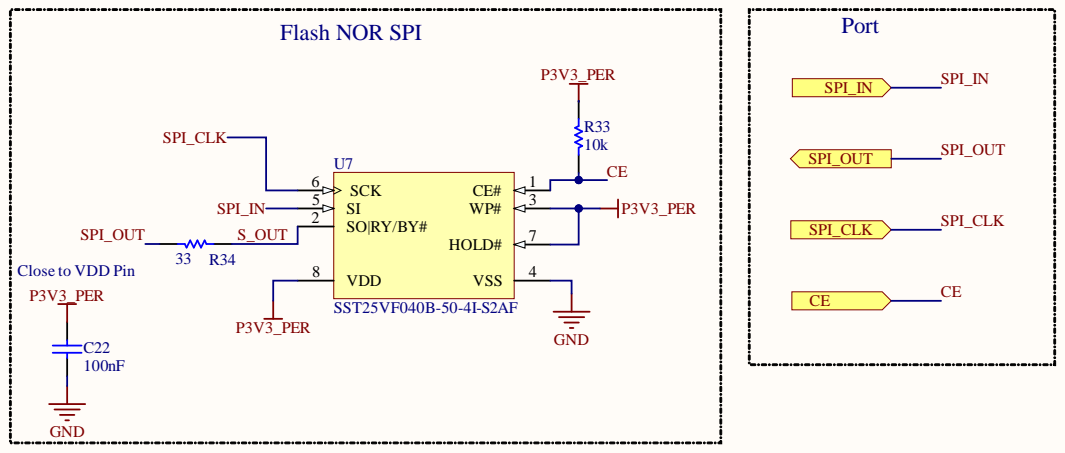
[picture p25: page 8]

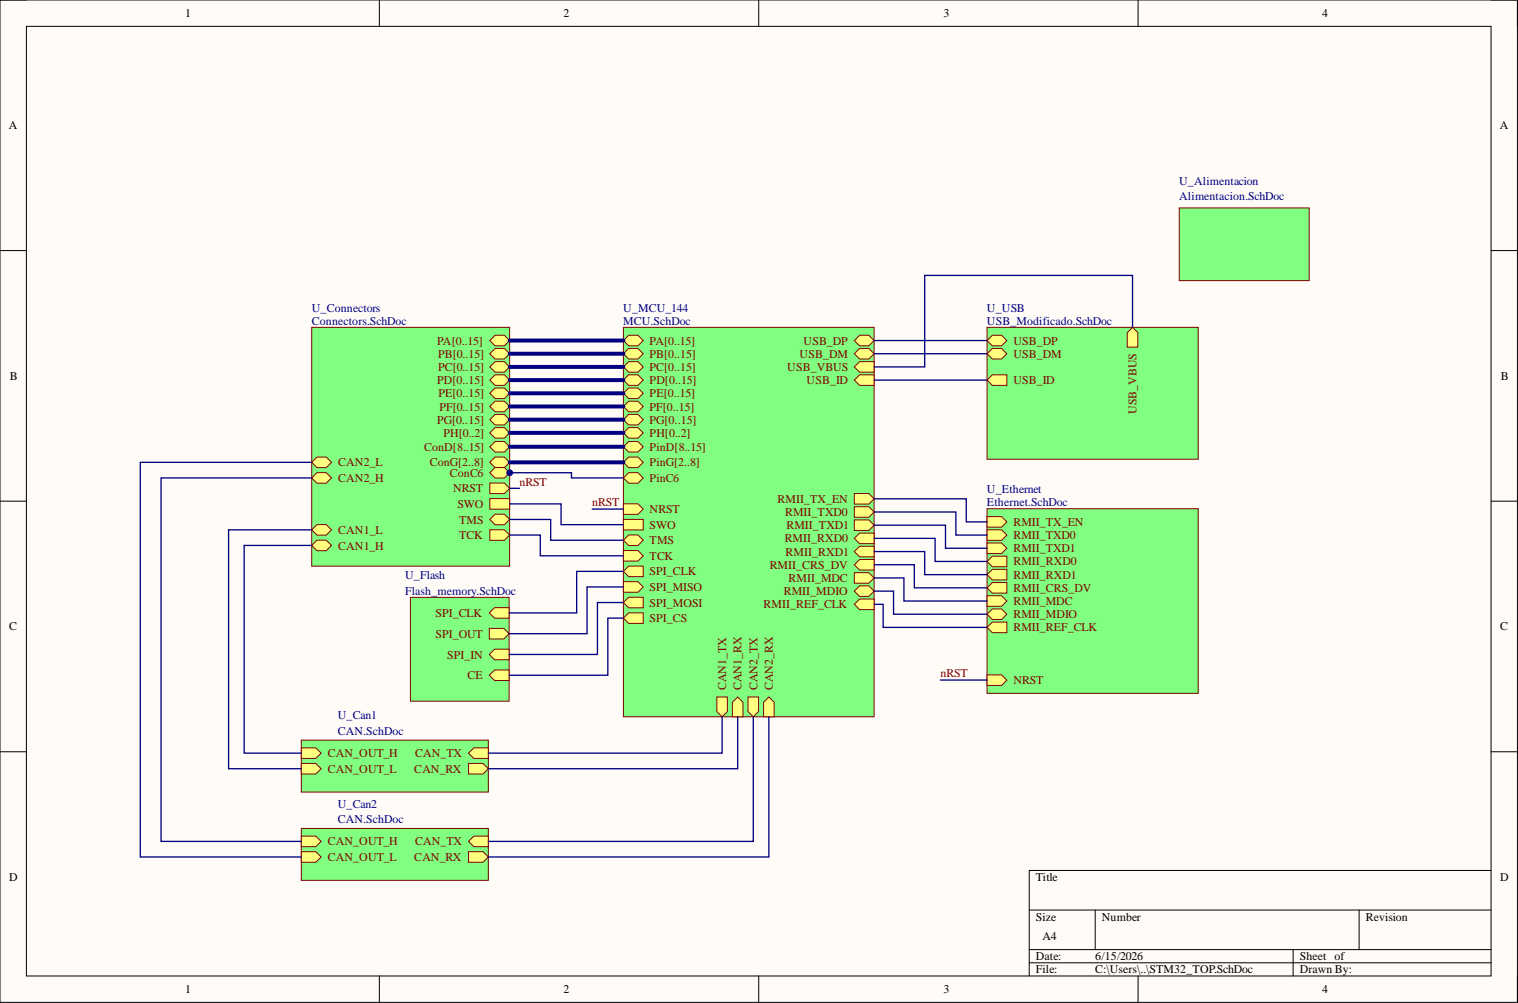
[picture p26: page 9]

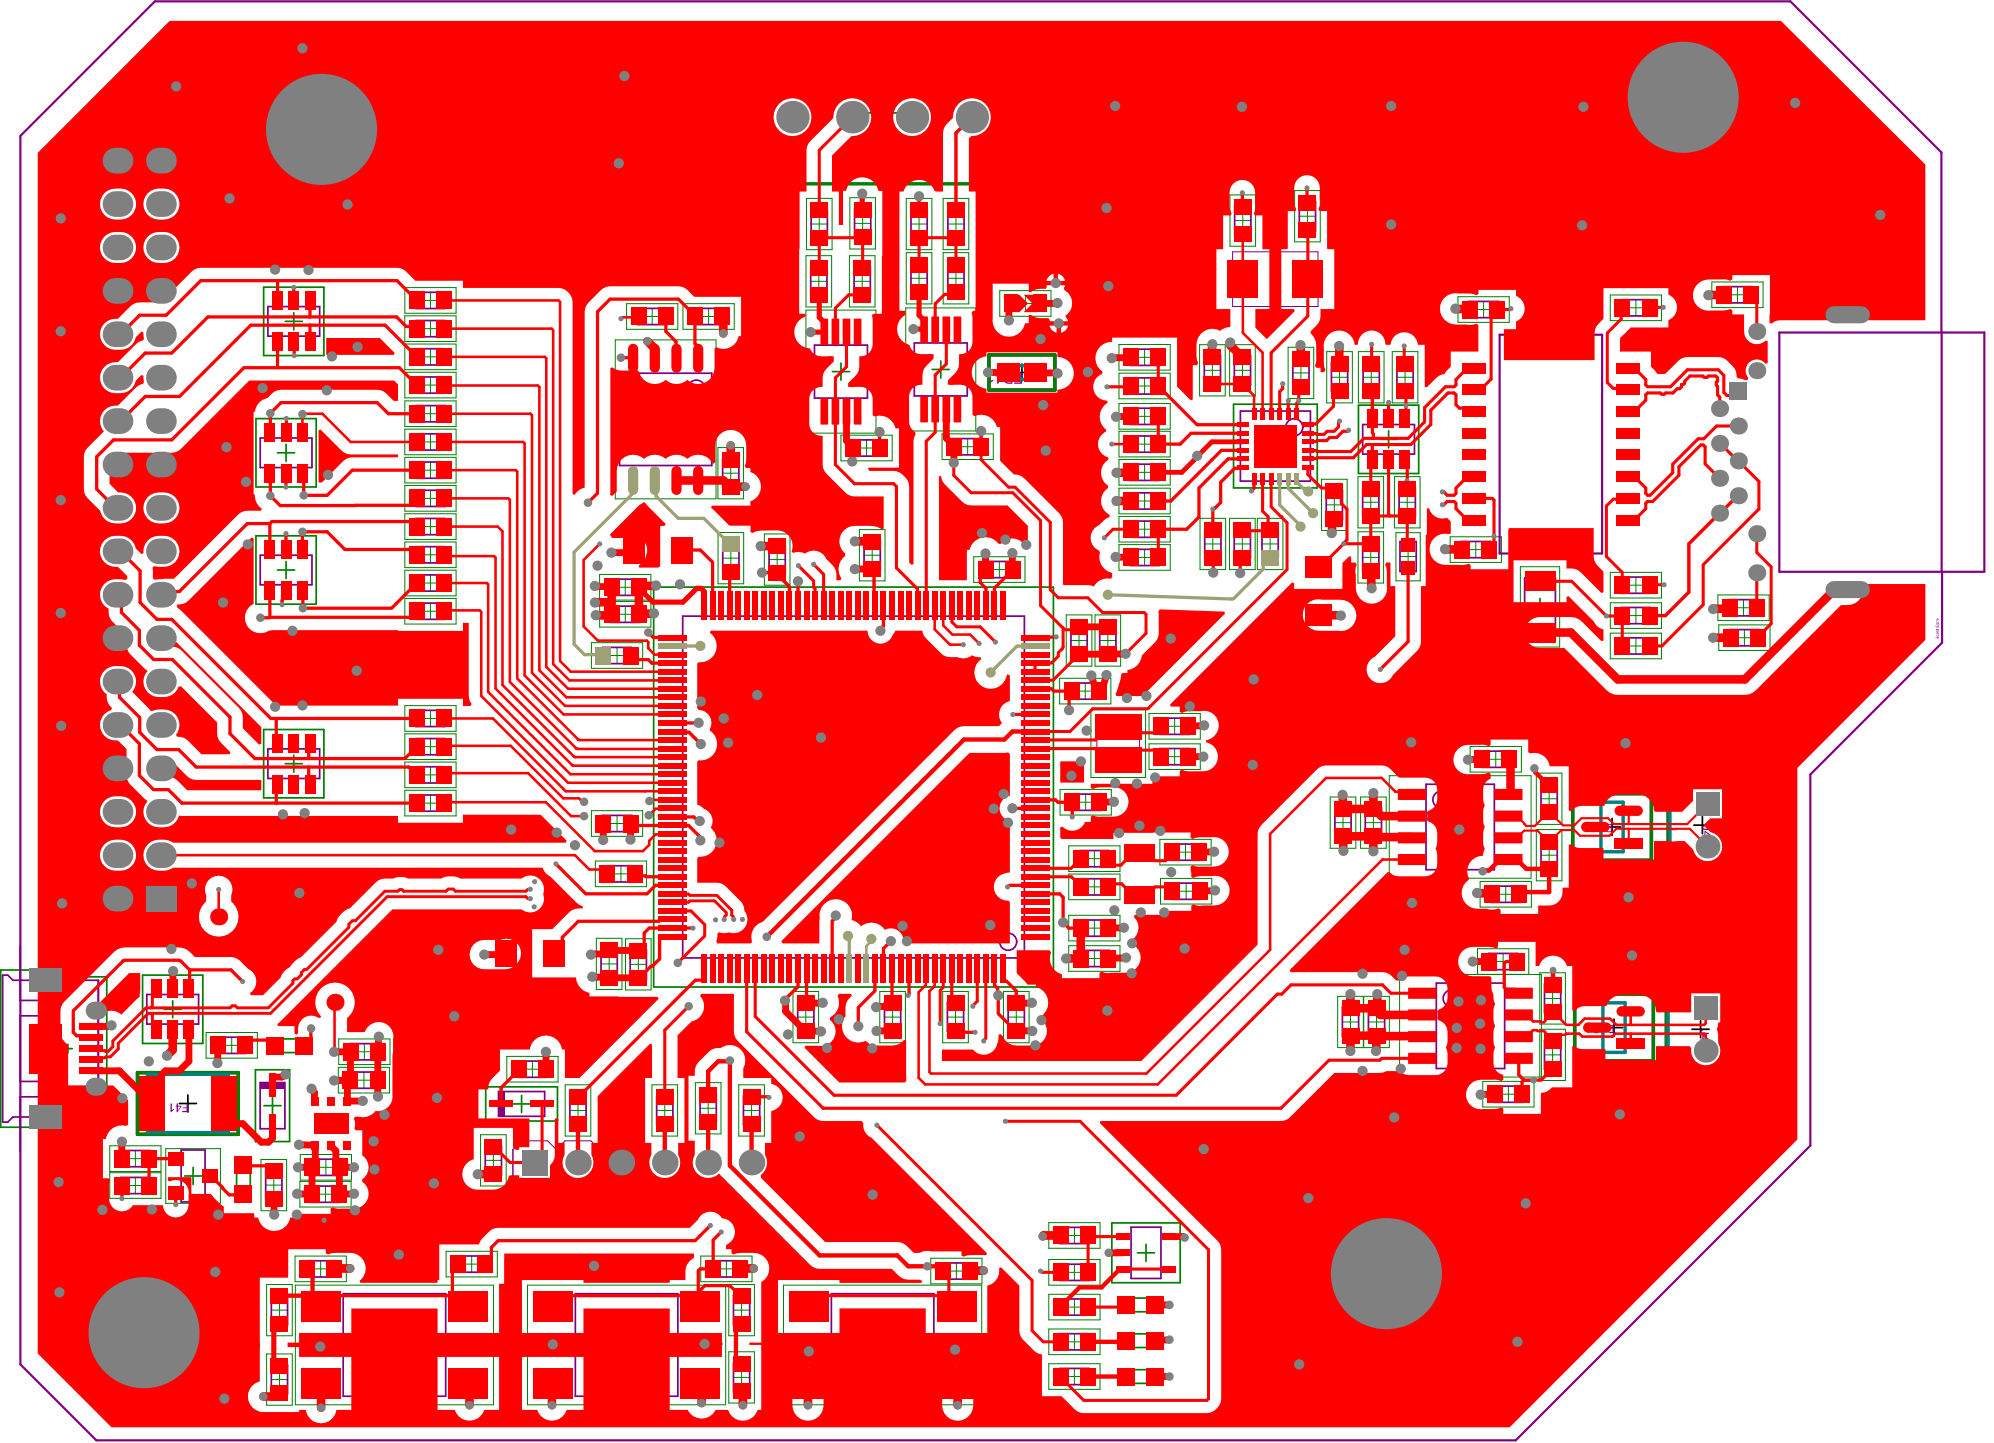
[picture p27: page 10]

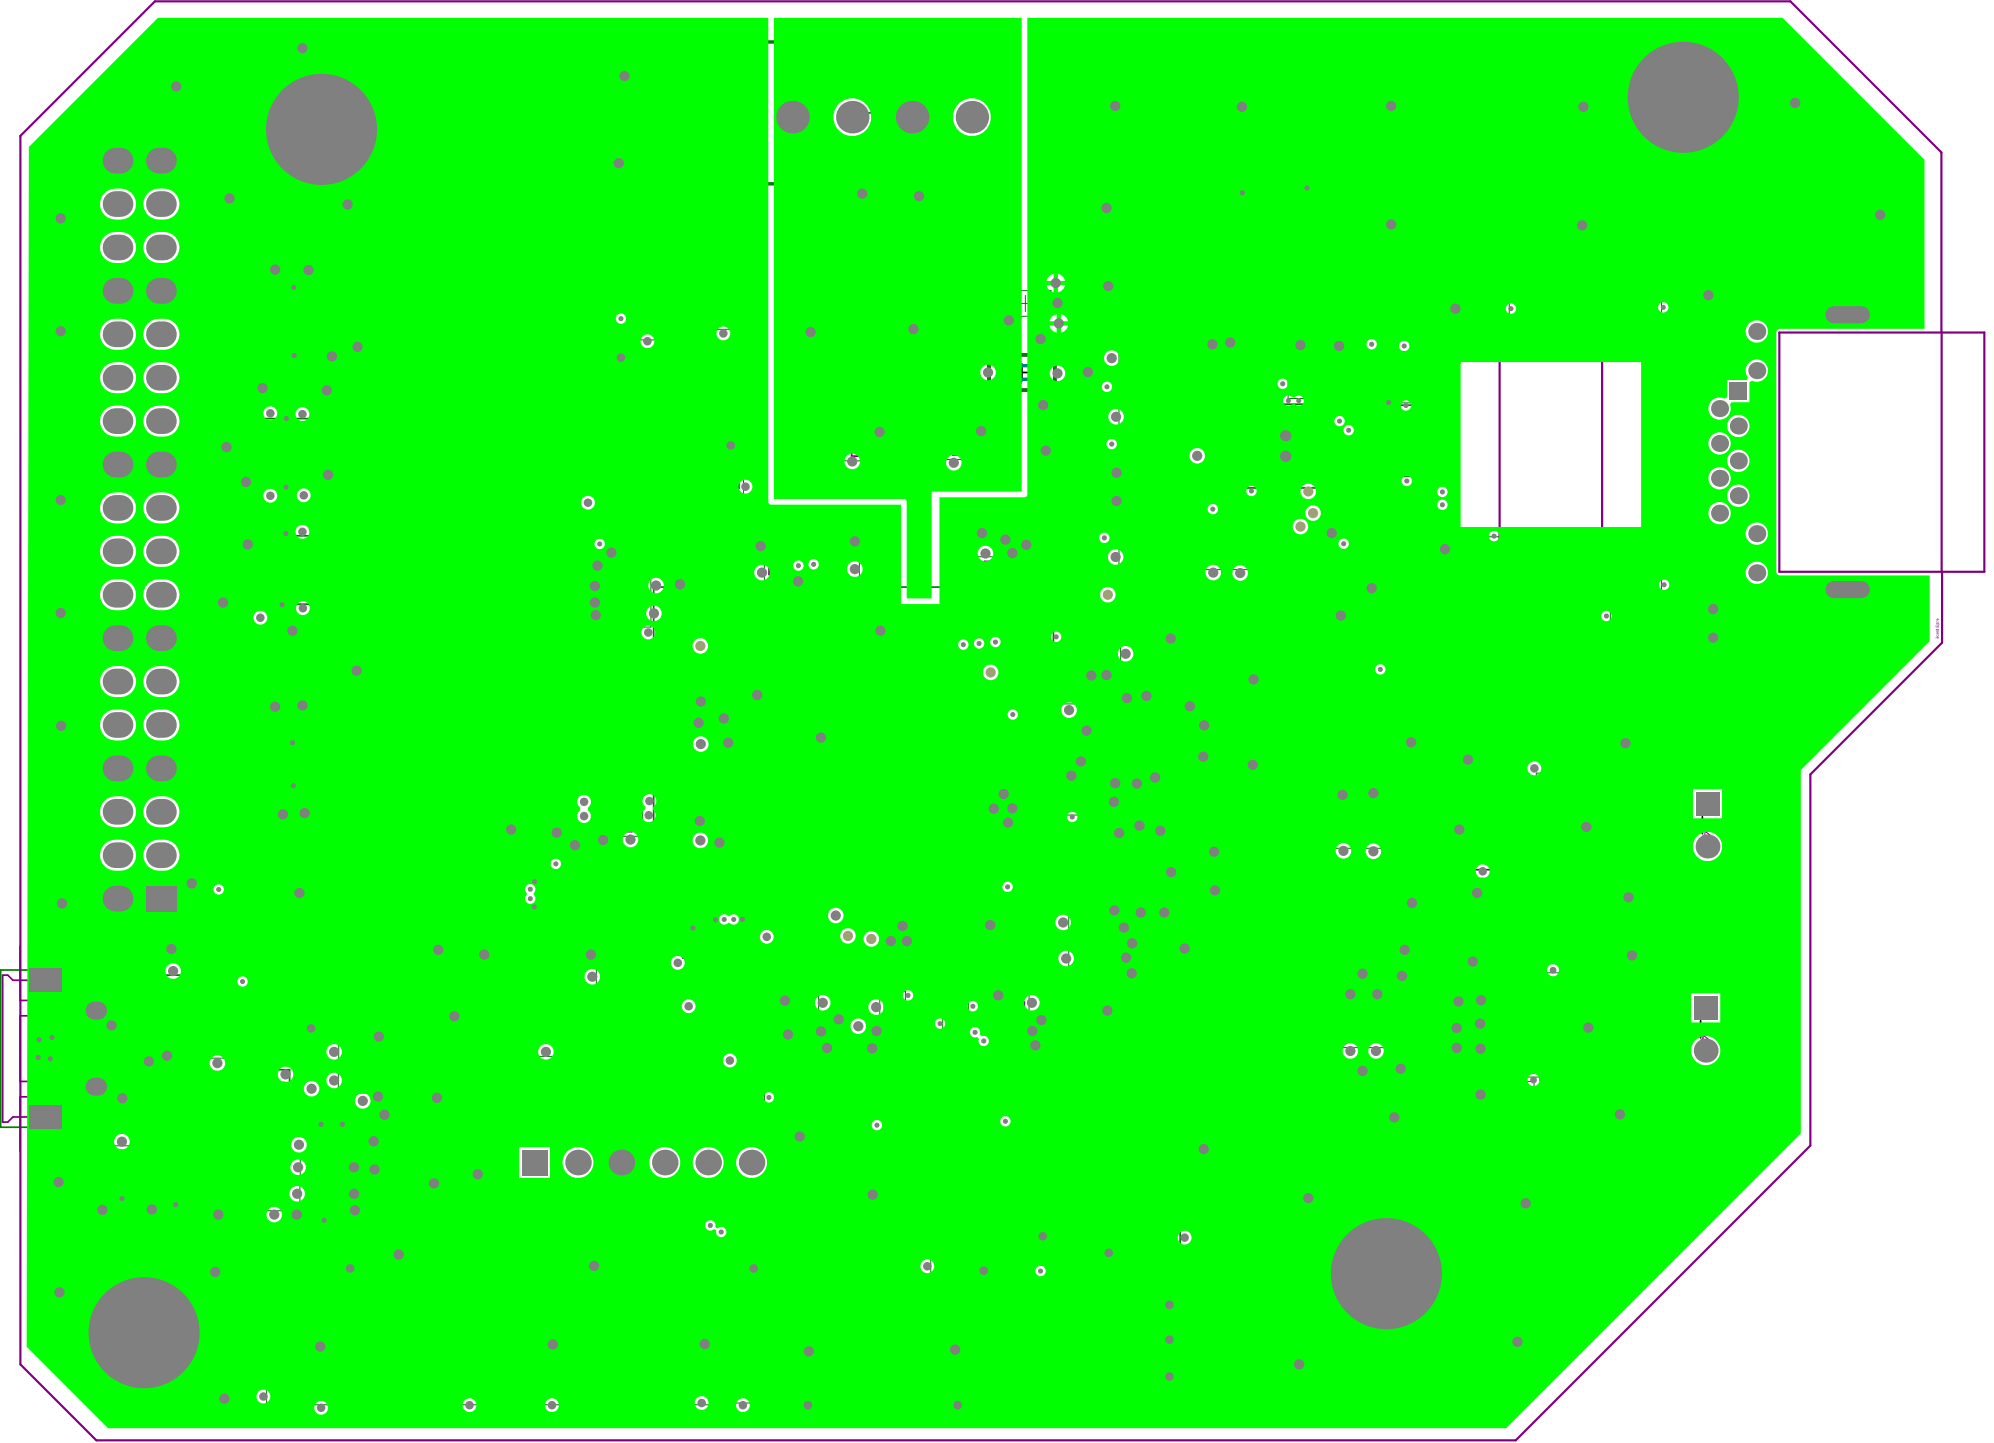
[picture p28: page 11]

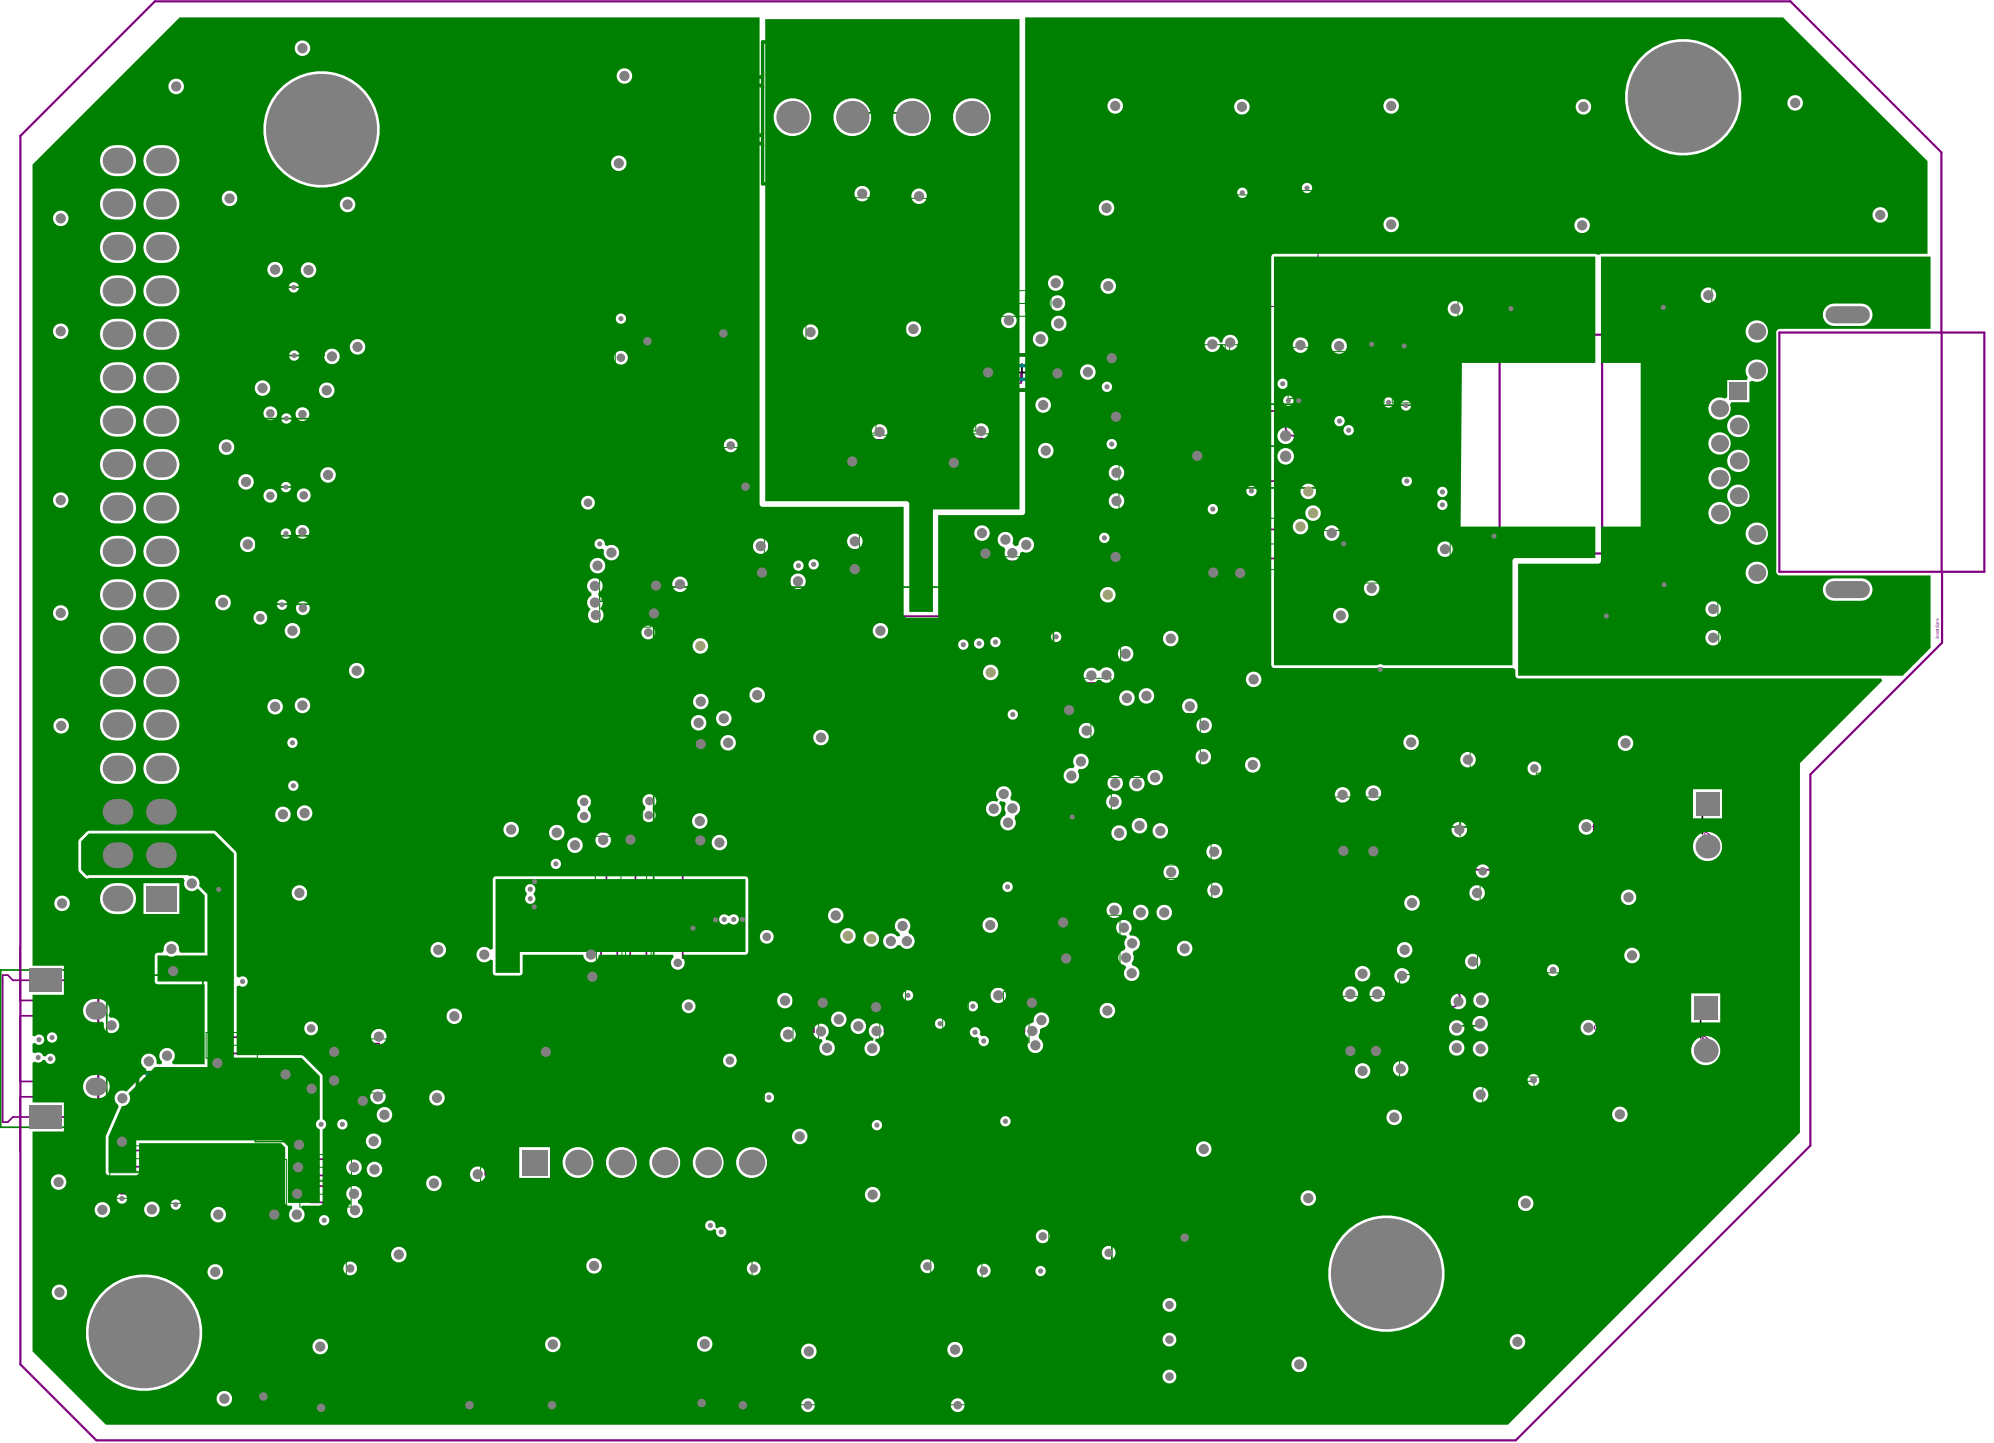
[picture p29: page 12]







Stack Up | Layer Stack
Layer | Board Layer Stack | Name | Material | Thickness | Constant | Color
1 | | Top Overlay | | 0mm
2 | | Top Solder | SM-001 | 0.0254mm | 4 #FF008000
3 | | Top Surface Finish | Gold | 0.004mm | | #FFFFB200
4 | | Top Layer | CF-004 | 0.0175mm
5 | | Dielectric 1 | PP-004 | 0.06604mm | 3.8
6 | | Dielectric 2 | PP-006 | 0.07112mm | 4.1
7 | | Int1 (GND) | CF-004 | 0.035mm
8 | | Dielectric 3 | Core-039 | 1.1mm | 4.8
9 | | Int2 (PWR) | CF-004 | 0.035mm
10 | | Dielectric 4 | PP-006 | 0.07112mm | 4.1
11 | | Dielectric 5 | PP-004 | 0.06604mm | 3.8
12 | | Bottom Layer | CF-004 | 0.0175mm
13 | | Bottom Surface Finish | Gold | 0.004mm | | #FFFFB200
14 | | Bottom Solder | SM-001 | 0.0254mm | 4 #FF008000
15 | | Bottom Overlay | | 0mm

Height : 1.53812mm




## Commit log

2026-02-11 Adición de ficheros placa STM32
    Añado los ficheros de descarga de la placa que especifica el profesor en pracitcas
    [Connectors.SchDoc, Ethernet.SchDoc, MB1137.PcbLib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]
2026-02-11 Creacion del gitignore
    Creacion de plantilla para gitignore con Gemini
2026-02-11 Primer commit
    Primer commit de raul
2026-02-13 Compilacion del proyecto
    Cambios al compilar el proyecto en altium, no hacer caso
2026-04-18 Sistema informacion
    [Connectors.SchDoc, Ethernet.SchDoc, MB1137.PcbLib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]
2026-06-10 docs: actualiza wiki con componentes, tecnologias y metodos de los planos
2026-06-10 docs: corrige formato de articulos y enlaces cruzados segun karpathy
2026-06-10 refactor: reorganiza directorio raw en subcarpetas de tipo de documento
2026-06-10 docs: añade auditoria de diseño y articulo de teoria pdn
2026-06-10 docs: corrige desacoplo de ldo y marca issues pdn como resueltos
2026-06-10 docs: corrige desacoplo de vbat y marca issue como falso positivo
2026-06-10 docs: corrige l41 de vdda y añade ferrita blm18 a base de datos
2026-06-10 docs: añade datasheet de la ferrita blm18pg121sn1d
2026-06-10 docs: vincula el nuevo datasheet en metadatos de componentes y pdn
2026-06-10 docs: corrige proteccion esd usb y actualiza tabla de auditoria
2026-06-10 docs: corrige capacitor de filtro de modo comun de can
2026-06-10 docs: corrige control de pendiente de transceptores can
2026-06-10 docs: añade archivos de teoria de pcb en raw/teory
2026-06-10 docs: añade indice tematico de teoria de pcb en la wiki
2026-06-10 refactor: deja de trackear la carpeta raw y la añade a gitignore
2026-06-10 refactor: añade .obsidian a gitignore y deja de trackear sus archivos de estado
2026-06-10 docs: formatea tabla de auditoría en markdown
2026-06-13 docs: consolida estado final de la wiki antes de crear rama de informe
2026-06-13 fix: corrige titulo de subsubseccion de pines de usb
2026-06-13 docs: expande la seccion de introduccion con detalles de arquitectura
2026-06-13 docs: corrige y detalla la seccion del microcontrolador
2026-06-13 docs: actualiza seccion del adc con calculos del divisor y buffer
2026-06-13 refactor: mueve imagenes de la raiz a subcarpeta y actualiza rutas
2026-06-13 docs: detalla la seccion de comunicacion can
2026-06-13 docs: corrige topografia y descripcion de la seccion del adc
2026-06-13 docs: corrige la descripcion de la terminacion dividida de can
2026-06-13 docs: actualiza control de pendiente del transceptor can
2026-06-13 docs: detalla la seccion de micro-usb y sus protecciones
2026-06-13 docs: detalla la resistencia de sensado de vbus en usb
2026-06-13 fix: corrige nombre del archivo de imagen del stackup
2026-06-13 docs: remueve figura de calculo de par diferencial usb
2026-06-13 docs: detalla la seccion de alimentacion y red pdn
2026-06-13 docs: detalla la seccion de red ethernet y su par diferencial
2026-06-13 docs: detalla el stack-up de 4 capas y la tabla de impedancia controlada
2026-06-13 docs: completa analisis de integridad de senal reglas drc y conclusiones
2026-06-13 docs: añade seccion de emplazado de componentes e inserta la figura correspondiente
2026-06-13 refactor: optimiza el ancho y alto de las tablas para evitar desbordamientos
2026-06-14 docs: corrige la descripción de la terminación can en el informe
2026-06-14 docs: añade vistas 3d de la placa y corrige conectores y stack-up
2026-09-02 refactor: reorganiza estructura del proyecto pcb, esquematicos e informe
    [ADC.SchDoc, Alimentacion.SchDoc, Bill of Materials-STM32_PCB.csv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]
2026-09-02 docs: actualiza readme con la estructura completa del proyecto
2026-09-02 docs: añade badges de tecnologias al readme
